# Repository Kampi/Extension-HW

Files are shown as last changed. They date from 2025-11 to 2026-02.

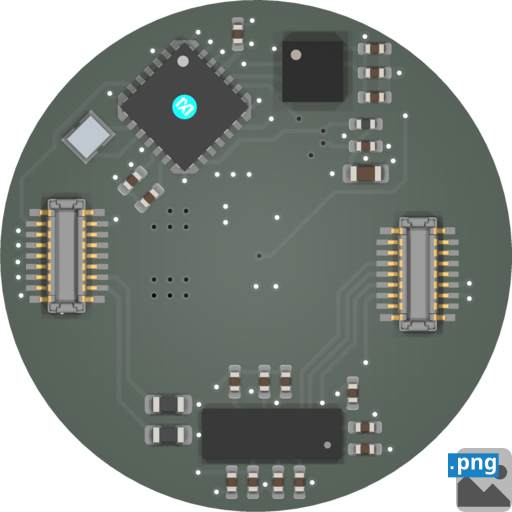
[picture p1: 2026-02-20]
production/extension-RELEASED/HTML/images/cat_png_3d_viewer_top_ZSWatch-Extension-top.png

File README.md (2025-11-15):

# ZSWatch-DevKit



## 📑 Table of Contents

- [ZSWatch-DevKit](#zswatch-devkit)
  - [📑 Table of Contents](#-table-of-contents)
  - [📖 About](#-about)
  - [📂 Directory Breakdown](#-directory-breakdown)
  - [Purchasing](#purchasing)
  - [👨‍💻 Maintainer](#-maintainer)

## 📖 About

The **ZSWatch-DevKit** project provides the hardware design and production files for a heartrate board tailored to the ZSWatch ecosystem.
It is built with **KiCad** and integrates a full **CI/CD pipeline** using **KiBot**, ensuring reproducible outputs for documentation, manufacturing, and releases.

Key features:

- 🛠️ Open-source hardware design
- 📦 Automated generation of Gerber, BoM, and documentation via KiBot
- 🔄 Workflow stages (DRAFT → PRELIMINARY → CHECKED → RELEASED) for structured releases
- 📝 Clear documentation and changelog to track progress
- 🌍 Designed with collaboration and transparency in mind

Please check the [wiki](https://github.com/ZSWatch/ZSWatch/wiki) for more information about the project.

## 📂 Directory Breakdown

- **`.github`**: GitHub related files
- **`.gitignore`**: Ignored files list
- **`devkit`**: KiCad project for the devkit
- **`production`**: Manufacturing outputs (Gerbers, documentation, etc.)
- **`CHANGELOG.md`**: Version history
- **`LICENSE`**: Project license (GPL-3.0)
- **`README.md`**: Project overview

## Purchasing

TBD

## 👨‍💻 Maintainer

- [Daniel Kampert](mailto:danielkameprt@kampis-elektroecke.de)

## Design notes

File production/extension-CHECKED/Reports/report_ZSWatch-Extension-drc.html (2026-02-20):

Logo

| DRC report for ZSWatch-Extension
| PCB: ZSWatch-Extension Revision: + (Unreleased) Date: 2026-02-20T15:14:23+0000 KiCad Version: 9.0.7 | Errors: 3 Warnings: 37 Total: 40

Violations

Type | Description | Details
clearance | Clearance violation (netclass 'Default' clearance 0.1000 mm; actual 0.0497 mm) | @(201.606169 mm, 143.268723 mm): Via [Net-(IC501-CS_{ACC})] on F.Cu - B.Cu @(200.402944 mm, 145.224264 mm): PCB text '+ (Unreleased)' on B.Cu
shorting_items | Items shorting two nets (nets and Net-(IC501-CS_{ACC})) | @(200.402944 mm, 145.224264 mm): PCB text '+ (Unreleased)' on B.Cu @(199.412994 mm, 147.487006 mm): Polygon [Net-(IC501-CS_{ACC})] on B.Cu
clearance | Clearance violation (netclass 'Default' clearance 0.1000 mm; actual 0.0000 mm) | @(200.402944 mm, 145.224264 mm): PCB text '+ (Unreleased)' on B.Cu @(182.7 mm, 132.5 mm): Zone [GND] on B.Cu, priority 8
lib_footprint_issues | The current configuration does not include the footprint library 'Amphenol'. | @(210.3 mm, 150.6 mm): Footprint X702
lib_footprint_mismatch | Footprint 'C_0201_0603Metric' does not match copy in library 'Capacitor_SMD'. | @(205.725 mm, 157.425 mm): Footprint C603
lib_footprint_mismatch | Footprint 'C_0201_0603Metric' does not match copy in library 'Capacitor_SMD'. | @(208.8925 mm, 143.2 mm): Footprint C505
lib_footprint_mismatch | Footprint 'C_0201_0603Metric' does not match copy in library 'Capacitor_SMD'. | @(208.175 mm, 154.505 mm): Footprint C608
lib_footprint_mismatch | Footprint 'L_0201_0603Metric' does not match copy in library 'Inductor_SMD'. | @(208.6 mm, 145.675 mm): Footprint R502
lib_footprint_mismatch | Footprint 'C_0201_0603Metric' does not match copy in library 'Capacitor_SMD'. | @(201.5 mm, 148.1 mm): Footprint C504
lib_footprint_mismatch | Footprint 'C_0201_0603Metric' does not match copy in library 'Capacitor_SMD'. | @(208.8925 mm, 143.993 mm): Footprint C506
lib_footprint_mismatch | Footprint 'C_0201_0603Metric' does not match copy in library 'Capacitor_SMD'. | @(200.941835 mm, 147.529739 mm): Footprint C502
lib_footprint_mismatch | Footprint 'C_0201_0603Metric' does not match copy in library 'Capacitor_SMD'. | @(204.4 mm, 142.72 mm): Footprint C503
lib_footprint_mismatch | Footprint 'C_0201_0603Metric' does not match copy in library 'Capacitor_SMD'. | @(205.975 mm, 154.125 mm): Footprint C602
lib_footprint_mismatch | Footprint 'L_0402_1005Metric' does not match copy in library 'Inductor_SMD'. | @(202.125001 mm, 154.875 mm): Footprint FB601
lib_footprint_issues | The current configuration does not include the footprint library 'Crystal_Kampi'. | @(199.5 mm, 146.1 mm): Footprint Y501
lib_footprint_mismatch | Footprint 'C_0402_1005Metric' does not match copy in library 'Capacitor_SMD'. | @(208.6 mm, 147.3 mm): Footprint C511
lib_footprint_issues | The current configuration does not include the footprint library 'Analog Devices'. | @(202.653033 mm, 145.111434 mm): Footprint IC501
lib_footprint_issues | The current configuration does not include the footprint library 'Package_BGA_Kampi'. | @(205.525 mm, 155.835 mm): Footprint IC601
lib_footprint_mismatch | Footprint 'C_0201_0603Metric' does not match copy in library 'Capacitor_SMD'. | @(206.425 mm, 157.425 mm): Footprint C604
lib_footprint_mismatch | Footprint 'L_0402_1005Metric' does not match copy in library 'Inductor_SMD'. | @(202.125001 mm, 155.875 mm): Footprint FB602
lib_footprint_mismatch | Footprint 'C_0201_0603Metric' does not match copy in library 'Capacitor_SMD'. | @(208.574999 mm, 156.345 mm): Footprint C610
lib_footprint_mismatch | Footprint 'LGA-12_2x2mm_P0.5mm' does not match copy in library 'Package_LGA'. | @(206.8625 mm, 143.95 mm): Footprint IC502
lib_footprint_mismatch | Footprint 'C_0201_0603Metric' does not match copy in library 'Capacitor_SMD'. | @(208.8925 mm, 144.793 mm): Footprint C507
lib_footprint_mismatch | Footprint 'C_0201_0603Metric' does not match copy in library 'Capacitor_SMD'. | @(204.2 mm, 157.425 mm): Footprint C606
lib_footprint_mismatch | Footprint 'C_0201_0603Metric' does not match copy in library 'Capacitor_SMD'. | @(204.3 mm, 154.125 mm): Footprint C601
lib_footprint_mismatch | Footprint 'C_0201_0603Metric' does not match copy in library 'Capacitor_SMD'. | @(205.275 mm, 154.125 mm): Footprint C605
lib_footprint_issues | The current configuration does not include the footprint library 'Amphenol'. | @(198.8 mm, 150.0 mm): Footprint X701
lib_footprint_mismatch | Footprint 'C_0201_0603Metric' does not match copy in library 'Capacitor_SMD'. | @(208.6 mm, 146.4 mm): Footprint C510
lib_footprint_mismatch | Footprint 'C_0201_0603Metric' does not match copy in library 'Capacitor_SMD'. | @(208.575 mm, 155.625 mm): Footprint C609
lib_footprint_mismatch | Footprint 'C_0201_0603Metric' does not match copy in library 'Capacitor_SMD'. | @(204.9 mm, 157.425 mm): Footprint C607
lib_footprint_mismatch | Footprint 'C_0201_0603Metric' does not match copy in library 'Capacitor_SMD'. | @(208.7 mm, 145.8 mm): Footprint C508
lib_footprint_mismatch | Footprint 'C_0201_0603Metric' does not match copy in library 'Capacitor_SMD'. | @(209.98 mm, 154.7 mm): Footprint C611
lib_footprint_issues | The current configuration does not include the footprint library 'Vishay'. | @(202.2 mm, 150.0 mm): Footprint D501
lib_footprint_mismatch | Footprint 'R_0201_0603Metric' does not match copy in library 'Resistor_SMD'. | @(209.98 mm, 155.5 mm): Footprint R601
lib_footprint_mismatch | Footprint 'R_0201_0603Metric' does not match copy in library 'Resistor_SMD'. | @(203.1 mm, 146.4 mm): Footprint R501
lib_footprint_mismatch | Footprint 'C_0201_0603Metric' does not match copy in library 'Capacitor_SMD'. | @(202.15 mm, 146.4 mm): Footprint C501
lib_footprint_mismatch | Footprint 'C_0201_0603Metric' does not match copy in library 'Capacitor_SMD'. | @(204.755 mm, 146.0 mm): Footprint C509
lib_footprint_issues | The current configuration does not include the footprint library 'Osram'. | @(205.0 mm, 150.0 mm): Footprint LED501
lib_footprint_issues | The current configuration does not include the footprint library 'Package_BGA_Kampi'. | @(206.8 mm, 146.1 mm): Footprint IC503
lib_footprint_issues | The current configuration does not include the footprint library 'Vishay'. | @(207.8 mm, 150.0 mm): Footprint D502

Generated by KiBot (https://github.com/INTI-CMNB/KiBot/) v1.8.5

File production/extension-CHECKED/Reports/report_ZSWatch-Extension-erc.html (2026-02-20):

Logo

| ERC report for ZSWatch-Extension
| Schematic: ZSWatch-Extension Revision: + (Unreleased) Date: 2026-02-20T15:14:21+0000 KiCad Version: 9.0.7 | Errors: 0 Warnings: 22 Total: 22

Sheet / (ZSWatch-Extension.kicad_sch)

Type | Description | Details
unresolved_variable | Unresolved text variable | @(0.2032 mm, 0.3175 mm): Text Box
unresolved_variable | Unresolved text variable | @(0.2286 mm, 0.3556 mm): Text Box
unresolved_variable | Unresolved text variable | @(0.8636 mm, 0.3175 mm): Text Box
unresolved_variable | Unresolved text variable | @(0.889 mm, 0.3556 mm): Text Box
unresolved_variable | Unresolved text variable | @(1.524 mm, 0.3175 mm): Text Box
unresolved_variable | Unresolved text variable | @(1.5494 mm, 0.3556 mm): Text Box
unresolved_variable | Unresolved text variable | @(2.1844 mm, 0.3175 mm): Text Box
unresolved_variable | Unresolved text variable | @(2.2098 mm, 0.3556 mm): Text Box
footprint_link_issues | The current configuration does not include the footprint library 'Crystal_Kampi'. | @(0.5715 mm, 0.8001 mm): Symbol Y501 [Crystal]
footprint_link_issues | The current configuration does not include the footprint library 'Analog Devices'. | @(0.8001 mm, 0.7112 mm): Symbol IC501 [MAX32664-SPI-TQFN]
lib_symbol_issues | The current configuration does not include the symbol library 'Analog Devices' | @(0.8001 mm, 0.7112 mm): Symbol IC501 [MAX32664-SPI-TQFN]
lib_symbol_issues | The current configuration does not include the symbol library 'ST' | @(1.4097 mm, 1.27 mm): Symbol IC502 [LIS2DS12]
footprint_link_issues | The current configuration does not include the footprint library 'Package_BGA_Kampi'. | @(2.0066 mm, 0.6604 mm): Symbol IC503 [MAX86141]
lib_symbol_issues | The current configuration does not include the symbol library 'Analog Devices' | @(2.0066 mm, 0.6604 mm): Symbol IC503 [MAX86141]
footprint_link_issues | The current configuration does not include the footprint library 'Vishay'. | @(2.2733 mm, 0.7239 mm): Symbol D501 [D_Photo]
footprint_link_issues | The current configuration does not include the footprint library 'Vishay'. | @(2.2733 mm, 0.762 mm): Symbol D502 [D_Photo]
footprint_link_issues | The current configuration does not include the footprint library 'Osram'. | @(2.5527 mm, 0.6731 mm): Symbol LED501 [SFH7016]
lib_symbol_issues | The current configuration does not include the symbol library 'Osram' | @(2.5527 mm, 0.6731 mm): Symbol LED501 [SFH7016]
footprint_link_issues | The current configuration does not include the footprint library 'Amphenol'. | @(1.0033 mm, 0.9525 mm): Symbol X702 [Conn_02x07_Top_Bottom]
footprint_link_issues | The current configuration does not include the footprint library 'Amphenol'. | @(1.8415 mm, 0.9525 mm): Symbol X701 [Conn_02x07_Top_Bottom]
footprint_link_issues | The current configuration does not include the footprint library 'Package_BGA_Kampi'. | @(1.4859 mm, 0.9017 mm): Symbol IC601 [DA7212-01UM2]
lib_symbol_issues | The current configuration does not include the symbol library 'Renesas' | @(1.4859 mm, 0.9017 mm): Symbol IC601 [DA7212-01UM2]

Generated by KiBot (https://github.com/INTI-CMNB/KiBot/) v1.8.5

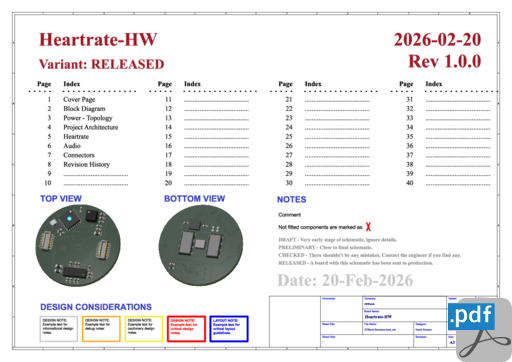
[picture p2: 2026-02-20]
production/extension-RELEASED/HTML/images/cat_pdf_schematic_ZSWatch-Extension-schematic.png

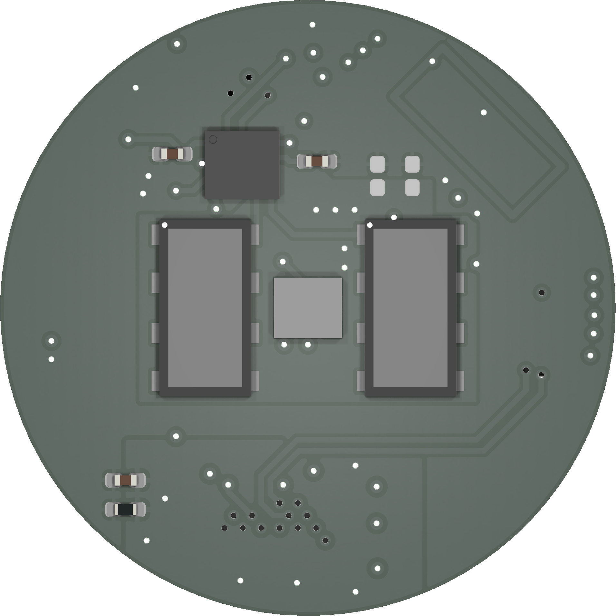
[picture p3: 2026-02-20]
production/extension-RELEASED/Images/ZSWatch-Extension-bottom.png

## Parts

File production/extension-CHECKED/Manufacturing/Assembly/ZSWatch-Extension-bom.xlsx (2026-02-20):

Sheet: BoM
Bill of Materials
Schematic: | ZSWatch-Extension | Component Groups: | 17
Variant: | CHECKED | Component Count: | 35 (35 SMD/ 0 THT)
Revision: |  | Fitted Components: | 35 (35 SMD/ 0 THT)
Date: | 2025-07-13 | Number of PCBs: | 1
KiCad Version: | 9.0.7+1 | Total Components: | 35
Row | Quantity Per PCB | References | Value | Datasheet | Footprint | Description | manf | manf#
1 | 4 | C506 C507 C510 C611 | 100n | https://datasheets.kyocera-avx.com/cx5r-KGM.pdf | C_0201_0603Metric | Unpolarized capacitor, small symbol | KYOCERA AVX | 0201ZD104KAT2A
2 | 11 | C502 C503 C504 C509 C601 C602 C603 C604 C608 C609 C610 | 1u | https://datasheets.kyocera-avx.com/x6s-dielectric.pdf | C_0201_0603Metric | Unpolarized capacitor, small symbol | KYOCERA AVX | 02016W105MAT2A
3 | 1 | C605 | 2u2 | https://datasheets.kyocera-avx.com/cx5r-KGM.pdf | C_0201_0603Metric | Unpolarized capacitor, small symbol | KYOCERA AVX | 0201ZD225MAT2A
4 | 2 | C606 C607 | 4u7 | https://www.mouser.de/datasheet/3/76/2/GRM035R60J475ME15_01A.pdf | C_0201_0603Metric | Unpolarized capacitor, small symbol | Murata | GRM035R60J475ME15D
5 | 2 | C505 C508 | 10u | https://datasheets.kyocera-avx.com/cx5r-KGM.pdf | C_0201_0603Metric | Unpolarized capacitor, small symbol | KYOCERA AVX | KGM03DR50G106MH
6 | 1 | C511 | 22u | https://datasheets.kyocera-avx.com/cx5r-KGM.pdf | C_0402_1005Metric | Unpolarized capacitor, small symbol | KYOCERA AVX | 04026D226MAT2A
7 | 2 | D501 D502 | VEMD8082 | https://www.vishay.com/docs/80381/vemd8082.pdf | VEMD808x | Photodiode | Vishay Semiconductors | VEMD8082
8 | 2 | FB601 FB602 | FerriteBead | https://www.mouser.de/datasheet/3/76/1/ENFA0018.pdf | L_0402_1005Metric | Ferrite bead | Murata | BLM15PD121SN1D
9 | 1 | IC601 | DA7212-01UM2 | https://www.renesas.com/en/document/dst/da7212-datasheet?r=1563326 | WLCSP-34 |  | Renesas / Dialog | DA7212-01UM2
10 | 1 | IC502 | LIS2DS12 | https://www.st.com/resource/en/datasheet/lis2ds12.pdf | LGA-12_2x2mm_P0.5mm |  | STMicroelectronics | LIS2DS12
11 | 1 | IC501 | MAX32664 | https://www.analog.com/media/en/technical-documentation/data-sheets/MAX32664.pdf | MAX32664GTG |  | Analog Devices / Maxim Integrated | MAX32664GTGC+
12 | 1 | IC503 | MAX86141 | https://www.analog.com/media/en/technical-documentation/data-sheets/max86140-max86141.pdf | THIN-WLP-20_2.228x1.967mm_P0.4mm |  | Analog Devices / Maxim Integrated | MAX86141ENP+T
13 | 1 | LED501 | SFH7016 | https://look.ams-osram.com/m/1a73f8d425cfcc40/original/SFH-7016.pdf | SFH7016 |  | ams OSRAM | SFH 7016
14 | 1 | R601 | 0R | https://www.mouser.de/datasheet/3/508/1/PYu-RC_Group_51_RoHS_L_12.pdf | R_0201_0603Metric | Resistor, small symbol | YAGEO | 603-RC0201FR-SNE96L
15 | 1 | R502 | 4k7 | https://www.vishay.com/doc?20052 | L_0201_0603Metric | Resistor, small symbol | Vishay | CRCW020147K5FNED
16 | 2 | X701 X702 | MB2 | https://cdn.amphenol-cs.com/media/wysiwyg/files/drawing/101p014fb110.pdf | 101P014FB110 | Generic connector, double row, 02x07, top/bottom pin numbering scheme (row 1: 1...pins_per_row, row2: pins_per_row+1 ... num_pins), script generated (kicad-library-utils/schlib/autogen/connector/) | Amphenol Aorora | 101P014FB110
17 | 1 | Y501 | 32kHz | https://www.mouser.de/datasheet/3/294/1/ECX-1210.pdf | ECS_ECX-1210 | Two pin crystal | ECS | ECS-.327-6-1210-TR

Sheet: Costs
Bill of Materials
Schematic: | ZSWatch-Extension |  |  |  |  | Board Qty: | 1
Variant: | CHECKED |  |  |  |  | Unit Cost: | $0.00
Revision: |  |  |  |  |  | Total Cost: | $0.00 |  |  |  |  | $0.00 | 0 of 17 parts found
Date: | 2025-07-13
KiCad Version: | 9.0.7+1
Global Part Info |  |  |  |  |  |  |  | Mouser
References | Value | Footprint | Manf | Manf# | Build Quantity | Unit$ | Ext$ | Avail | Purch | Unit$ | MOQ | Ext$ | Cat#
C506 C507 C510 C611 | 100n | C_0201_0603Metric | KYOCERA AVX | 0201ZD104KAT2A (https://datasheets.kyocera-avx.com/cx5r-KGM.pdf) | 4
C502 C503 C504 C509 C601 C602 C603 C604 C608 C609 C610 | 1u | C_0201_0603Metric | KYOCERA AVX | 02016W105MAT2A (https://datasheets.kyocera-avx.com/x6s-dielectric.pdf) | 11
C605 | 2u2 | C_0201_0603Metric | KYOCERA AVX | 0201ZD225MAT2A (https://datasheets.kyocera-avx.com/cx5r-KGM.pdf) | 1
C606 C607 | 4u7 | C_0201_0603Metric | Murata | GRM035R60J475ME15D (https://www.mouser.de/datasheet/3/76/2/GRM035R60J475ME15_01A.pdf) | 2
C505 C508 | 10u | C_0201_0603Metric | KYOCERA AVX | KGM03DR50G106MH (https://datasheets.kyocera-avx.com/cx5r-KGM.pdf) | 2
C511 | 22u | C_0402_1005Metric | KYOCERA AVX | 04026D226MAT2A (https://datasheets.kyocera-avx.com/cx5r-KGM.pdf) | 1
D501 D502 | VEMD8082 | VEMD808x | Vishay Semiconductors | VEMD8082 (https://www.vishay.com/docs/80381/vemd8082.pdf) | 2
FB601 FB602 | FerriteBead | L_0402_1005Metric | Murata | BLM15PD121SN1D (https://www.mouser.de/datasheet/3/76/1/ENFA0018.pdf) | 2
IC601 | DA7212-01UM2 | WLCSP-34 | Renesas / Dialog | DA7212-01UM2 (https://www.renesas.com/en/document/dst/da7212-datasheet?r=1563326) | 1
IC502 | LIS2DS12 | LGA-12_2x2mm_P0.5mm | STMicroelectronics | LIS2DS12 (https://www.st.com/resource/en/datasheet/lis2ds12.pdf) | 1
IC501 | MAX32664 | MAX32664GTG | Analog Devices / Maxim Integrated | MAX32664GTGC+ (https://www.analog.com/media/en/technical-documentation/data-sheets/MAX32664.pdf) | 1
IC503 | MAX86141 | THIN-WLP-20_2.228x1.967mm_P0.4mm | Analog Devices / Maxim Integrated | MAX86141ENP+T (https://www.analog.com/media/en/technical-documentation/data-sheets/max86140-max86141.pdf) | 1
LED501 | SFH7016 | SFH7016 | ams OSRAM | SFH 7016 (https://look.ams-osram.com/m/1a73f8d425cfcc40/original/SFH-7016.pdf) | 1
R601 | 0R | R_0201_0603Metric | YAGEO | 603-RC0201FR-SNE96L (https://www.mouser.de/datasheet/3/508/1/PYu-RC_Group_51_RoHS_L_12.pdf) | 1
R502 | 4k7 | L_0201_0603Metric | Vishay | CRCW020147K5FNED (https://www.vishay.com/doc?20052) | 1
X701 X702 | MB2 | 101P014FB110 | Amphenol Aorora | 101P014FB110 (https://cdn.amphenol-cs.com/media/wysiwyg/files/drawing/101p014fb110.pdf) | 2
Y501 | 32kHz | ECS_ECX-1210 | ECS | ECS-.327-6-1210-TR (https://www.mouser.de/datasheet/3/294/1/ECX-1210.pdf) | 1
 |  |  |  |  |  | Total Purchase: | $0.00 | Buy here (https://mouser.com/bom/) |  |  |  | $0.00
Created: | 2026-02-20 15:18:24 |  |  |  |  | Purchase description:
KiCost® v1.1.20 + KiBot v1.8.5

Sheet: Colors
Columns colors
KiCad Fields (default)
Generated Fields
User Fields
Empty Fields
Costs sheet colors
Best price
No manufacturer or distributor code
Not available
Purchase quantity is more than what is available
Minimum order quantity not respected
Total available part quantity is less than needed
Total purchased part quantity is less than needed
This part is obsolete
This part is listed but is not normally stocked

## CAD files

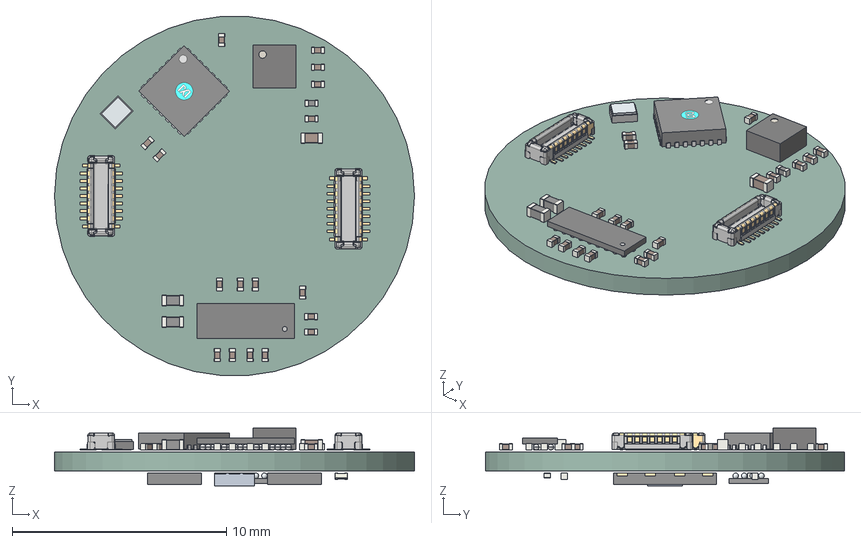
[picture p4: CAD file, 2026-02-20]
production/extension-CHECKED/3D/ZSWatch-Extension.step
16.8 x 16.8 x 2.69 mm
BW93_SERIES x 2
C_0201_0603Metric x 20
L_0201_0603Metric
L_0402_1005Metric x 2
solidBody
solidTop1
solidLead
C_0402_1005Metric
MAXIM_90-100089
DA7212-01UM2
LGA-12_2x2mm_P0.5mm
VEMD8080 x 2
R_0201_0603Metric
SFH7016
kibot_uxdiau0i_PCB

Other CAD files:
production/extension-PRELIMINARY/3D/ZSWatch-Extension.step
production/extension-RELEASED/3D/ZSWatch-Extension.step

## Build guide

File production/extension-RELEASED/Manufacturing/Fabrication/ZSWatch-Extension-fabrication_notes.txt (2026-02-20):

FABRICATION NOTES (UNLESS OTHERWISE SPECIFIED)

1)	FABRICATE PER IPC-6012A CLASS 2.

2)	OUTLINE DEFINED IN SEPARATE GERBER FILE WITH
	"Edge_Cuts.GBR" SUFFIX.

	DIMENSIONS OF CIRCUMSIZED RECTANGLE SHOWN ON THIS
	DRAWING FOR REFERENCE ONLY.

3)	SEE SEPARATE DRILL FILES WITH ".DRL" SUFFIX 
	FOR HOLE LOCATIONS.

	SELECTED HOLE LOCATIONS SHOWN ON THIS DRAWING 
	FOR REFERENCE ONLY.

4)	SURFACE FINISH: HAL SNPB

5)	SOLDERMASK ON BOTH SIDES OF THE BOARD SHALL 
	BE LPI, COLOR GREEN.

6)	SILK SCREEN LEGEND TO BE APPLIED PER LAYER 
	STACKUP USING BLACK NON-CONDUCTIVE EPOXY INK.

7)	ALL VIAS ARE TENTED ON BOTH SIDES UNLESS 
	SOLDERMASK OPENED IN GERBER.

8)	VENDOR SHOULD FOLLOW ROHS COMPLIANT PROCESS 
	AND Pb FREE FOR MANUFACTURING

9)	PCB MATERIAL REQUIREMENTS:

	A.	FLAMMABILITY RATING MUST MEET OR EXCEED 
		UL94V-0 REQUIREMENTS.
	B.	Tg 150 C OR EQUIVALENT.
	C.	EQUIVALENT MATERIAL SHALL BE RoHS COMPLIANT, 
		HALOGEN FREE AND APPROVED BY ZSWATCH.

10)	DESIGN GEOMETRY MINIMUM FEATURE SIZES:

	BOARD SIZE				16.800 × 16.800 mm
	BOARD THICKNESS		0.982 mm
	TRACE WIDTH			0.150 mm
	TRACE TO TRACE		0.100 mm
	MIN. HOLE (PTH)			0.150 mm
	MIN. HOLE (NPTH)		N/A mm
	ANNULAR RING			0.076 mm
	COPPER TO HOLE		0.100 mm
	COPPER TO EDGE		0.100 mm
	HOLE TO HOLE			0.100 mm

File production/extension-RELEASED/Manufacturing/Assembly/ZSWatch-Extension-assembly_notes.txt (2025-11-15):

ASSEMBLY NOTES (UNLESS OTHERWISE SPECIFIED)

1)	DO NOT POPULATE PARTS ARE MARKED WITH A RED CROSS.

2)	DO NOT POPULATE PARTS ARE NOT PRESENT IN THE BOM.

3)	IF CONFLICTING INFORMATION IS FOUND BETWEEN THE ASSEMBLY
	FILE AND BOM, BOM SHOULD BE USED AS THE MAIN SOURCE.

4)	CONFORMAL COATING IS NOT REQUIRED.

5)	DOT IDENTIFIES PIN #1 LOCATION AND DEVICE ORIENTATION
	WHEN VIEWED FROM THE TOP.

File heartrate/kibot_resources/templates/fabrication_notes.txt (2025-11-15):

FABRICATION NOTES (UNLESS OTHERWISE SPECIFIED)

1)	FABRICATE PER IPC-6012A CLASS 2.

2)	OUTLINE DEFINED IN SEPARATE GERBER FILE WITH
	"Edge_Cuts.GBR" SUFFIX.

	DIMENSIONS OF CIRCUMSIZED RECTANGLE SHOWN ON THIS
	DRAWING FOR REFERENCE ONLY.

3)	SEE SEPARATE DRILL FILES WITH ".DRL" SUFFIX 
	FOR HOLE LOCATIONS.

	SELECTED HOLE LOCATIONS SHOWN ON THIS DRAWING 
	FOR REFERENCE ONLY.

4)	SURFACE FINISH: ${pcb_finish_cap}

5)	SOLDERMASK ON BOTH SIDES OF THE BOARD SHALL 
	BE LPI, COLOR ${solder_mask_color_text_cap}.

6)	SILK SCREEN LEGEND TO BE APPLIED PER LAYER 
	STACKUP USING ${silk_screen_color_text_cap} NON-CONDUCTIVE EPOXY INK.

7)	ALL VIAS ARE TENTED ON BOTH SIDES UNLESS 
	SOLDERMASK OPENED IN GERBER.

8)	VENDOR SHOULD FOLLOW ROHS COMPLIANT PROCESS 
	AND Pb FREE FOR MANUFACTURING

9)	PCB MATERIAL REQUIREMENTS:

	A.	FLAMMABILITY RATING MUST MEET OR EXCEED 
		UL94V-0 REQUIREMENTS.
	B.	Tg 150 C OR EQUIVALENT.
	C.	EQUIVALENT MATERIAL SHALL BE RoHS COMPLIANT, 
		HALOGEN FREE AND APPROVED BY ${COMPANY_cap}.

10)	DESIGN GEOMETRY MINIMUM FEATURE SIZES:

	BOARD SIZE				${bb_w_mm} × ${bb_h_mm} mm
	BOARD THICKNESS		${thickness_mm} mm
	TRACE WIDTH			${track_mm} mm
	TRACE TO TRACE		${clearance_mm} mm
	MIN. HOLE (PTH)			${drill_pth_real_mm} mm
	MIN. HOLE (NPTH)		${drill_npth_real_mm} mm
	ANNULAR RING			${oar_mm} mm
	COPPER TO HOLE		${c2h_mm} mm
	COPPER TO EDGE		${c2e_mm} mm
	HOLE TO HOLE			${h2h_mm} mm
#?stackup and impedance_controlled

#?stackup and impedance_controlled
11)	REFER TO IMPEDANCE TABLE FOR IMPEDANCE CONTROL REQUIREMENTS.
#?stackup and impedance_controlled

#?stackup and impedance_controlled
12)	CONFIRM SPACE WIDTHS AND SPACINGS.

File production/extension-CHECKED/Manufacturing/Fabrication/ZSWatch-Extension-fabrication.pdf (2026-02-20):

# Top Fabrication (Scale 1:1)

# Heartrate-HW Fabrication Document

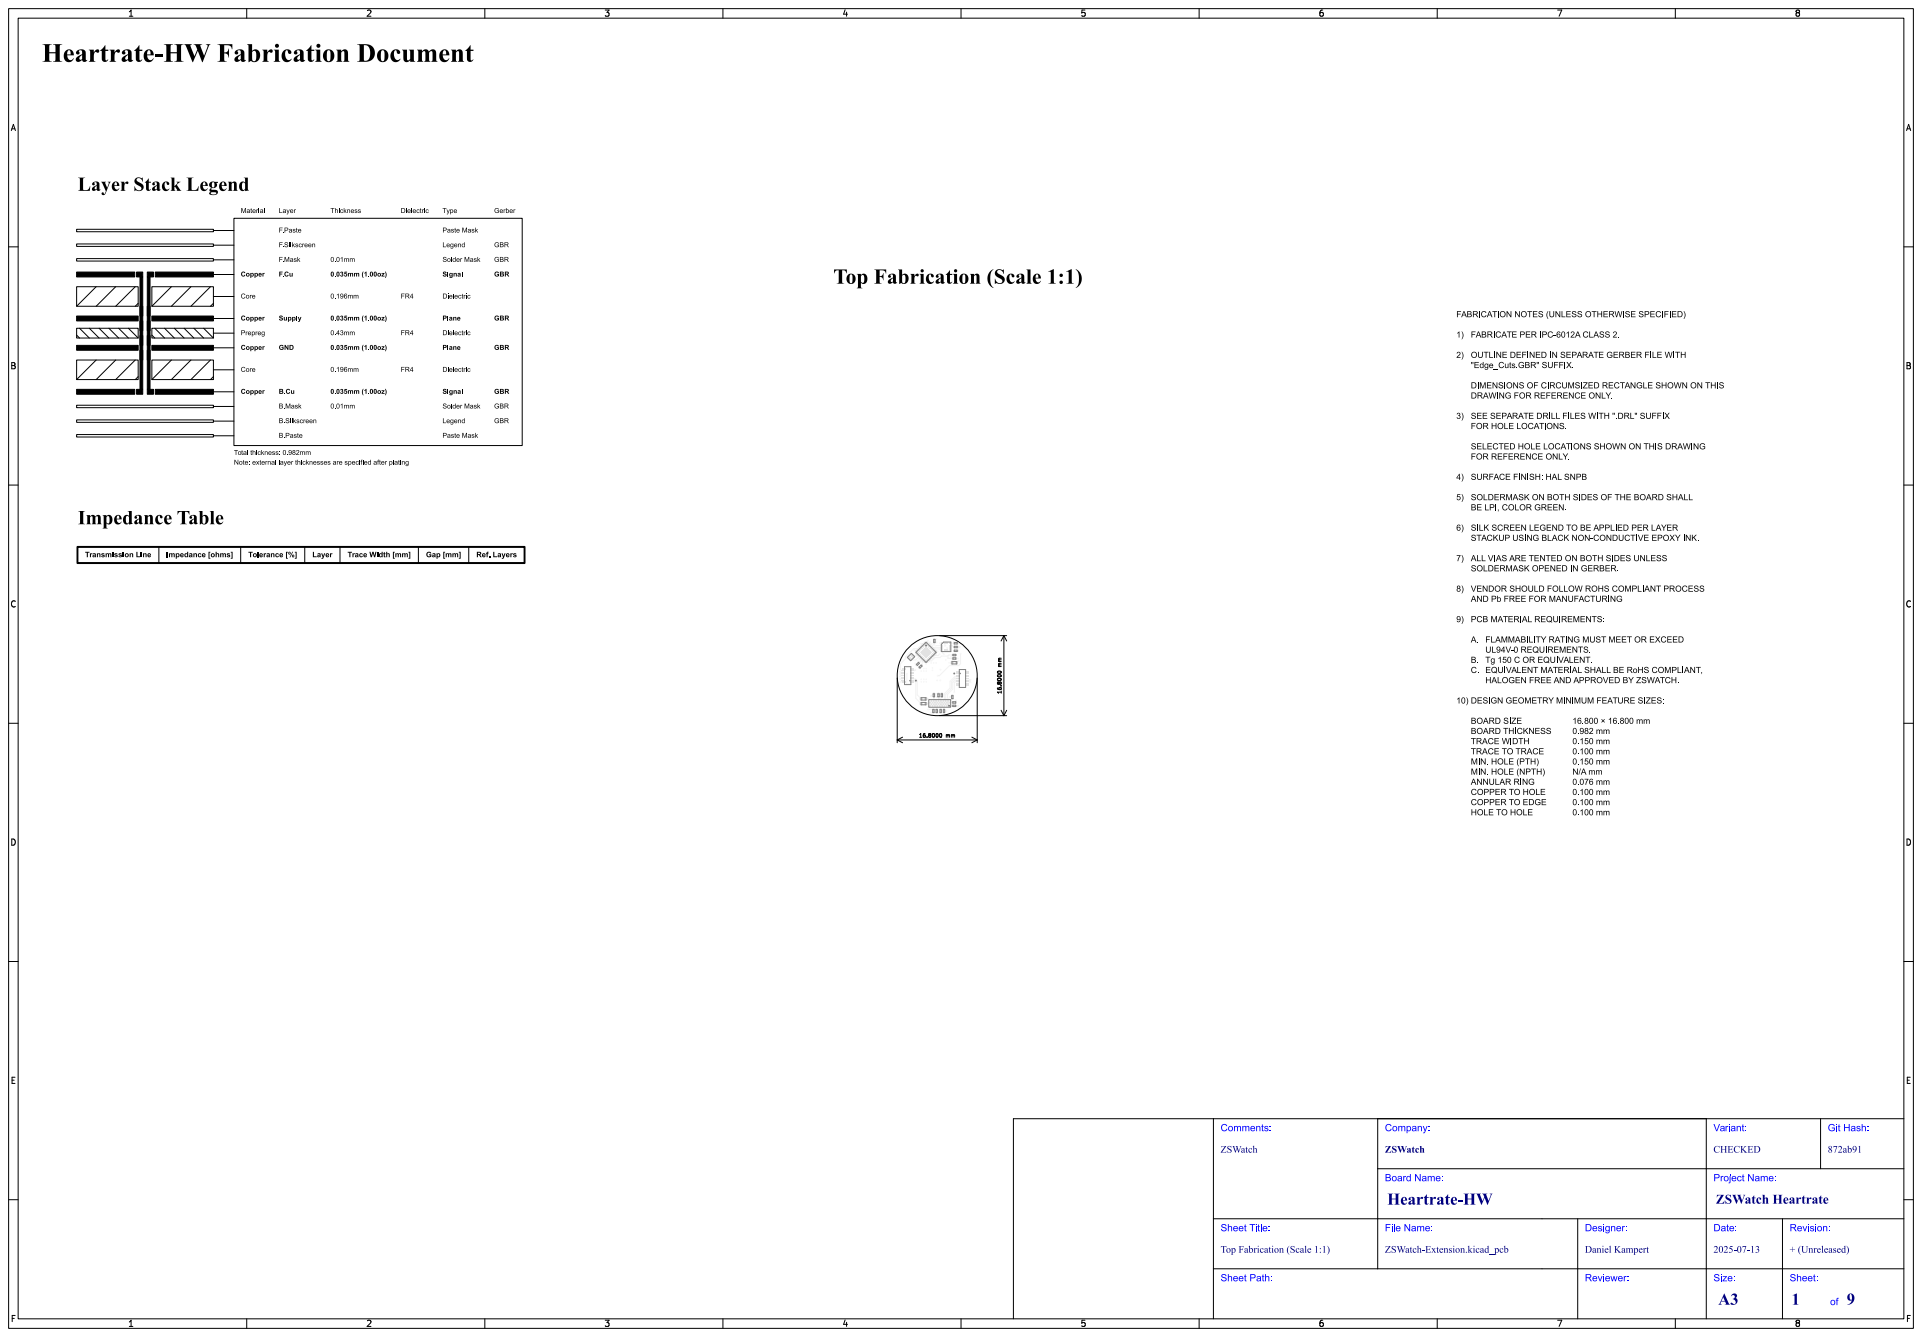
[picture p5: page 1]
Git Hash:; ZSWatch; Comments:; Sheet Path:; Sheet Title:; File Name:; Heartrate-HW; ZSWatch Heartrate; Company:; CHECKED; Variant:; Board Name:; ZSWatch-Extension.kicad_pcb; Daniel Kampert; Designer:; Reviewer:; Project Name:; Date:; + (Unreleased); Revision:; Size:; Sheet:

Top Fabrication (Scale 1:1)

# Bottom Fabrication (Scale 1:1)

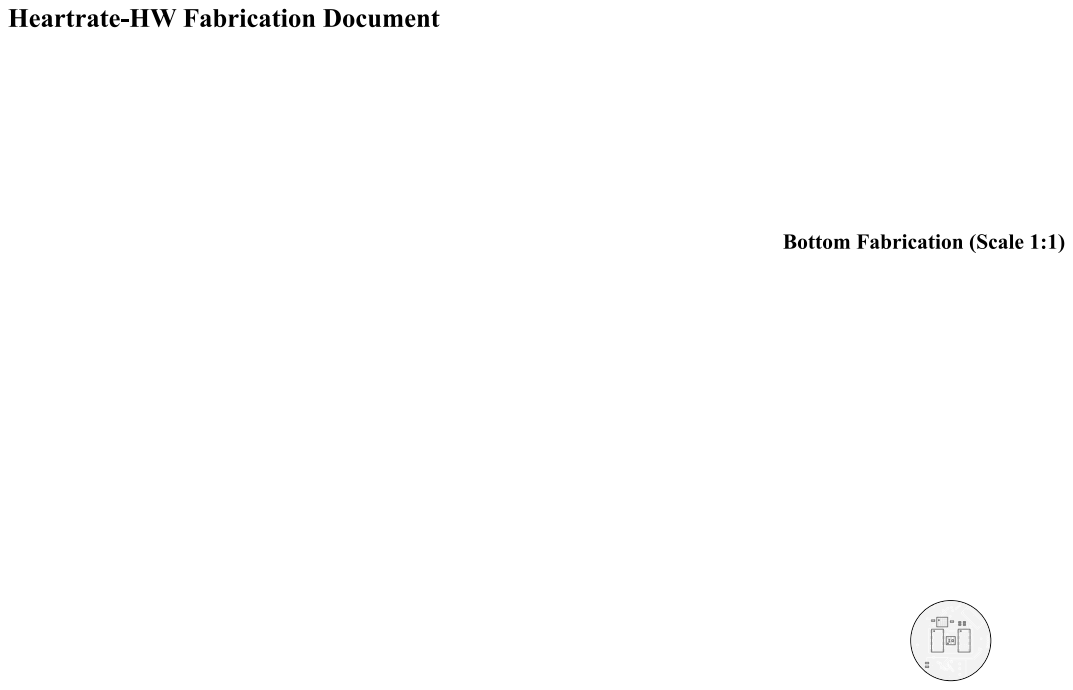
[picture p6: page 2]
Git; Hash:; ZSWatch; Comments:; Sheet Title:; File Name:; Heartrate-HW; ZSWatch Heartrate; Company:; CHECKED; Variant:; Board Name:; ZSWatch-Extension.kicad_pcb; Daniel Kampert; Designer:; Project Name:; Date:; + (Unreleased); Revision:

Bottom Fabrication (Scale 1:1)

# Drill Drawing L1 - L4 (Scale 1:1)

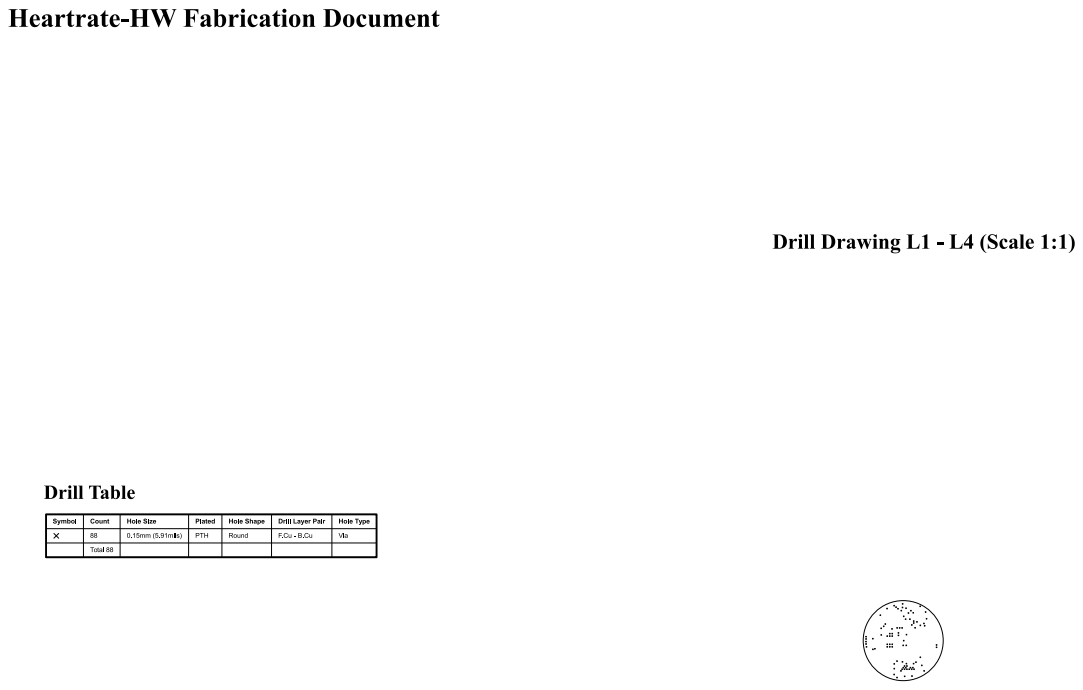
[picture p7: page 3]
Git; Hash:; ZSWatch; Comments:; Drill Drawing (L1 - L4); Sheet Title:; File Name:; Heartrate-HW; ZSWatch Heartrate; Company:; CHECKED; Variant:; Board Name:; ZSWatch-Extension.kicad_pcb; Daniel Kampert; Designer:; Project Name:; Date:; + (Unreleased); Revision:

# Top Test Points (Scale 1:1)

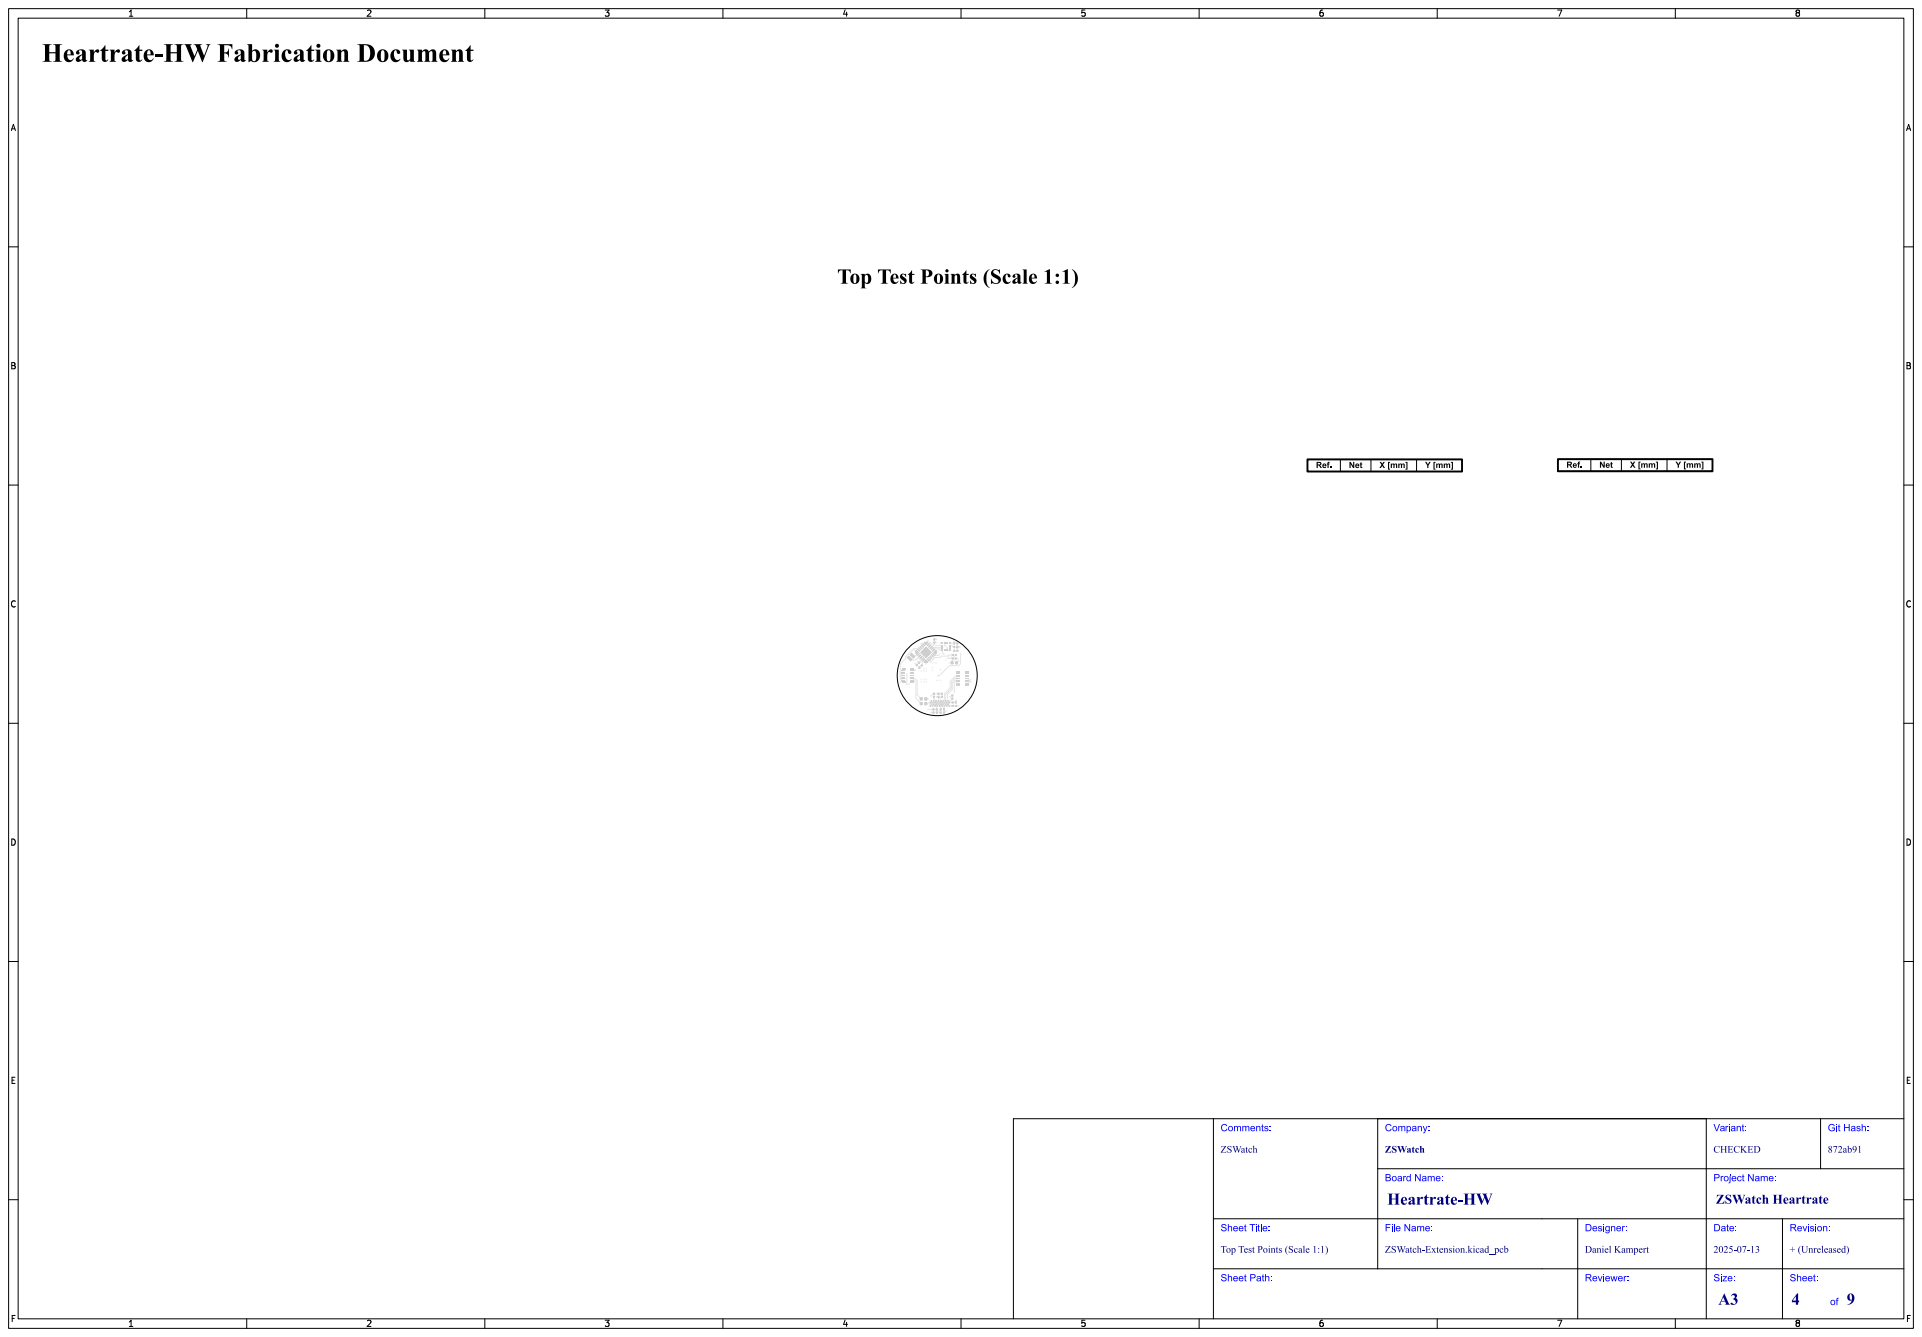
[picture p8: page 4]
Git; Hash:; ZSWatch; Comments:; Sheet Title:; File Name:; Heartrate-HW; ZSWatch Heartrate; Company:; CHECKED; Variant:; Board Name:; ZSWatch-Extension.kicad_pcb; Daniel Kampert; Designer:; Project Name:; Date:; + (Unreleased); Revision:

Top Test Points (Scale 1:1)

# Bottom Test Points (Scale 1:1)

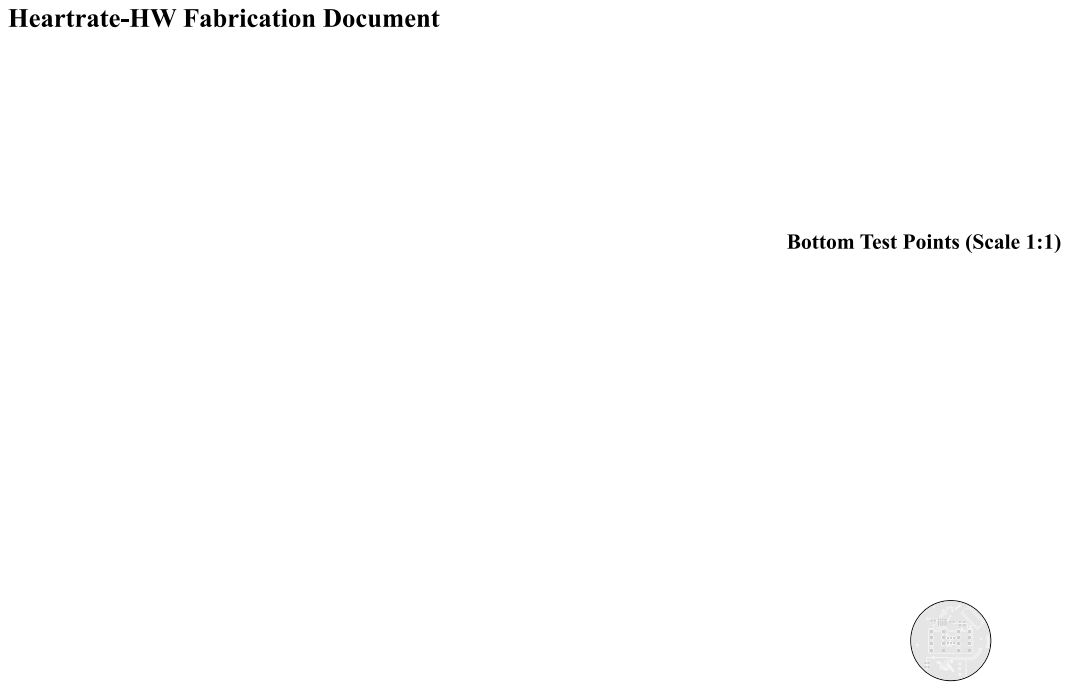
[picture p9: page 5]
Git; Hash:; ZSWatch; Comments:; Sheet Title:; File Name:; Heartrate-HW; ZSWatch Heartrate; Company:; CHECKED; Variant:; Board Name:; ZSWatch-Extension.kicad_pcb; Daniel Kampert; Designer:; Project Name:; Date:; + (Unreleased); Revision:

Bottom Test Points (Scale 1:1)

# F.Cu (Scale 1:1)

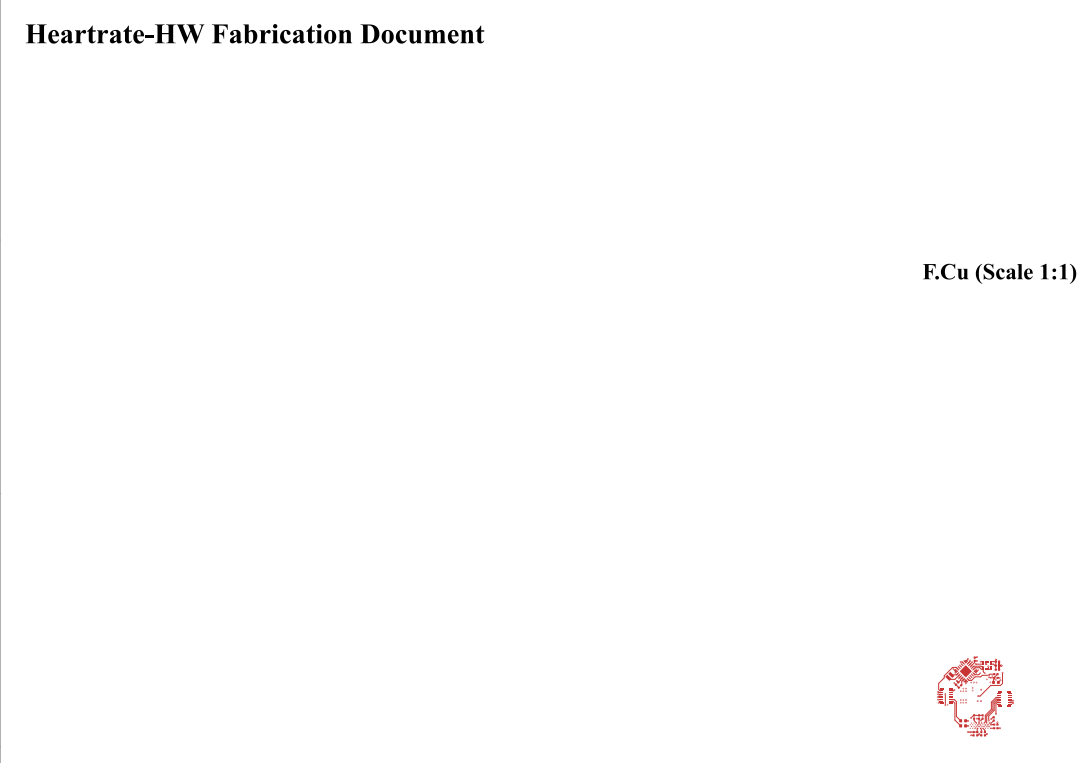
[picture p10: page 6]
Git; Hash:; ZSWatch; Comments:; F.Cu (Scale 1:1); Sheet Title:; File Name:; Heartrate-HW; ZSWatch Heartrate; Company:; CHECKED; Variant:; Board Name:; ZSWatch-Extension.kicad_pcb; Daniel Kampert; Designer:; Project Name:; Date:; + (Unreleased); Revision:

# Supply (Scale 1:1)

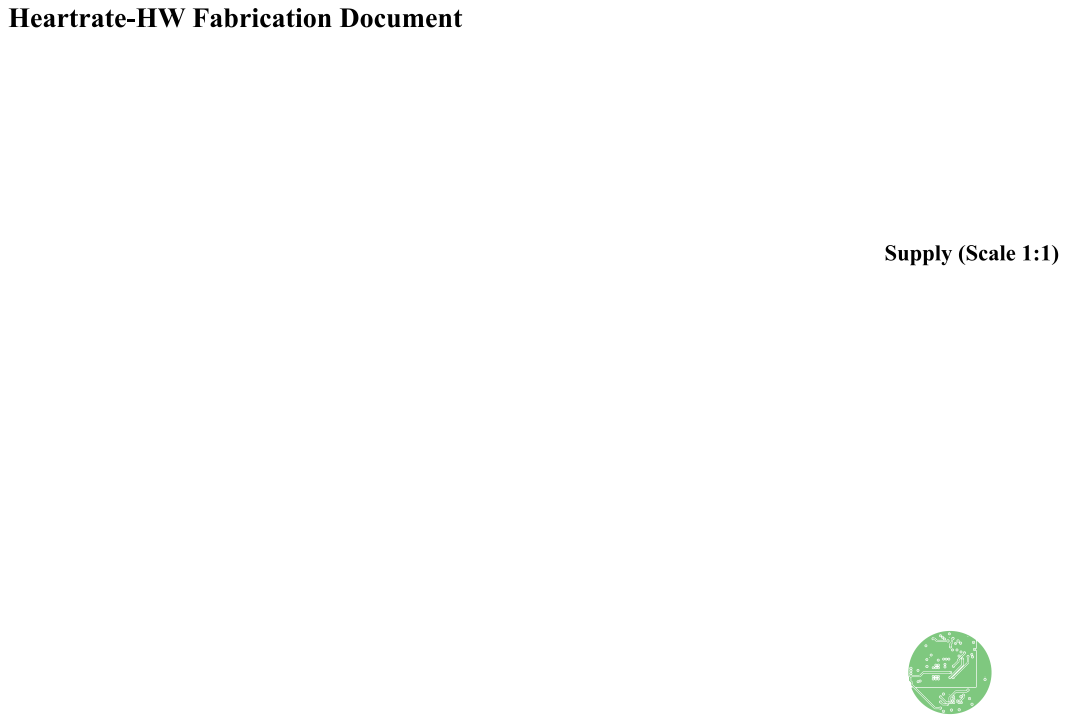
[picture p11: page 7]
Git; Hash:; ZSWatch; Comments:; Supply (Scale 1:1); Sheet Title:; File Name:; Heartrate-HW; ZSWatch Heartrate; Company:; CHECKED; Variant:; Board Name:; ZSWatch-Extension.kicad_pcb; Daniel Kampert; Designer:; Project Name:; Date:; + (Unreleased); Revision:

# GND (Scale 1:1)

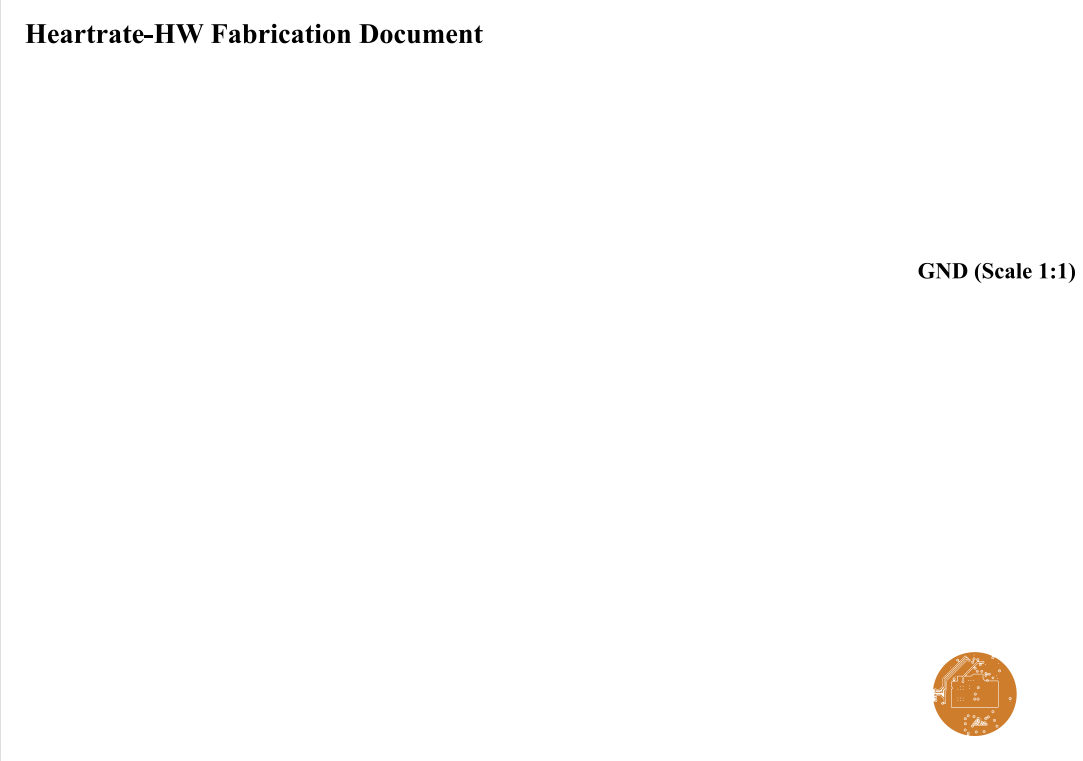
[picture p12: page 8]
Git; Hash:; ZSWatch; Comments:; GND (Scale 1:1); Sheet Title:; File Name:; Heartrate-HW; ZSWatch Heartrate; Company:; CHECKED; Variant:; Board Name:; ZSWatch-Extension.kicad_pcb; Daniel Kampert; Designer:; Project Name:; Date:; + (Unreleased); Revision:

# B.Cu (Scale 1:1)

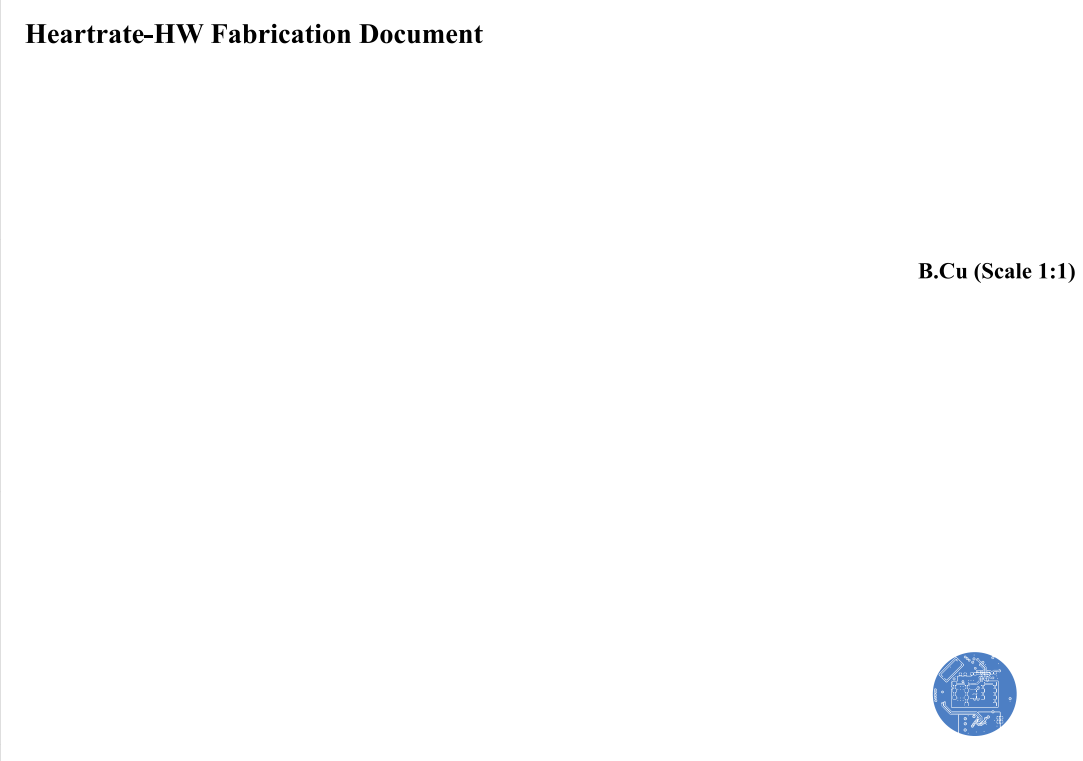
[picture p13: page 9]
Git; Hash:; ZSWatch; Comments:; B.Cu (Scale 1:1); Sheet Title:; File Name:; Heartrate-HW; ZSWatch Heartrate; Company:; CHECKED; Variant:; Board Name:; ZSWatch-Extension.kicad_pcb; Daniel Kampert; Designer:; Project Name:; Date:; + (Unreleased); Revision:

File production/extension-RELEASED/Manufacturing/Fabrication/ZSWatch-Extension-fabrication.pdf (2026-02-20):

# Top Fabrication (Scale 1:1)

# Heartrate-HW Fabrication Document

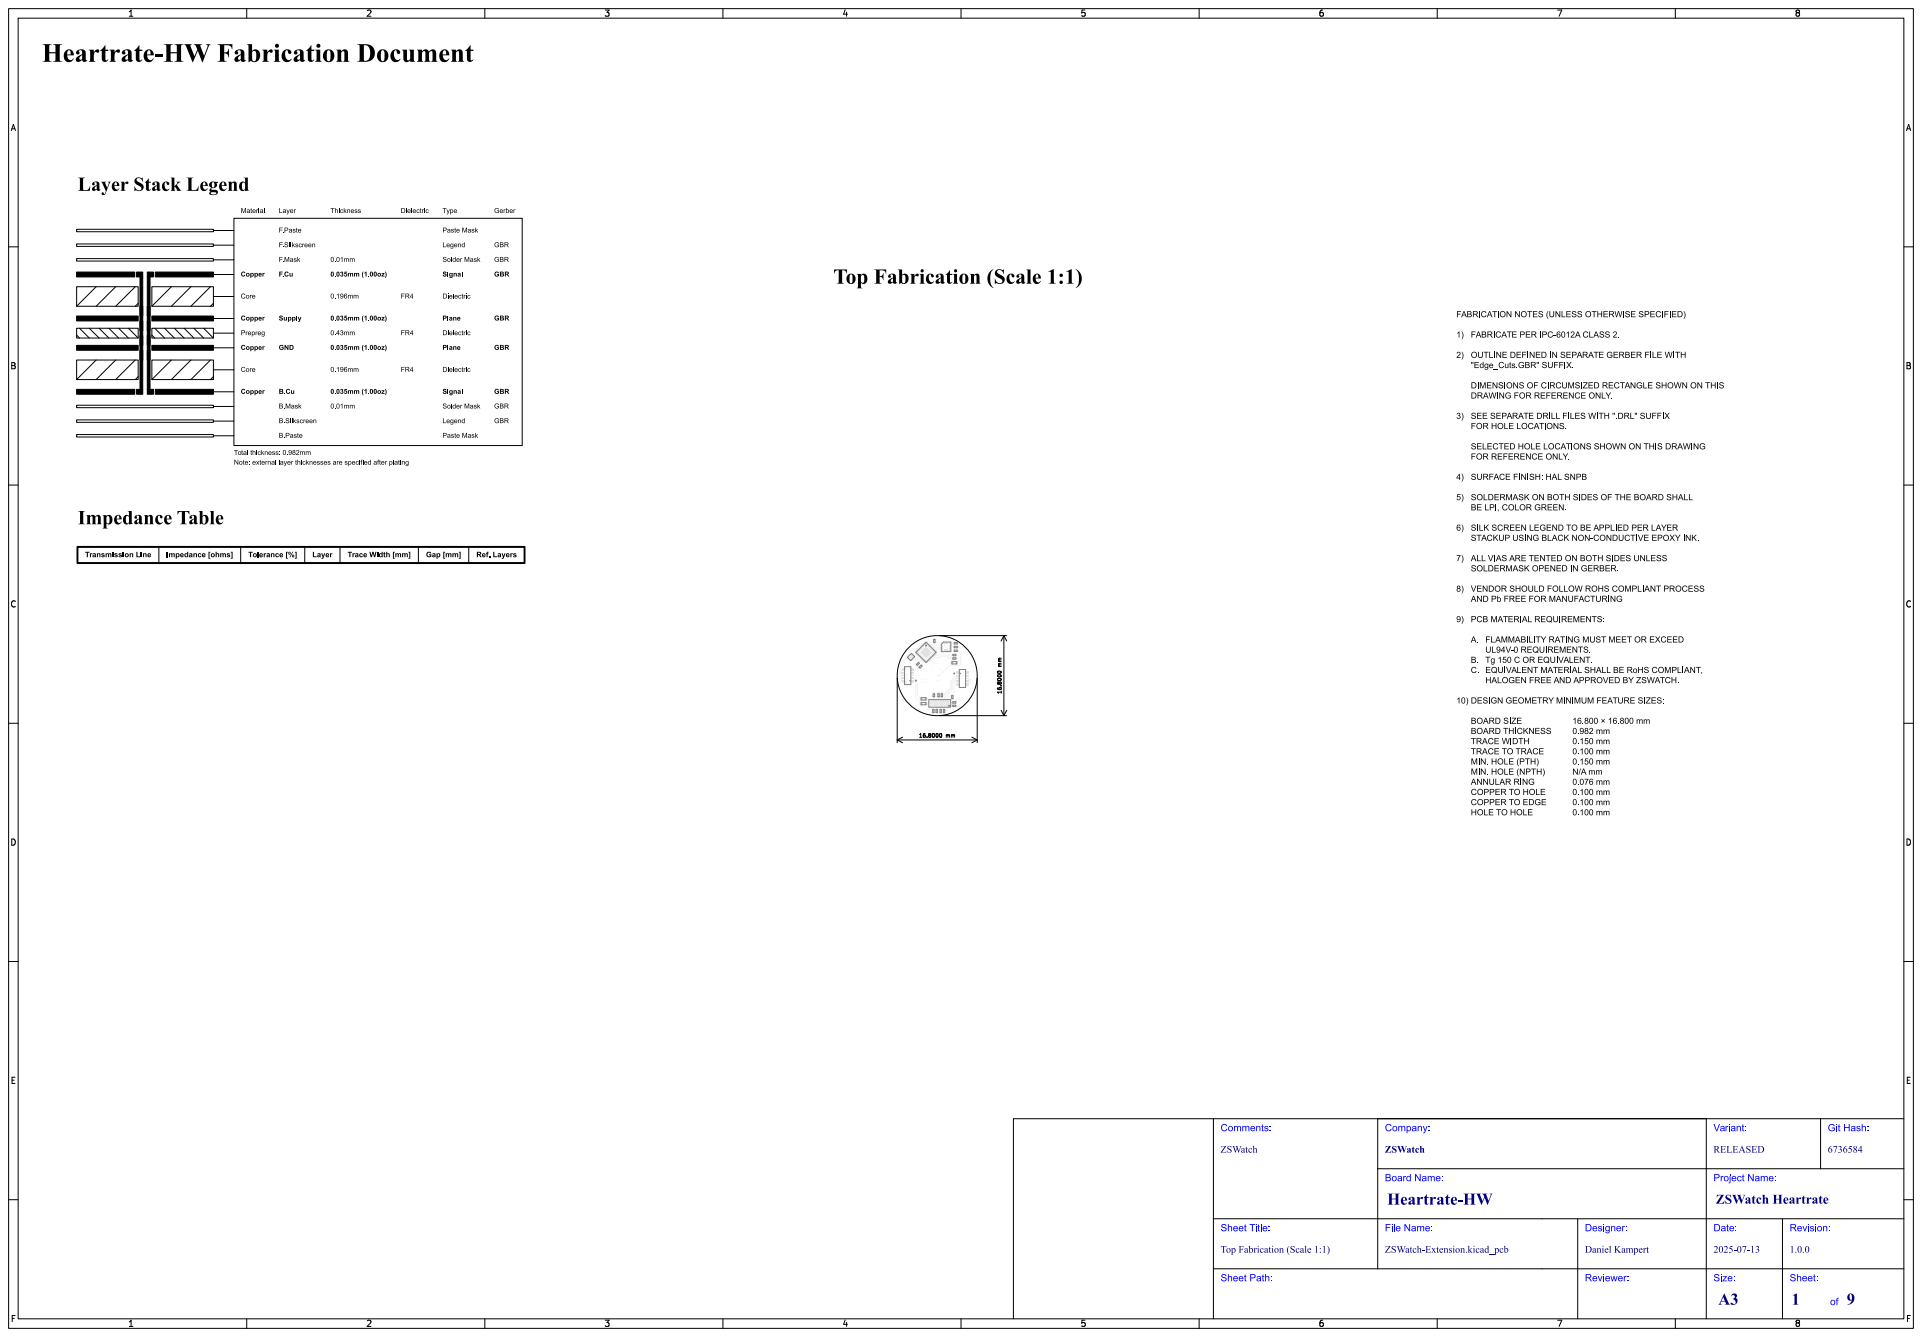
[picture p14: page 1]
Git Hash:; ZSWatch; Comments:; Sheet Path:; Sheet Title:; File Name:; Heartrate-HW; ZSWatch Heartrate; Company:; RELEASED; Variant:; Board Name:; ZSWatch-Extension.kicad_pcb; Daniel Kampert; Designer:; Reviewer:; Project Name:; Date:; Revision:; Size:; Sheet:

Top Fabrication (Scale 1:1)

# Bottom Fabrication (Scale 1:1)

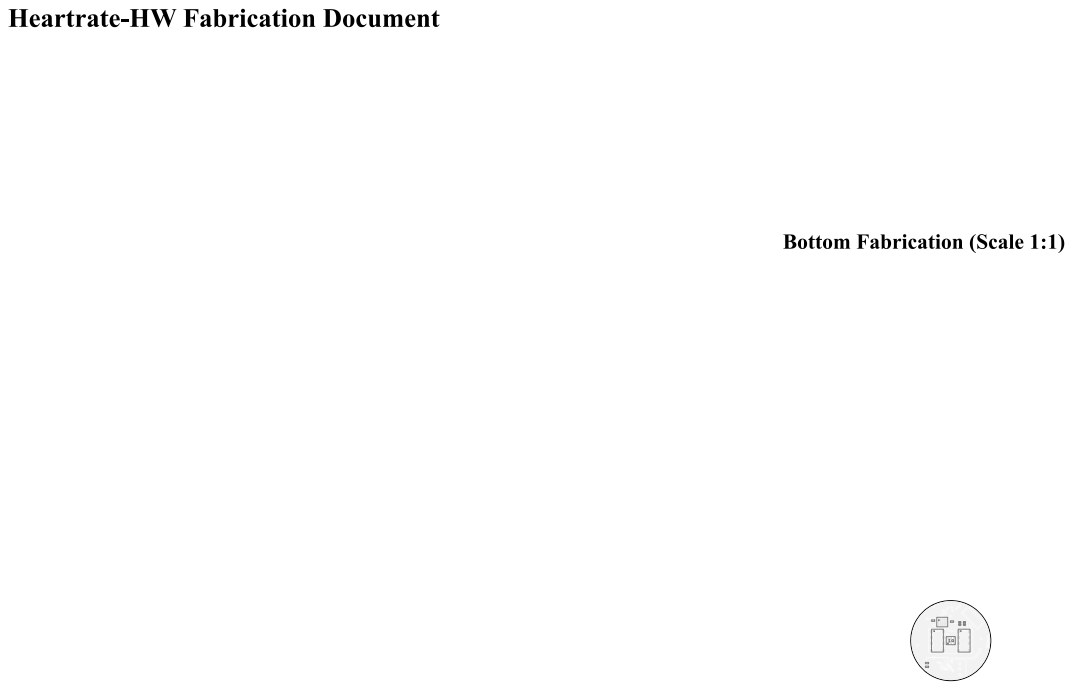
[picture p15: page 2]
Git; Hash:; ZSWatch; Comments:; Sheet Title:; File Name:; Heartrate-HW; ZSWatch Heartrate; Company:; RELEASED; Variant:; Board Name:; ZSWatch-Extension.kicad_pcb; Daniel Kampert; Designer:; Project Name:; Date:; Revision:

Bottom Fabrication (Scale 1:1)

# Drill Drawing L1 - L4 (Scale 1:1)

Git; Hash:; ZSWatch; Comments:; Drill Drawing (L1 - L4); Sheet Title:; File Name:; Heartrate-HW; ZSWatch Heartrate; Company:; RELEASED; Variant:; Board Name:; ZSWatch-Extension.kicad_pcb; Daniel Kampert; Designer:; Project Name:; Date:; Revision:

# Top Test Points (Scale 1:1)

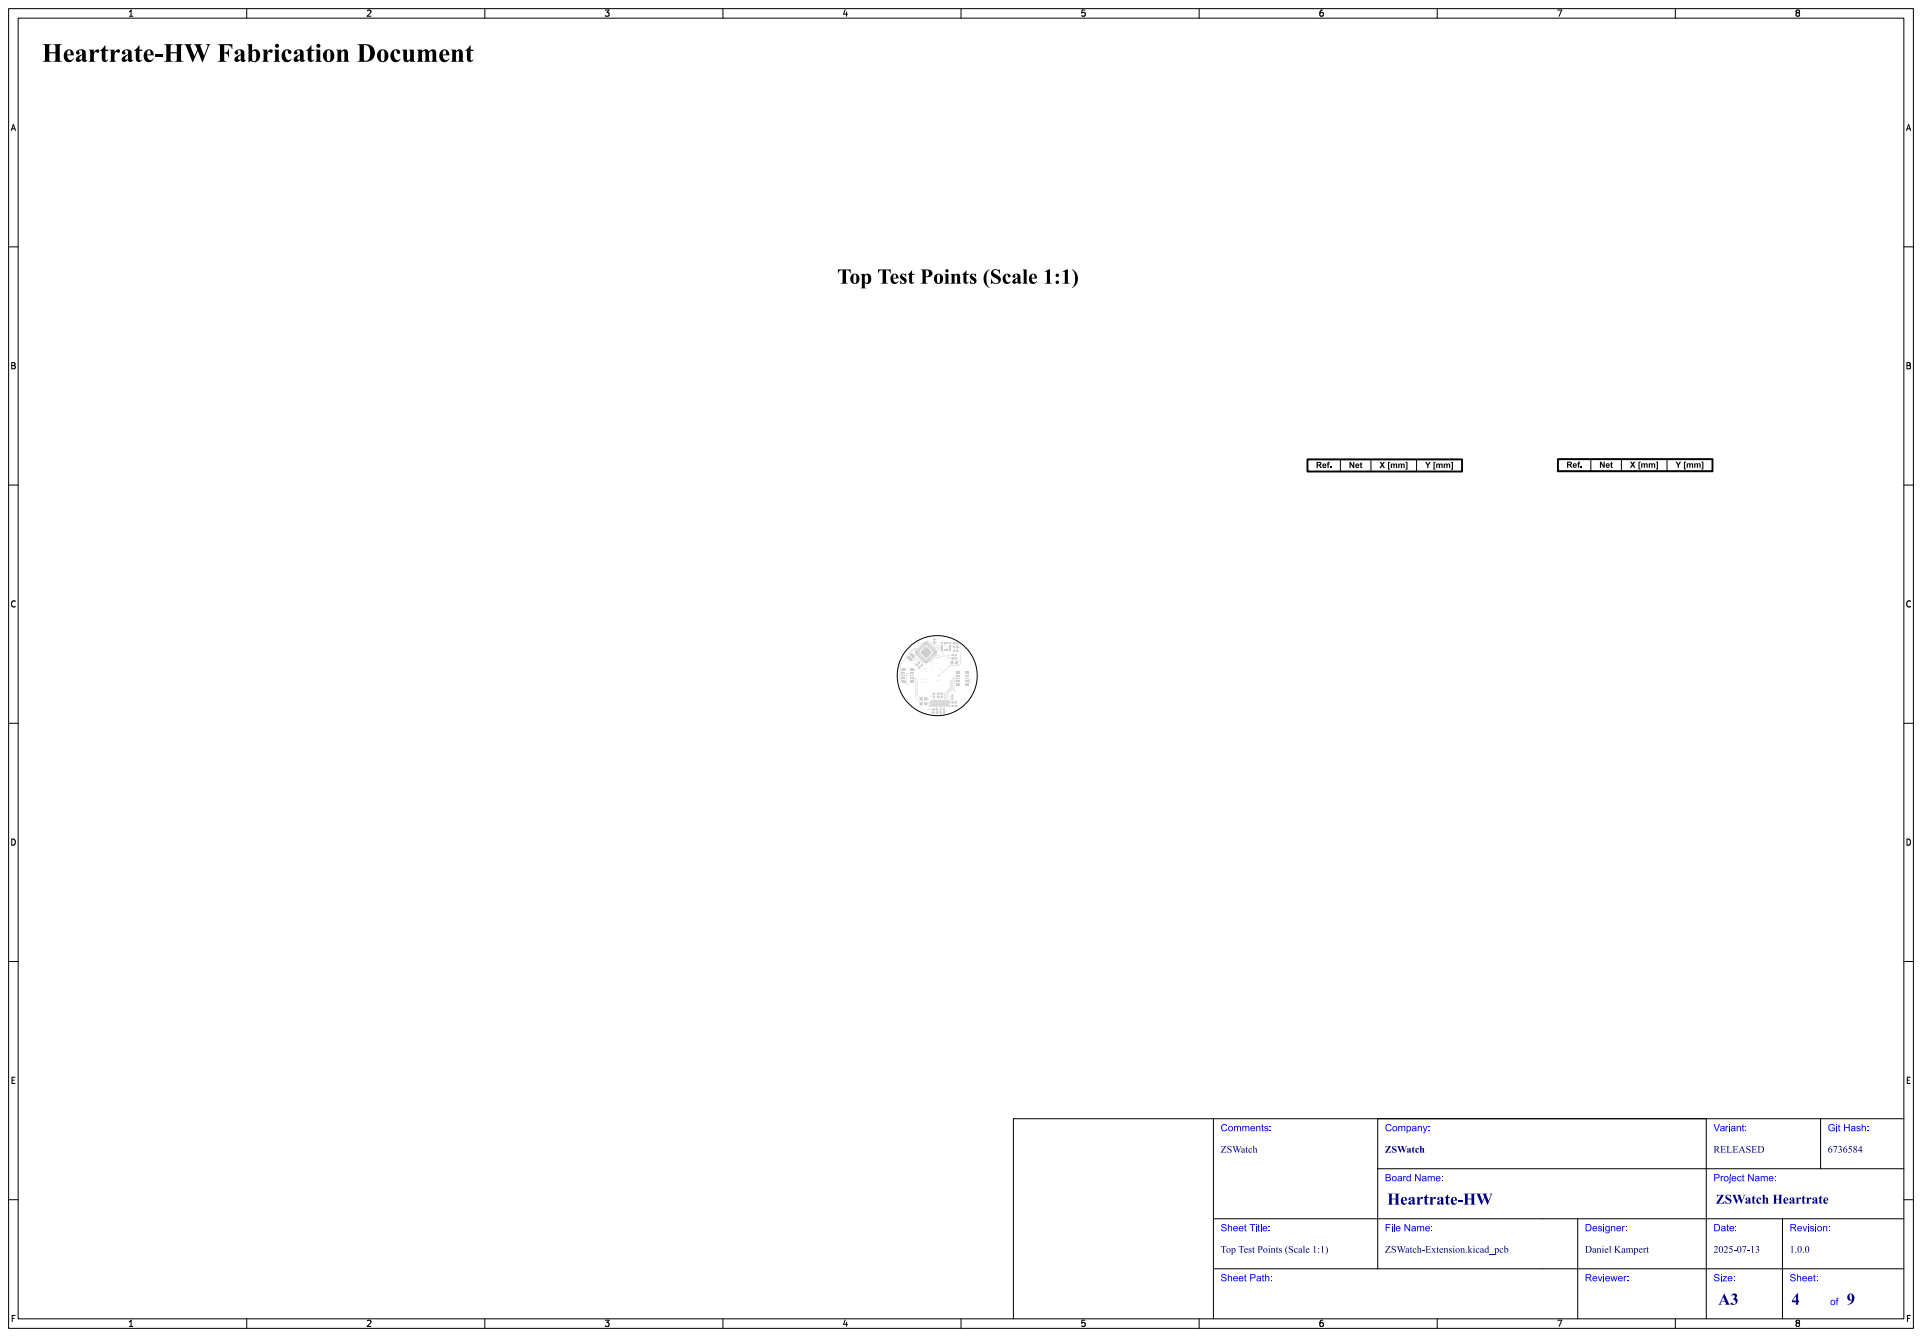
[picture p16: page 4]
Git; Hash:; ZSWatch; Comments:; Sheet Title:; File Name:; Heartrate-HW; ZSWatch Heartrate; Company:; RELEASED; Variant:; Board Name:; ZSWatch-Extension.kicad_pcb; Daniel Kampert; Designer:; Project Name:; Date:; Revision:

Top Test Points (Scale 1:1)

# Bottom Test Points (Scale 1:1)

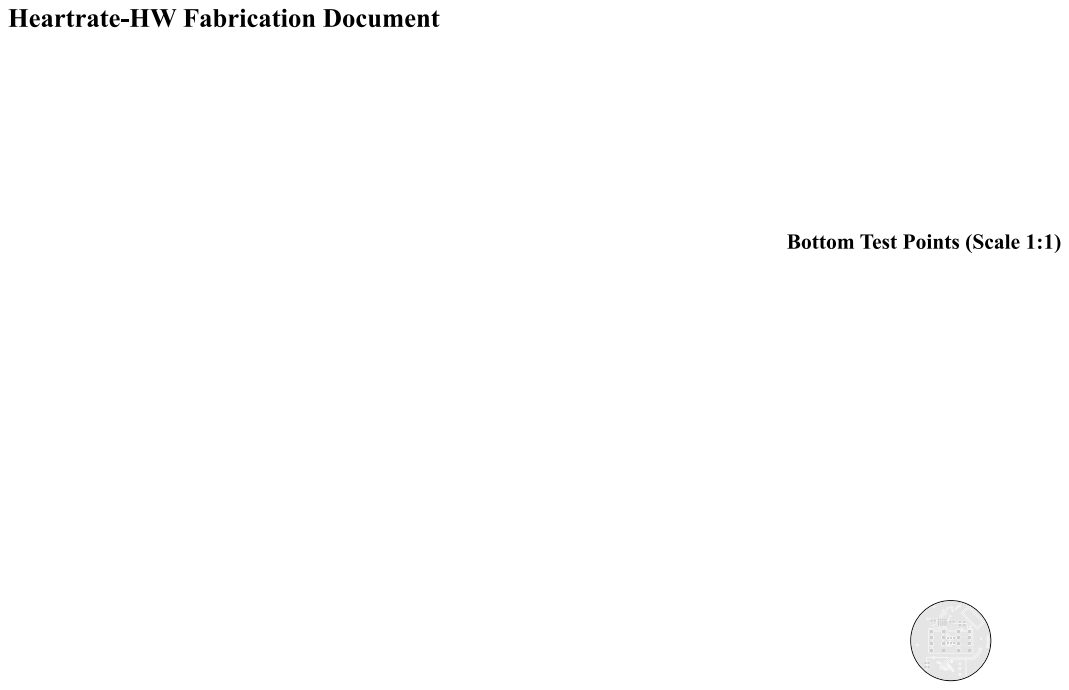
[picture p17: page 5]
Git; Hash:; ZSWatch; Comments:; Sheet Title:; File Name:; Heartrate-HW; ZSWatch Heartrate; Company:; RELEASED; Variant:; Board Name:; ZSWatch-Extension.kicad_pcb; Daniel Kampert; Designer:; Project Name:; Date:; Revision:

Bottom Test Points (Scale 1:1)

# F.Cu (Scale 1:1)

Git; Hash:; ZSWatch; Comments:; F.Cu (Scale 1:1); Sheet Title:; File Name:; Heartrate-HW; ZSWatch Heartrate; Company:; RELEASED; Variant:; Board Name:; ZSWatch-Extension.kicad_pcb; Daniel Kampert; Designer:; Project Name:; Date:; Revision:

# Supply (Scale 1:1)

Git; Hash:; ZSWatch; Comments:; Supply (Scale 1:1); Sheet Title:; File Name:; Heartrate-HW; ZSWatch Heartrate; Company:; RELEASED; Variant:; Board Name:; ZSWatch-Extension.kicad_pcb; Daniel Kampert; Designer:; Project Name:; Date:; Revision:

# GND (Scale 1:1)

Git; Hash:; ZSWatch; Comments:; GND (Scale 1:1); Sheet Title:; File Name:; Heartrate-HW; ZSWatch Heartrate; Company:; RELEASED; Variant:; Board Name:; ZSWatch-Extension.kicad_pcb; Daniel Kampert; Designer:; Project Name:; Date:; Revision:

# B.Cu (Scale 1:1)

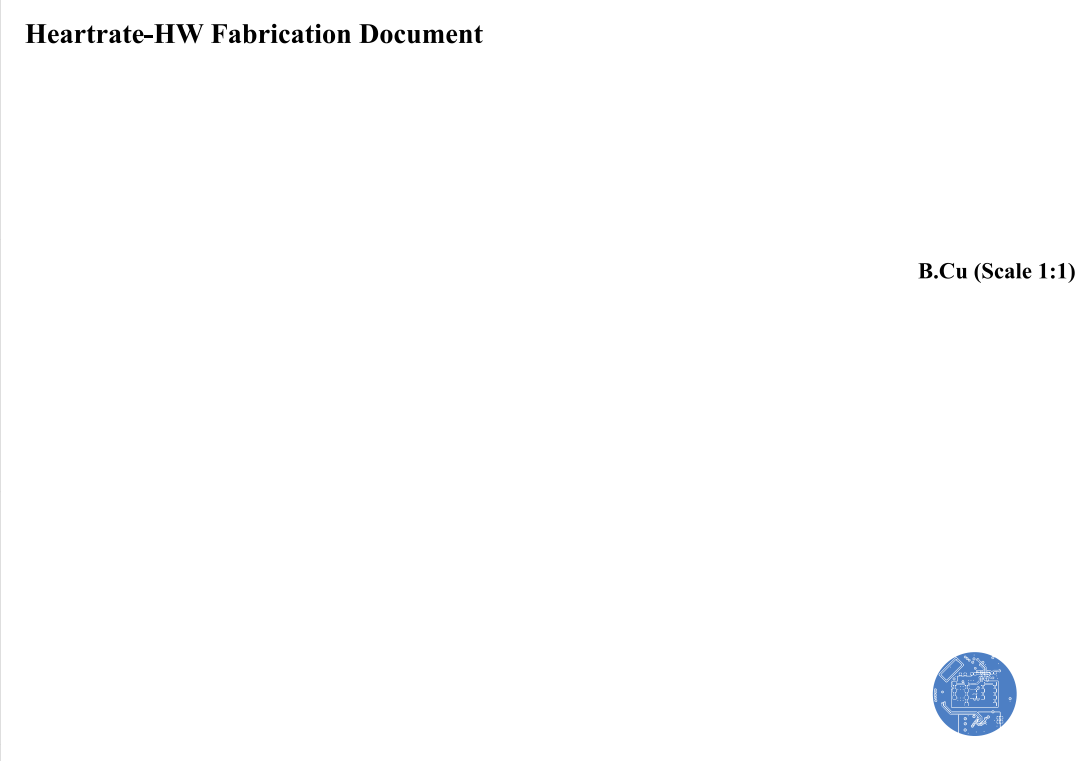
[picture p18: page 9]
Git; Hash:; ZSWatch; Comments:; B.Cu (Scale 1:1); Sheet Title:; File Name:; Heartrate-HW; ZSWatch Heartrate; Company:; RELEASED; Variant:; Board Name:; ZSWatch-Extension.kicad_pcb; Daniel Kampert; Designer:; Project Name:; Date:; Revision:

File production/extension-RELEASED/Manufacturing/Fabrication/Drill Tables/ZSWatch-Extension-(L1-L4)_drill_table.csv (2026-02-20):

Count | Hole Size | Plated | Hole Shape | Drill Layer Pair | Hole Type
88 | 0.15mm (5.91mils) | PTH | Round | F.Cu - B.Cu | Via
Total 88

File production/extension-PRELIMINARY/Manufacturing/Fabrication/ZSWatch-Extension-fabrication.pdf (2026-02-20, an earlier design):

# Top Fabrication (Scale 1:1)

# Heartrate-HW Fabrication Document

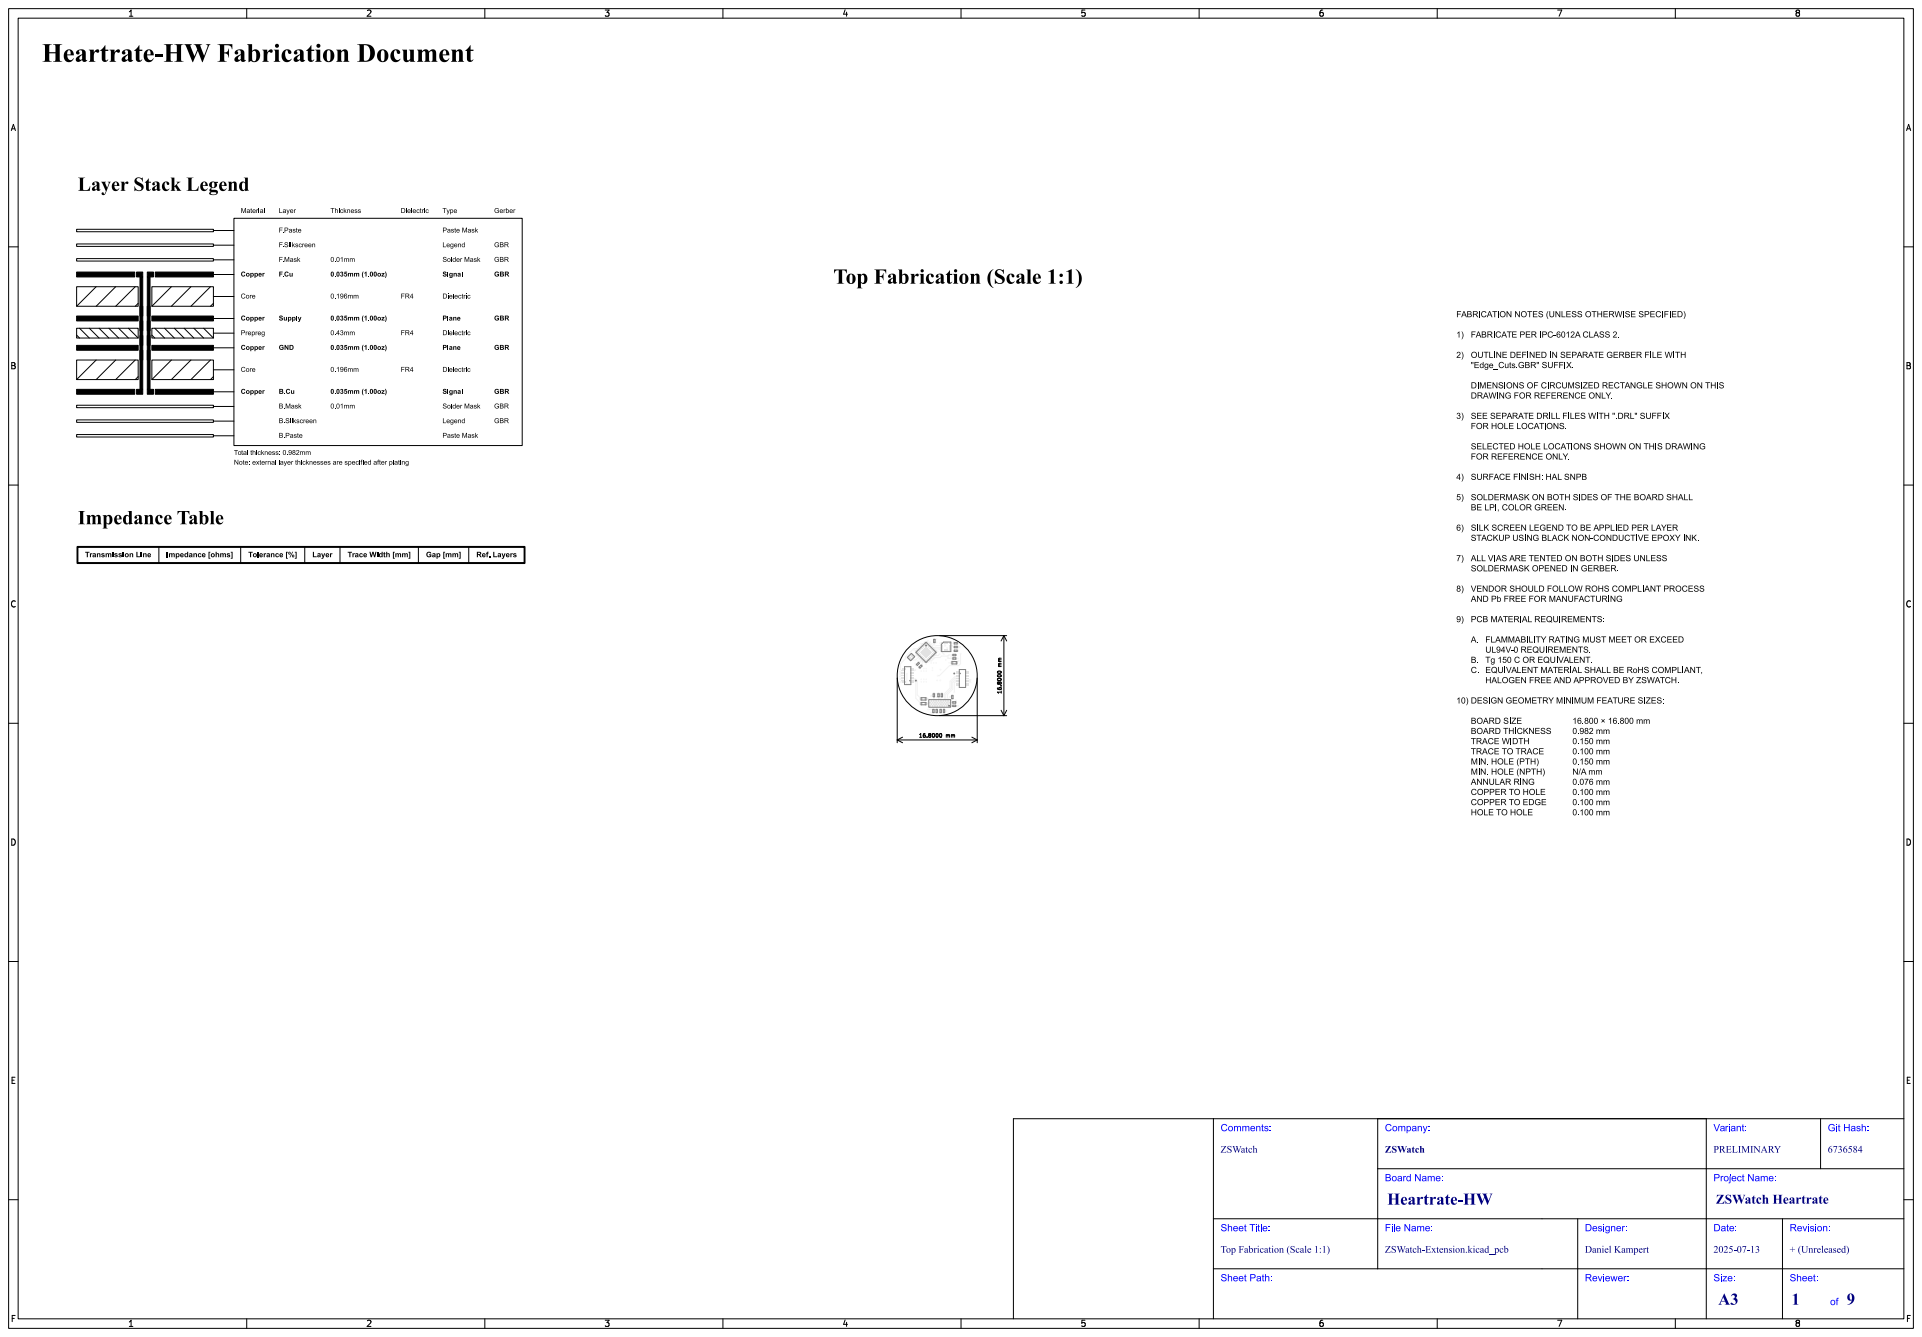
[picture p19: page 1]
Git Hash:; ZSWatch; Comments:; Sheet Path:; Sheet Title:; File Name:; Heartrate-HW; ZSWatch Heartrate; Company:; PRELIMINARY; Variant:; Board Name:; ZSWatch-Extension.kicad_pcb; Daniel Kampert; Designer:; Reviewer:; Project Name:; Date:; + (Unreleased); Revision:; Size:; Sheet:

Top Fabrication (Scale 1:1)

# Bottom Fabrication (Scale 1:1)

Git; Hash:; ZSWatch; Comments:; Sheet Title:; File Name:; Heartrate-HW; ZSWatch Heartrate; Company:; PRELIMINARY; Variant:; Board Name:; ZSWatch-Extension.kicad_pcb; Daniel Kampert; Designer:; Project Name:; Date:; + (Unreleased); Revision:

Bottom Fabrication (Scale 1:1)

# Drill Drawing L1 - L4 (Scale 1:1)

Git; Hash:; ZSWatch; Comments:; Drill Drawing (L1 - L4); Sheet Title:; File Name:; Heartrate-HW; ZSWatch Heartrate; Company:; PRELIMINARY; Variant:; Board Name:; ZSWatch-Extension.kicad_pcb; Daniel Kampert; Designer:; Project Name:; Date:; + (Unreleased); Revision:

# Top Test Points (Scale 1:1)

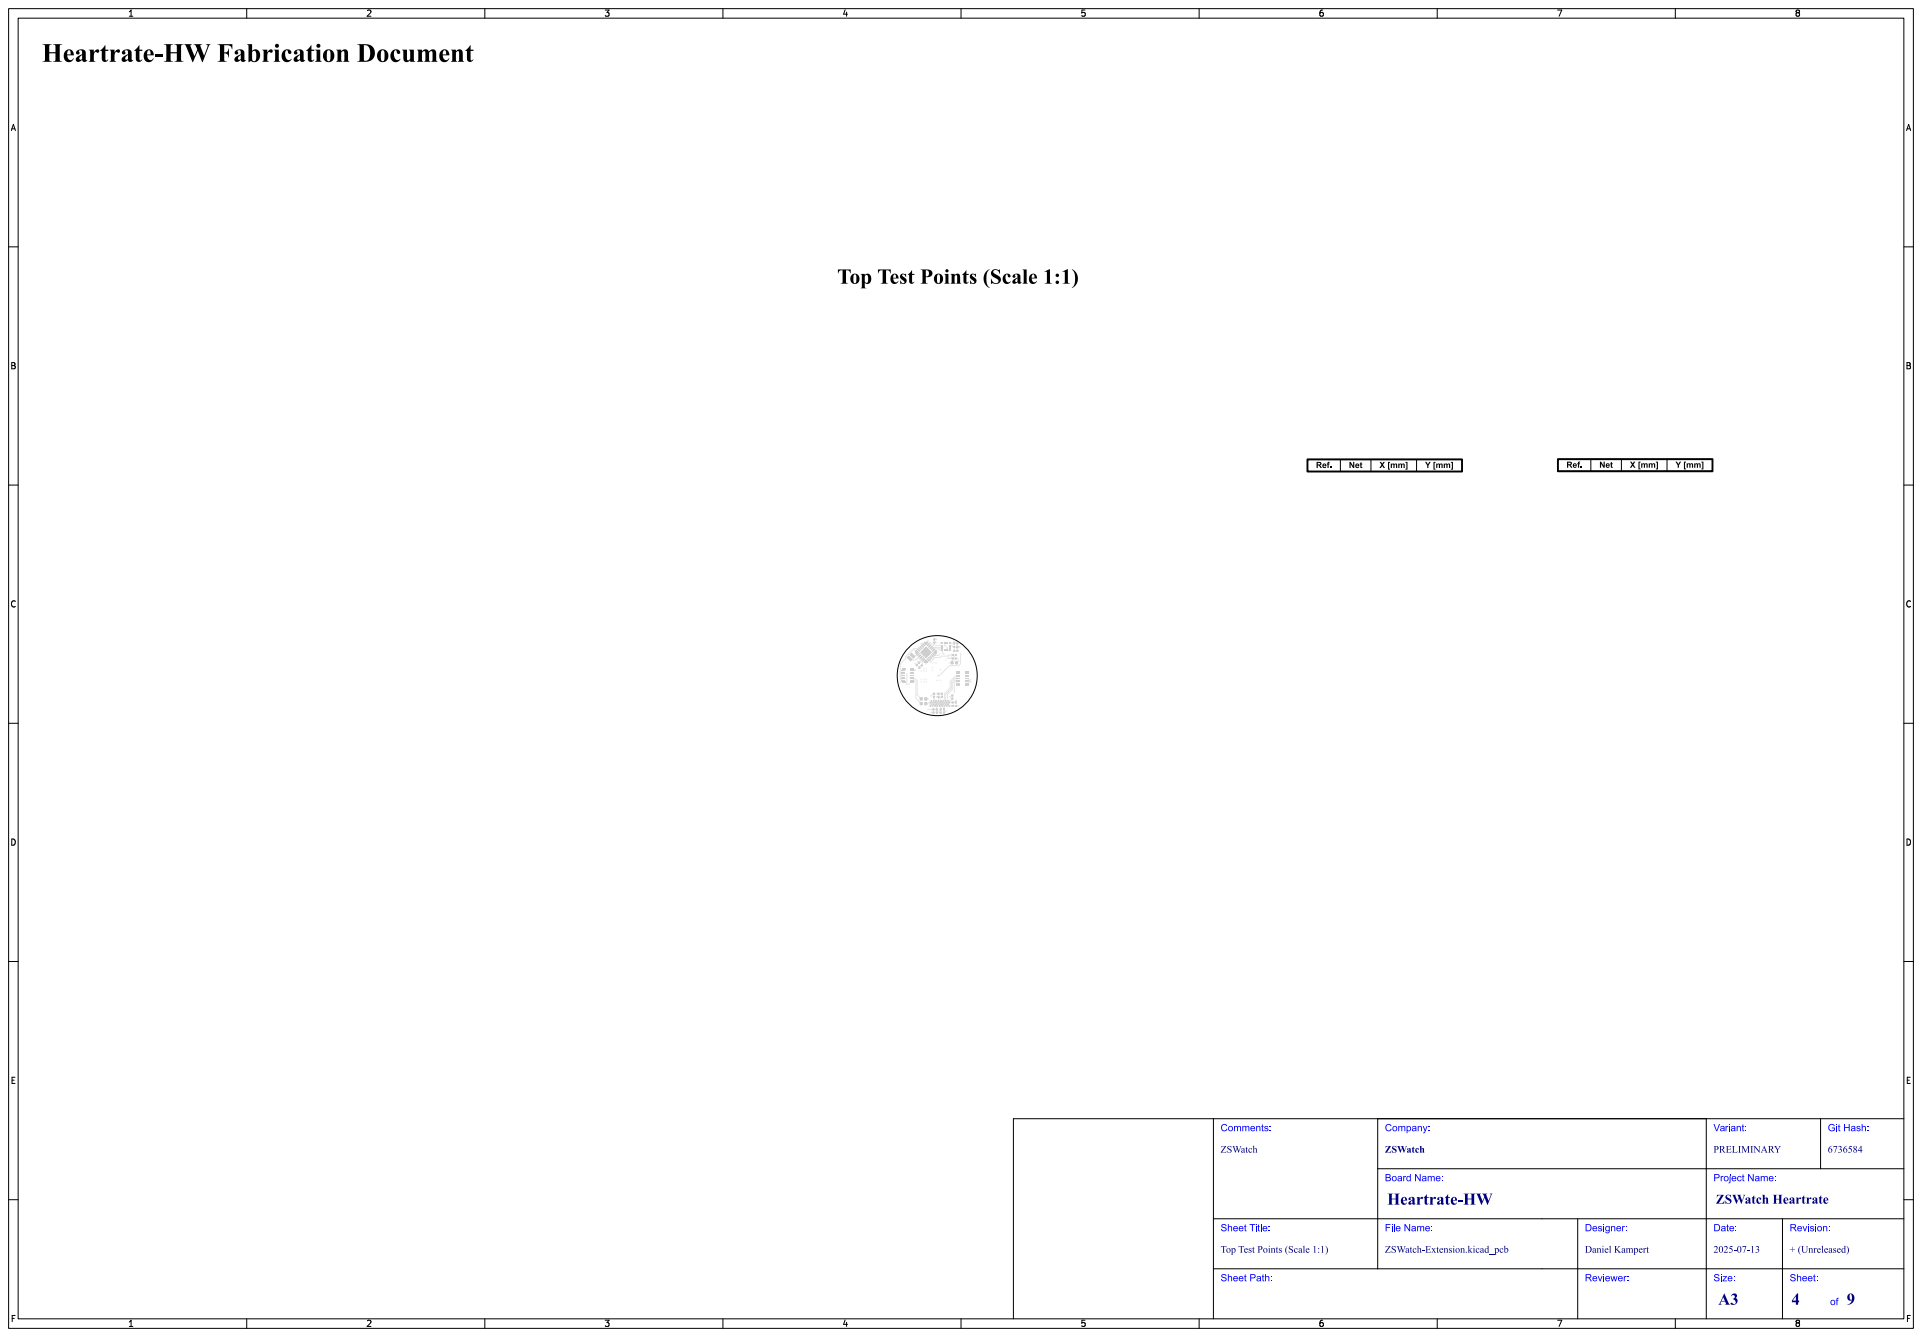
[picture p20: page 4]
Git; Hash:; ZSWatch; Comments:; Sheet Title:; File Name:; Heartrate-HW; ZSWatch Heartrate; Company:; PRELIMINARY; Variant:; Board Name:; ZSWatch-Extension.kicad_pcb; Daniel Kampert; Designer:; Project Name:; Date:; + (Unreleased); Revision:

Top Test Points (Scale 1:1)

# Bottom Test Points (Scale 1:1)

Git; Hash:; ZSWatch; Comments:; Sheet Title:; File Name:; Heartrate-HW; ZSWatch Heartrate; Company:; PRELIMINARY; Variant:; Board Name:; ZSWatch-Extension.kicad_pcb; Daniel Kampert; Designer:; Project Name:; Date:; + (Unreleased); Revision:

Bottom Test Points (Scale 1:1)

# F.Cu (Scale 1:1)

Git; Hash:; ZSWatch; Comments:; F.Cu (Scale 1:1); Sheet Title:; File Name:; Heartrate-HW; ZSWatch Heartrate; Company:; PRELIMINARY; Variant:; Board Name:; ZSWatch-Extension.kicad_pcb; Daniel Kampert; Designer:; Project Name:; Date:; + (Unreleased); Revision:

# Supply (Scale 1:1)

Git; Hash:; ZSWatch; Comments:; Supply (Scale 1:1); Sheet Title:; File Name:; Heartrate-HW; ZSWatch Heartrate; Company:; PRELIMINARY; Variant:; Board Name:; ZSWatch-Extension.kicad_pcb; Daniel Kampert; Designer:; Project Name:; Date:; + (Unreleased); Revision:

# GND (Scale 1:1)

Git; Hash:; ZSWatch; Comments:; GND (Scale 1:1); Sheet Title:; File Name:; Heartrate-HW; ZSWatch Heartrate; Company:; PRELIMINARY; Variant:; Board Name:; ZSWatch-Extension.kicad_pcb; Daniel Kampert; Designer:; Project Name:; Date:; + (Unreleased); Revision:

# B.Cu (Scale 1:1)

Git; Hash:; ZSWatch; Comments:; B.Cu (Scale 1:1); Sheet Title:; File Name:; Heartrate-HW; ZSWatch Heartrate; Company:; PRELIMINARY; Variant:; Board Name:; ZSWatch-Extension.kicad_pcb; Daniel Kampert; Designer:; Project Name:; Date:; + (Unreleased); Revision:

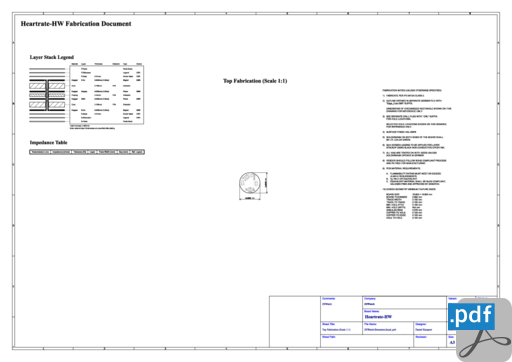
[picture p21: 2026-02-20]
production/extension-RELEASED/HTML/images/cat_pdf_fabrication_ZSWatch-Extension-fabrication.png

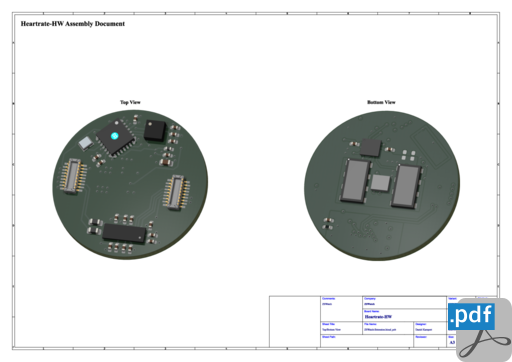
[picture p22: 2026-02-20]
production/extension-CHECKED/HTML/images/cat_pdf_assembly_ZSWatch-Extension-assembly.png

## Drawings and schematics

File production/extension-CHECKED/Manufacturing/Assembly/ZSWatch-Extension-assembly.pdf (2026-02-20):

# Heartrate-HW Assembly Document

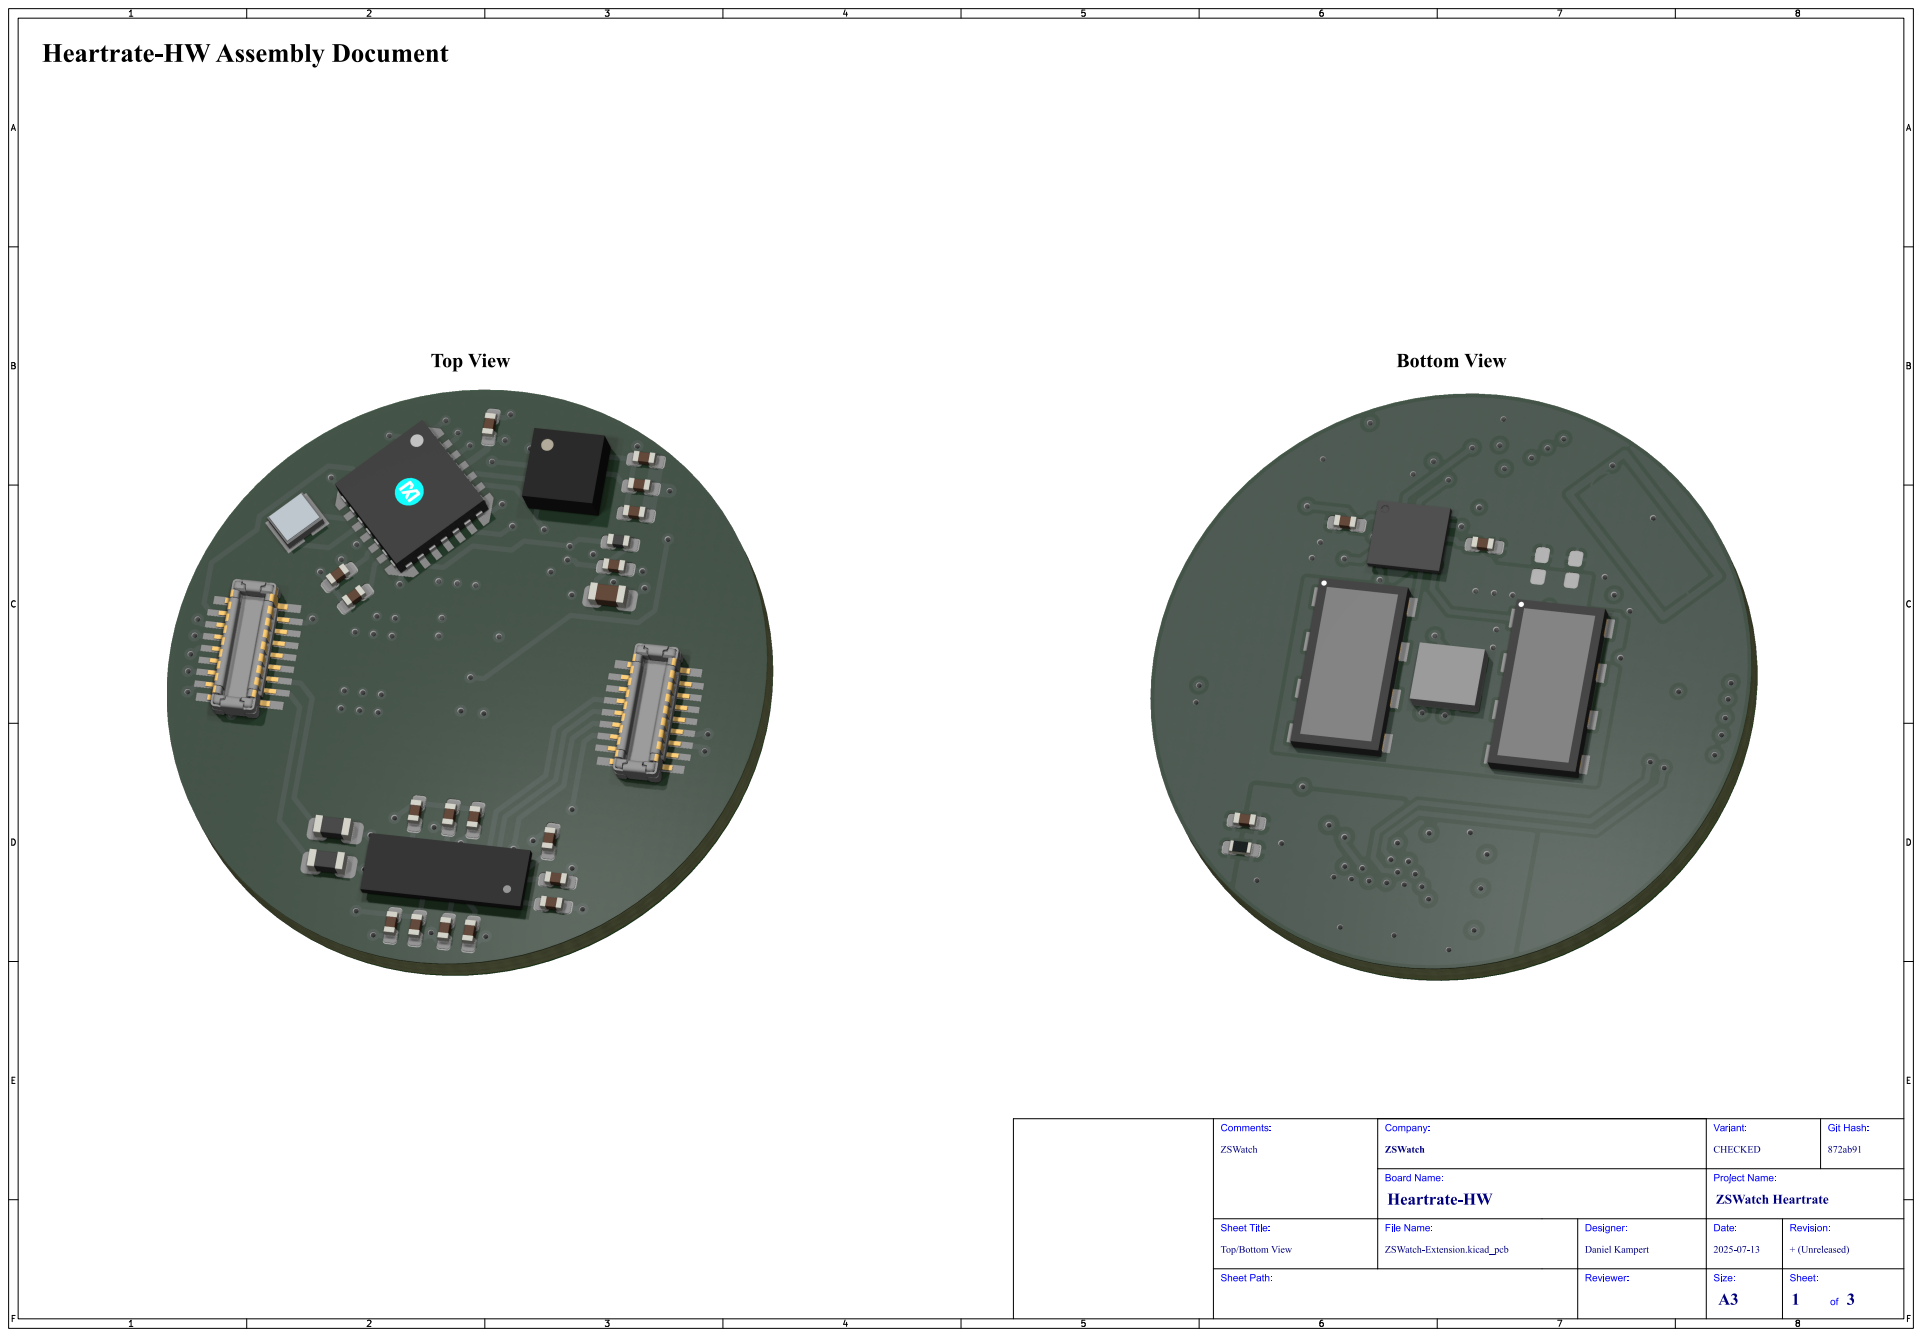
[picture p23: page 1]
Git; Hash:; ZSWatch; Comments:; Sheet Path:; Sheet Title:; File Name:; Heartrate-HW; ZSWatch Heartrate; Company:; CHECKED; Variant:; Board Name:; ZSWatch-Extension.kicad_pcb; Daniel Kampert; Designer:; Reviewer:; Project Name:; Date:; + (Unreleased); Revision:; Size:; Sheet:

Top/Bottom View

# Top Assembly (Scale 1:1)

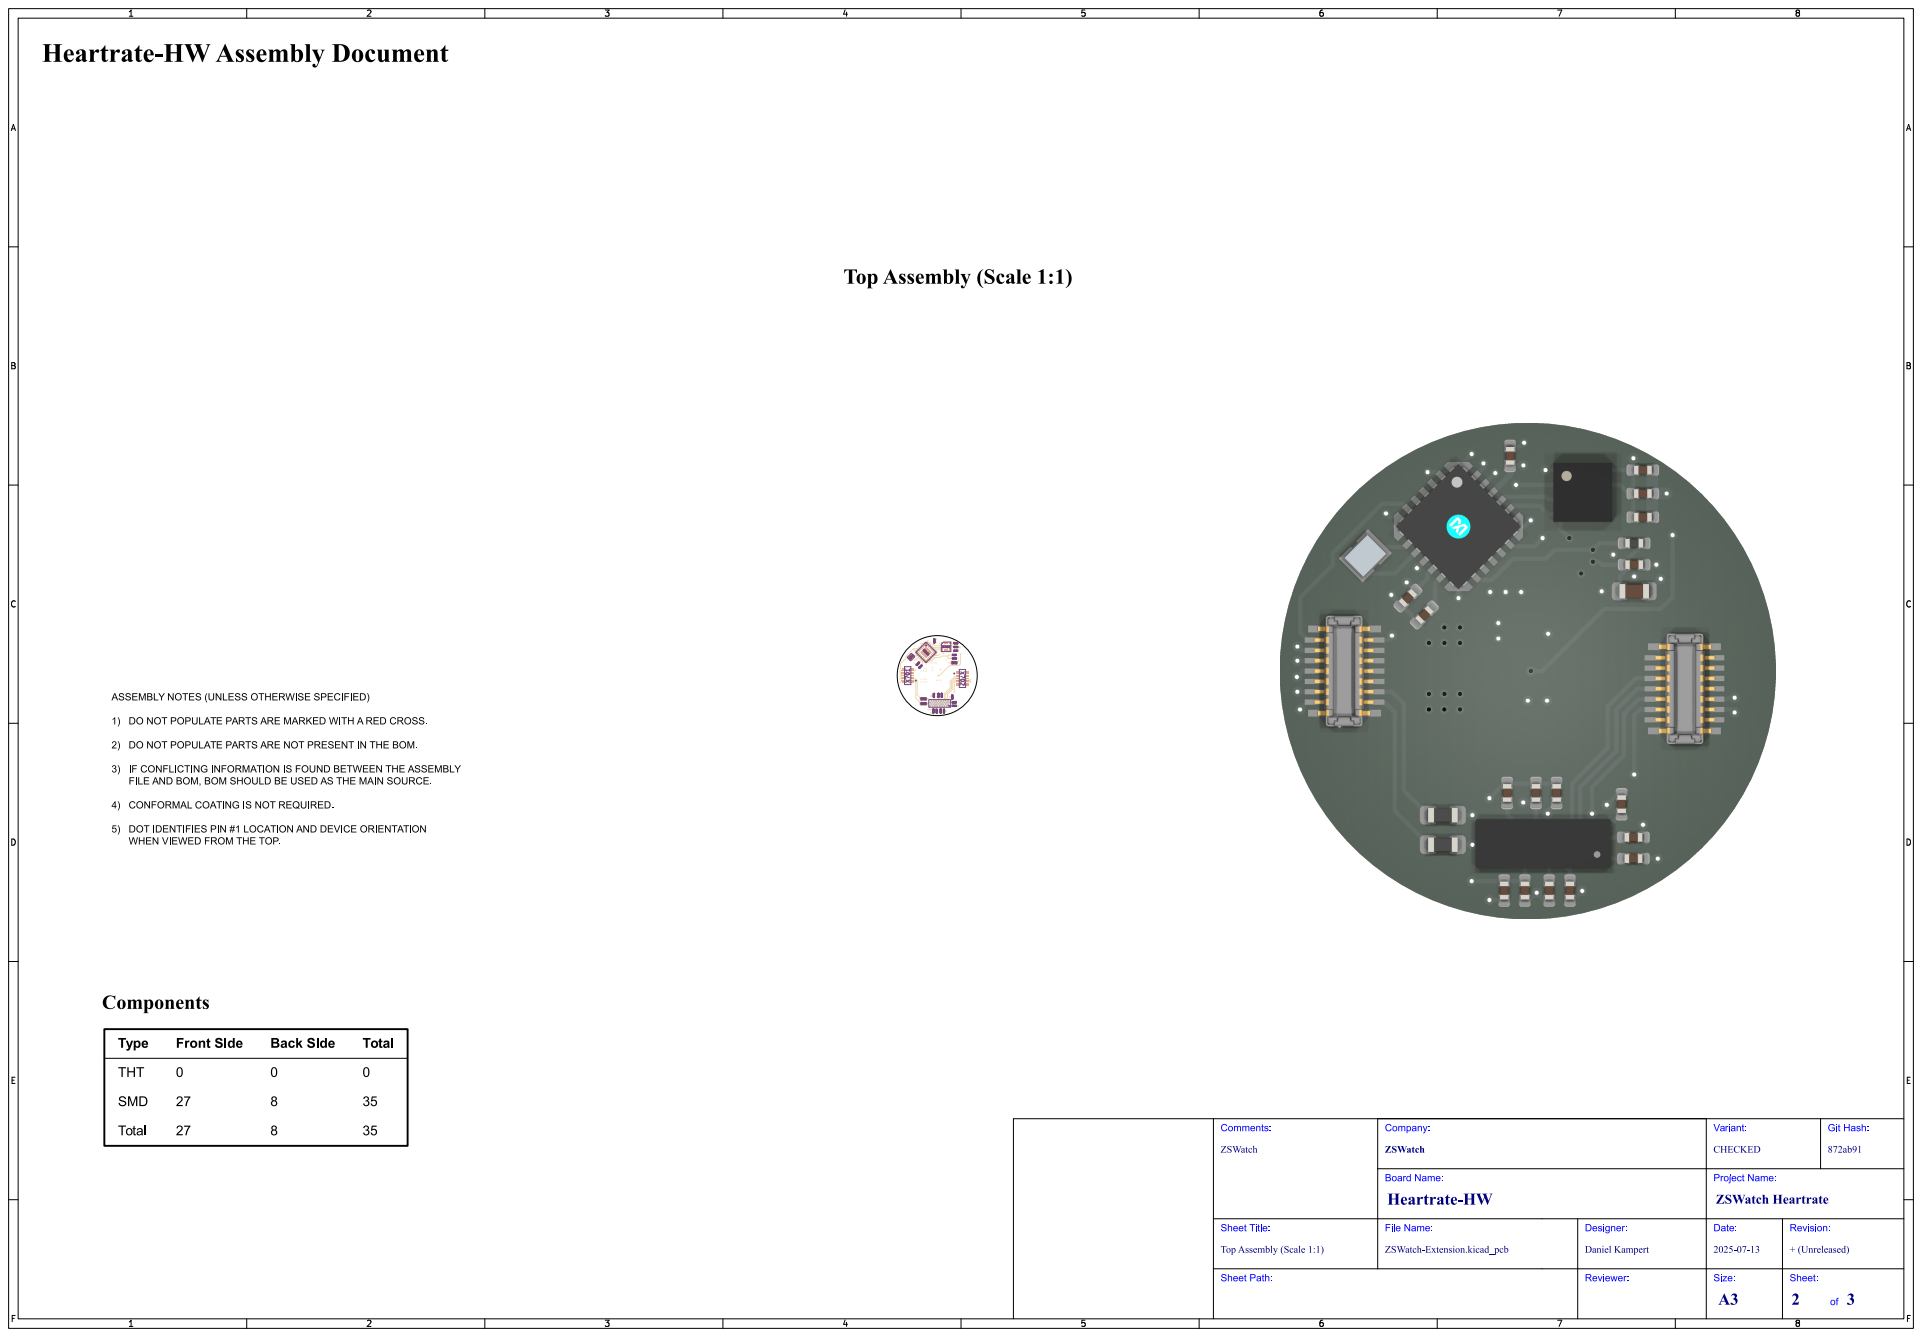
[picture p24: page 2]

# Bottom Assembly (Scale 1:1)

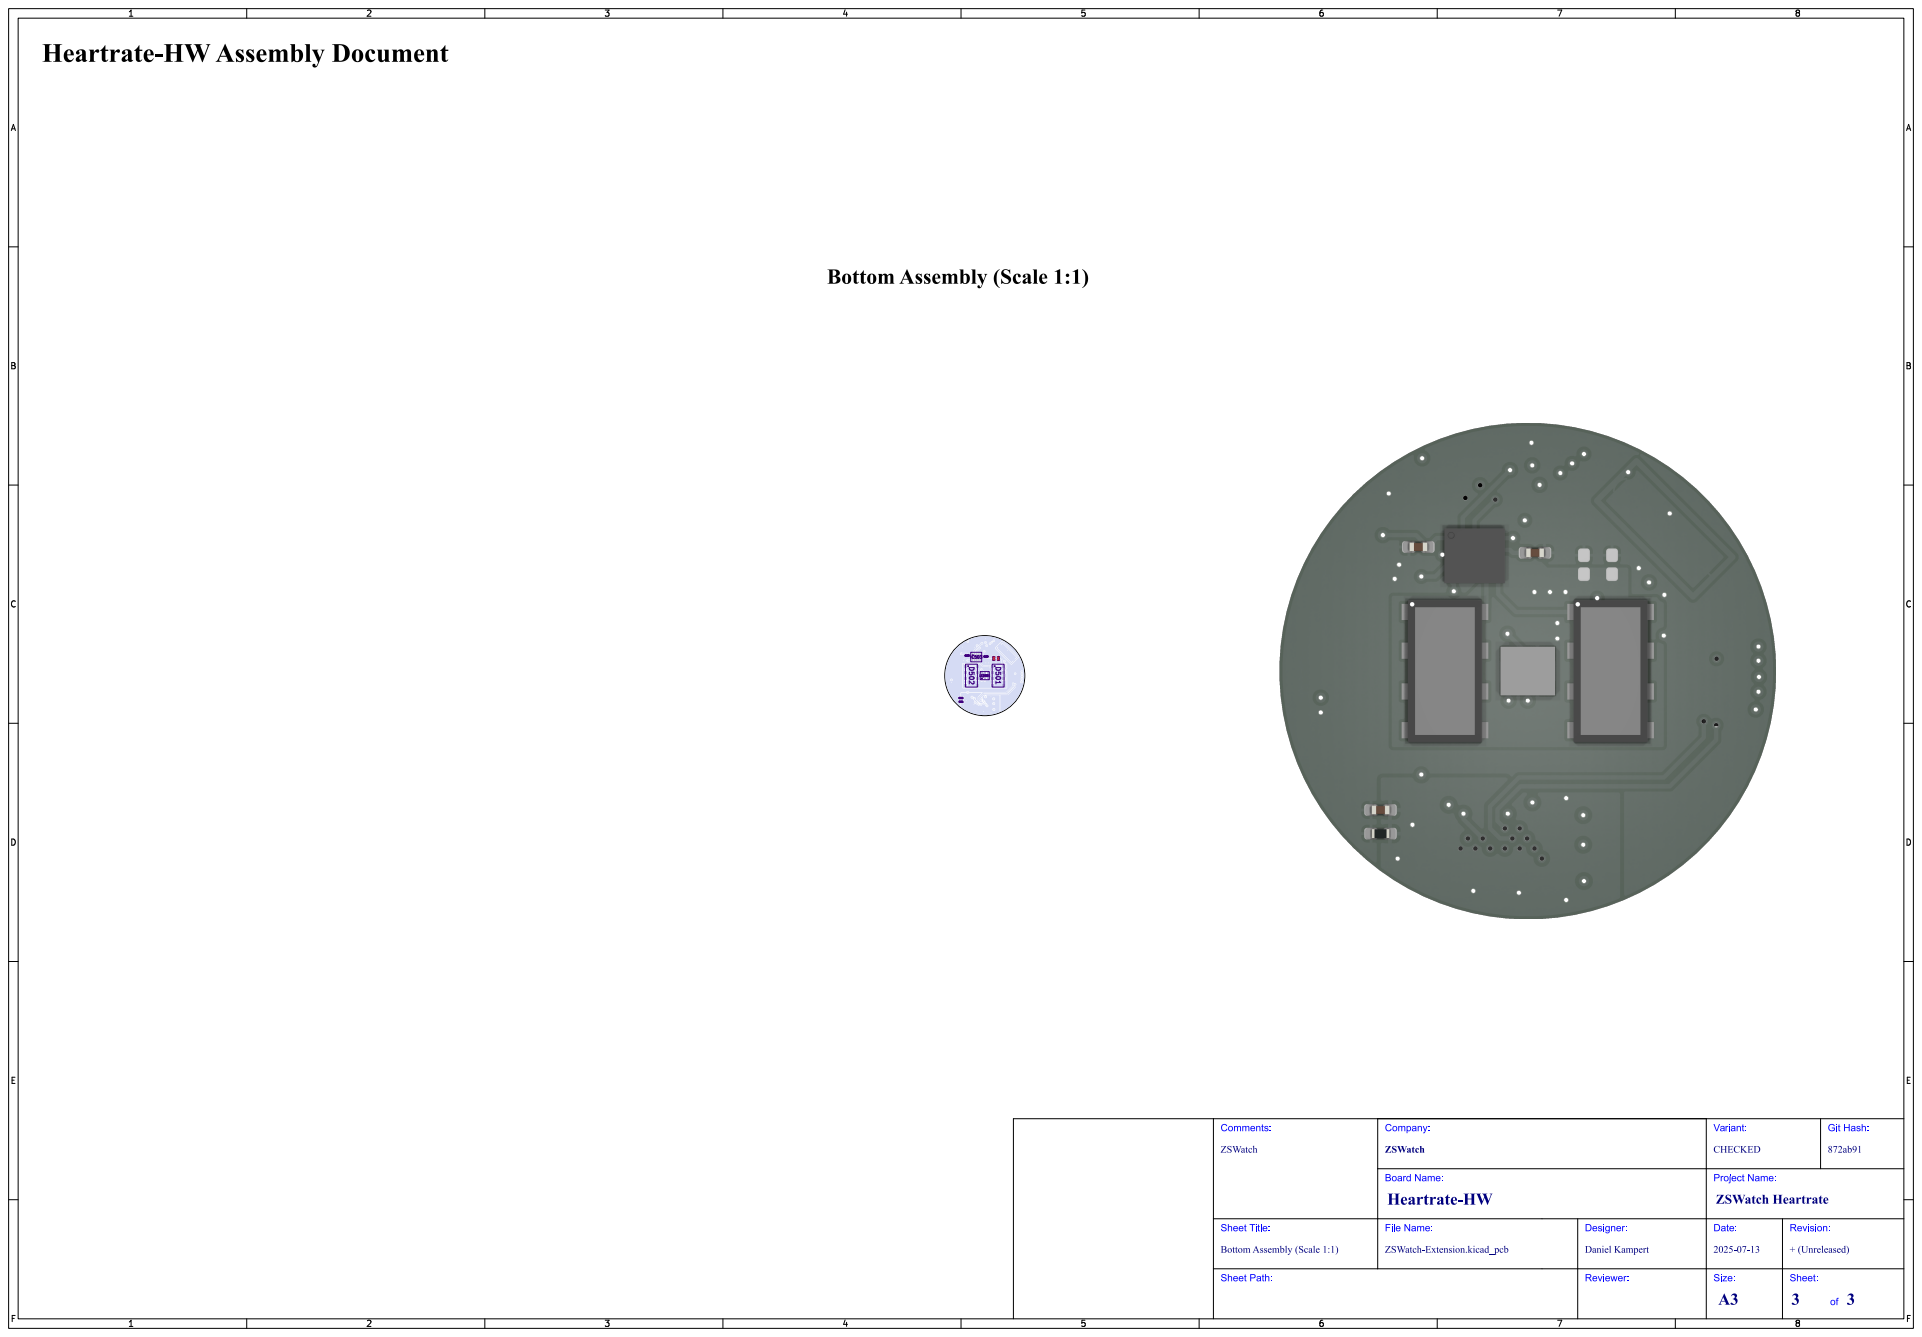
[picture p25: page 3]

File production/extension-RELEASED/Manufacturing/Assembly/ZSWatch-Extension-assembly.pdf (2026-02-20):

# Heartrate-HW Assembly Document

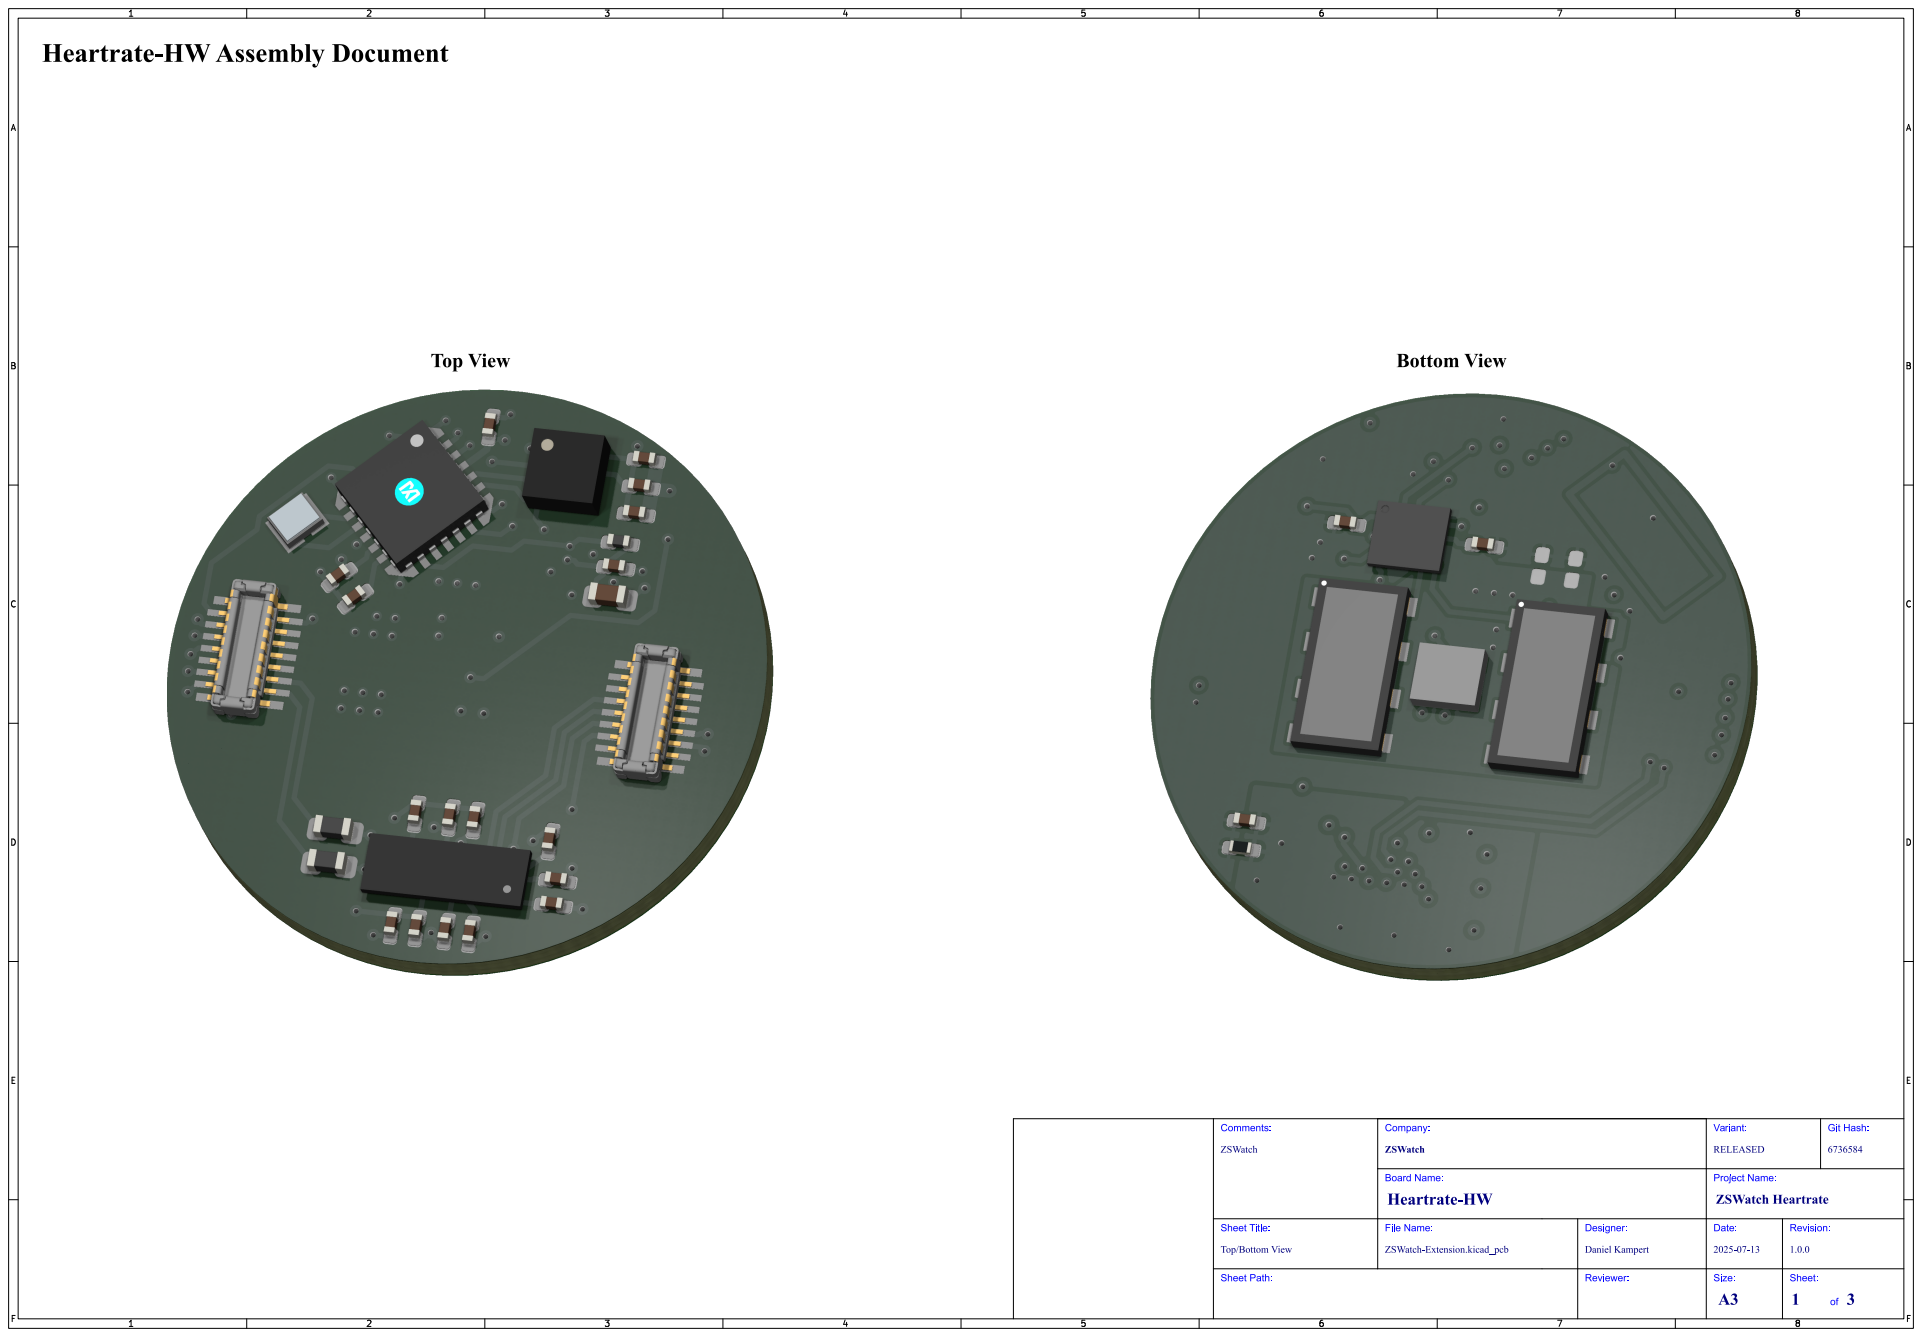
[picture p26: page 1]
Git; Hash:; ZSWatch; Comments:; Sheet Path:; Sheet Title:; File Name:; Heartrate-HW; ZSWatch Heartrate; Company:; RELEASED; Variant:; Board Name:; ZSWatch-Extension.kicad_pcb; Daniel Kampert; Designer:; Reviewer:; Project Name:; Date:; Revision:; Size:; Sheet:

Top/Bottom View

# Top Assembly (Scale 1:1)

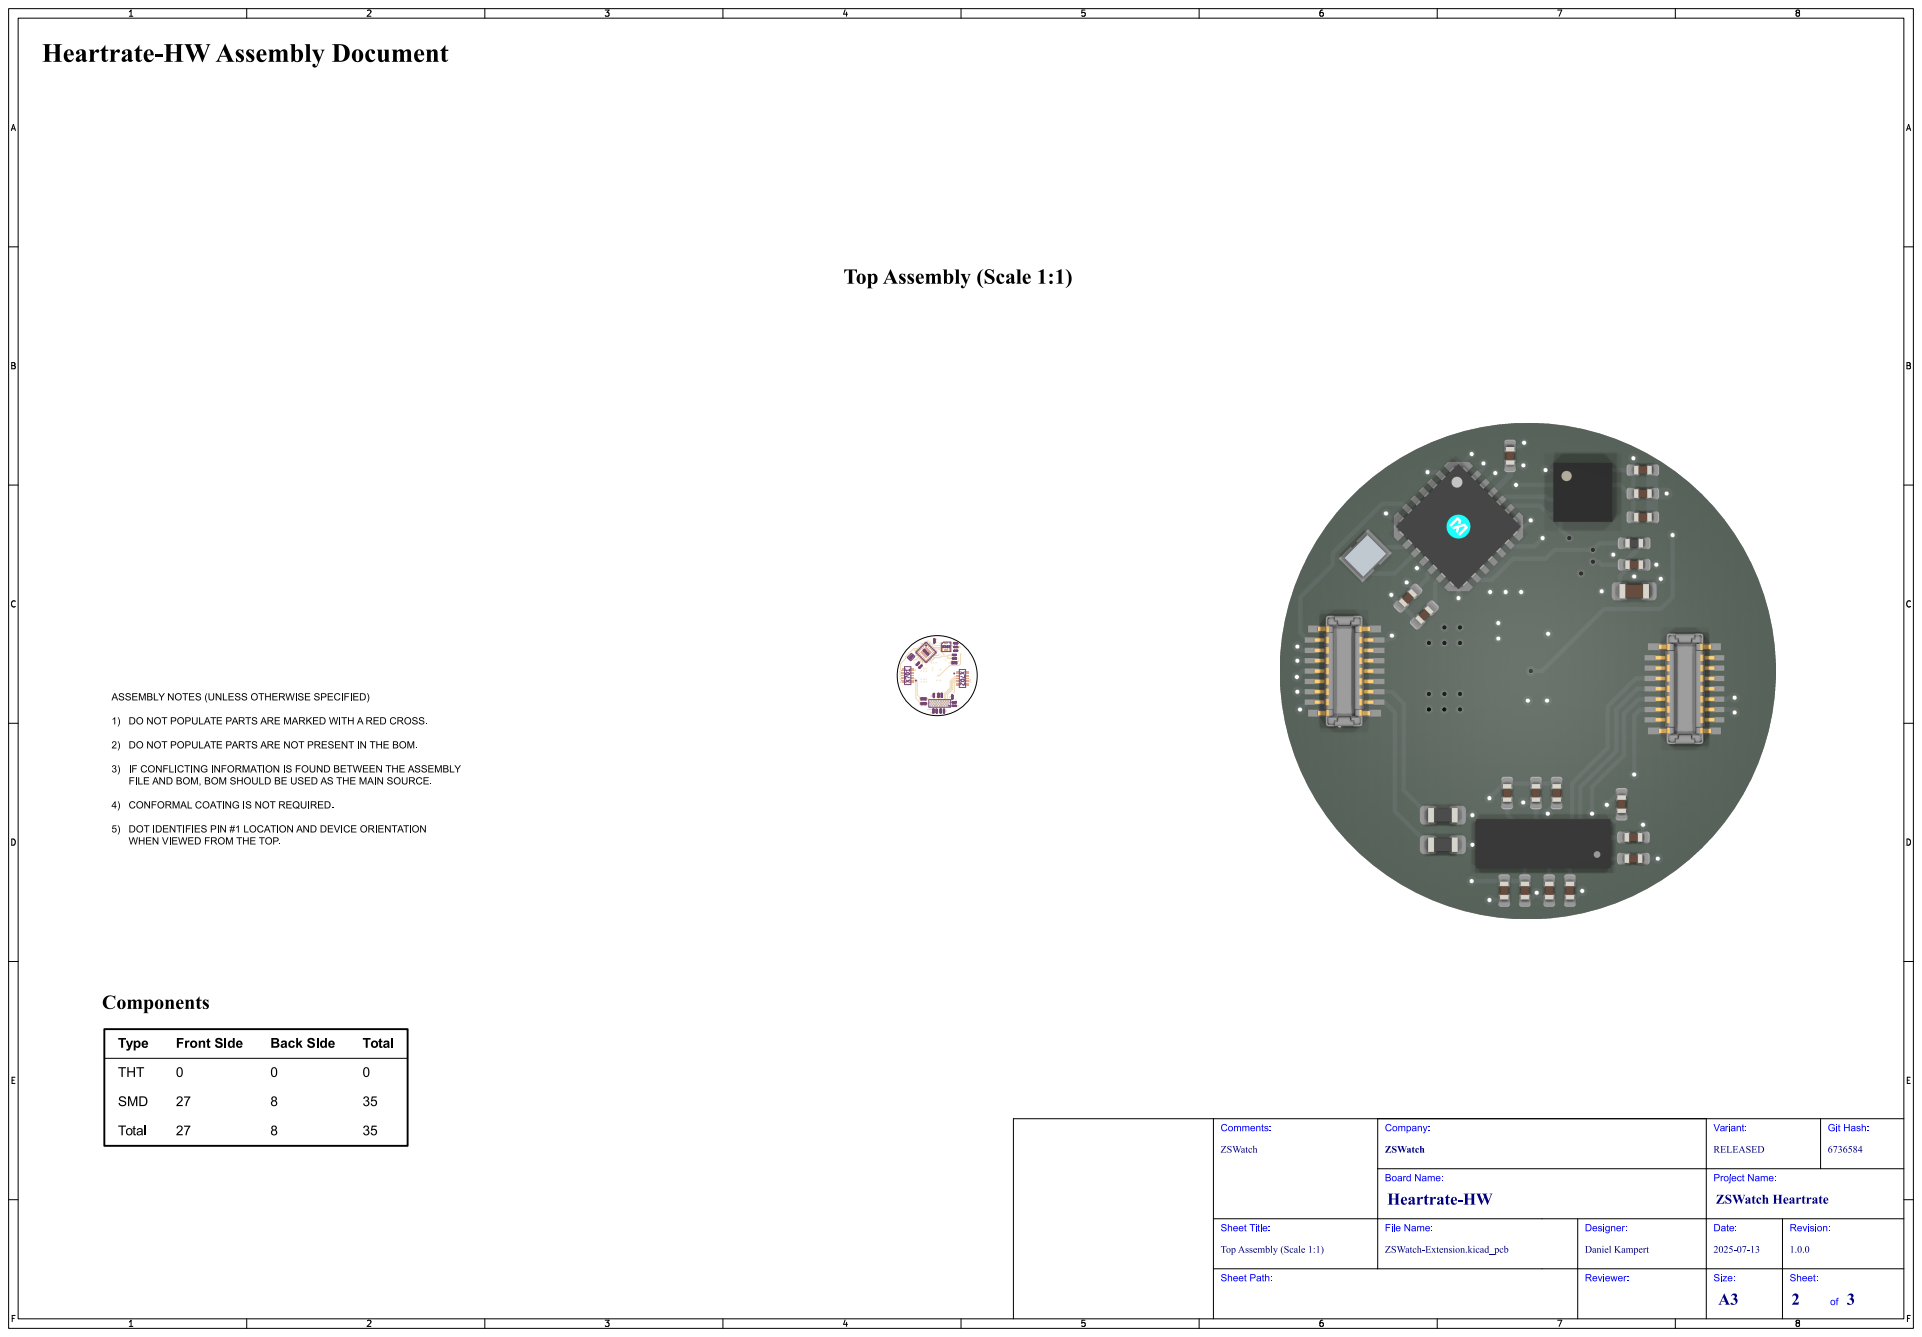
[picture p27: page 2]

# Bottom Assembly (Scale 1:1)

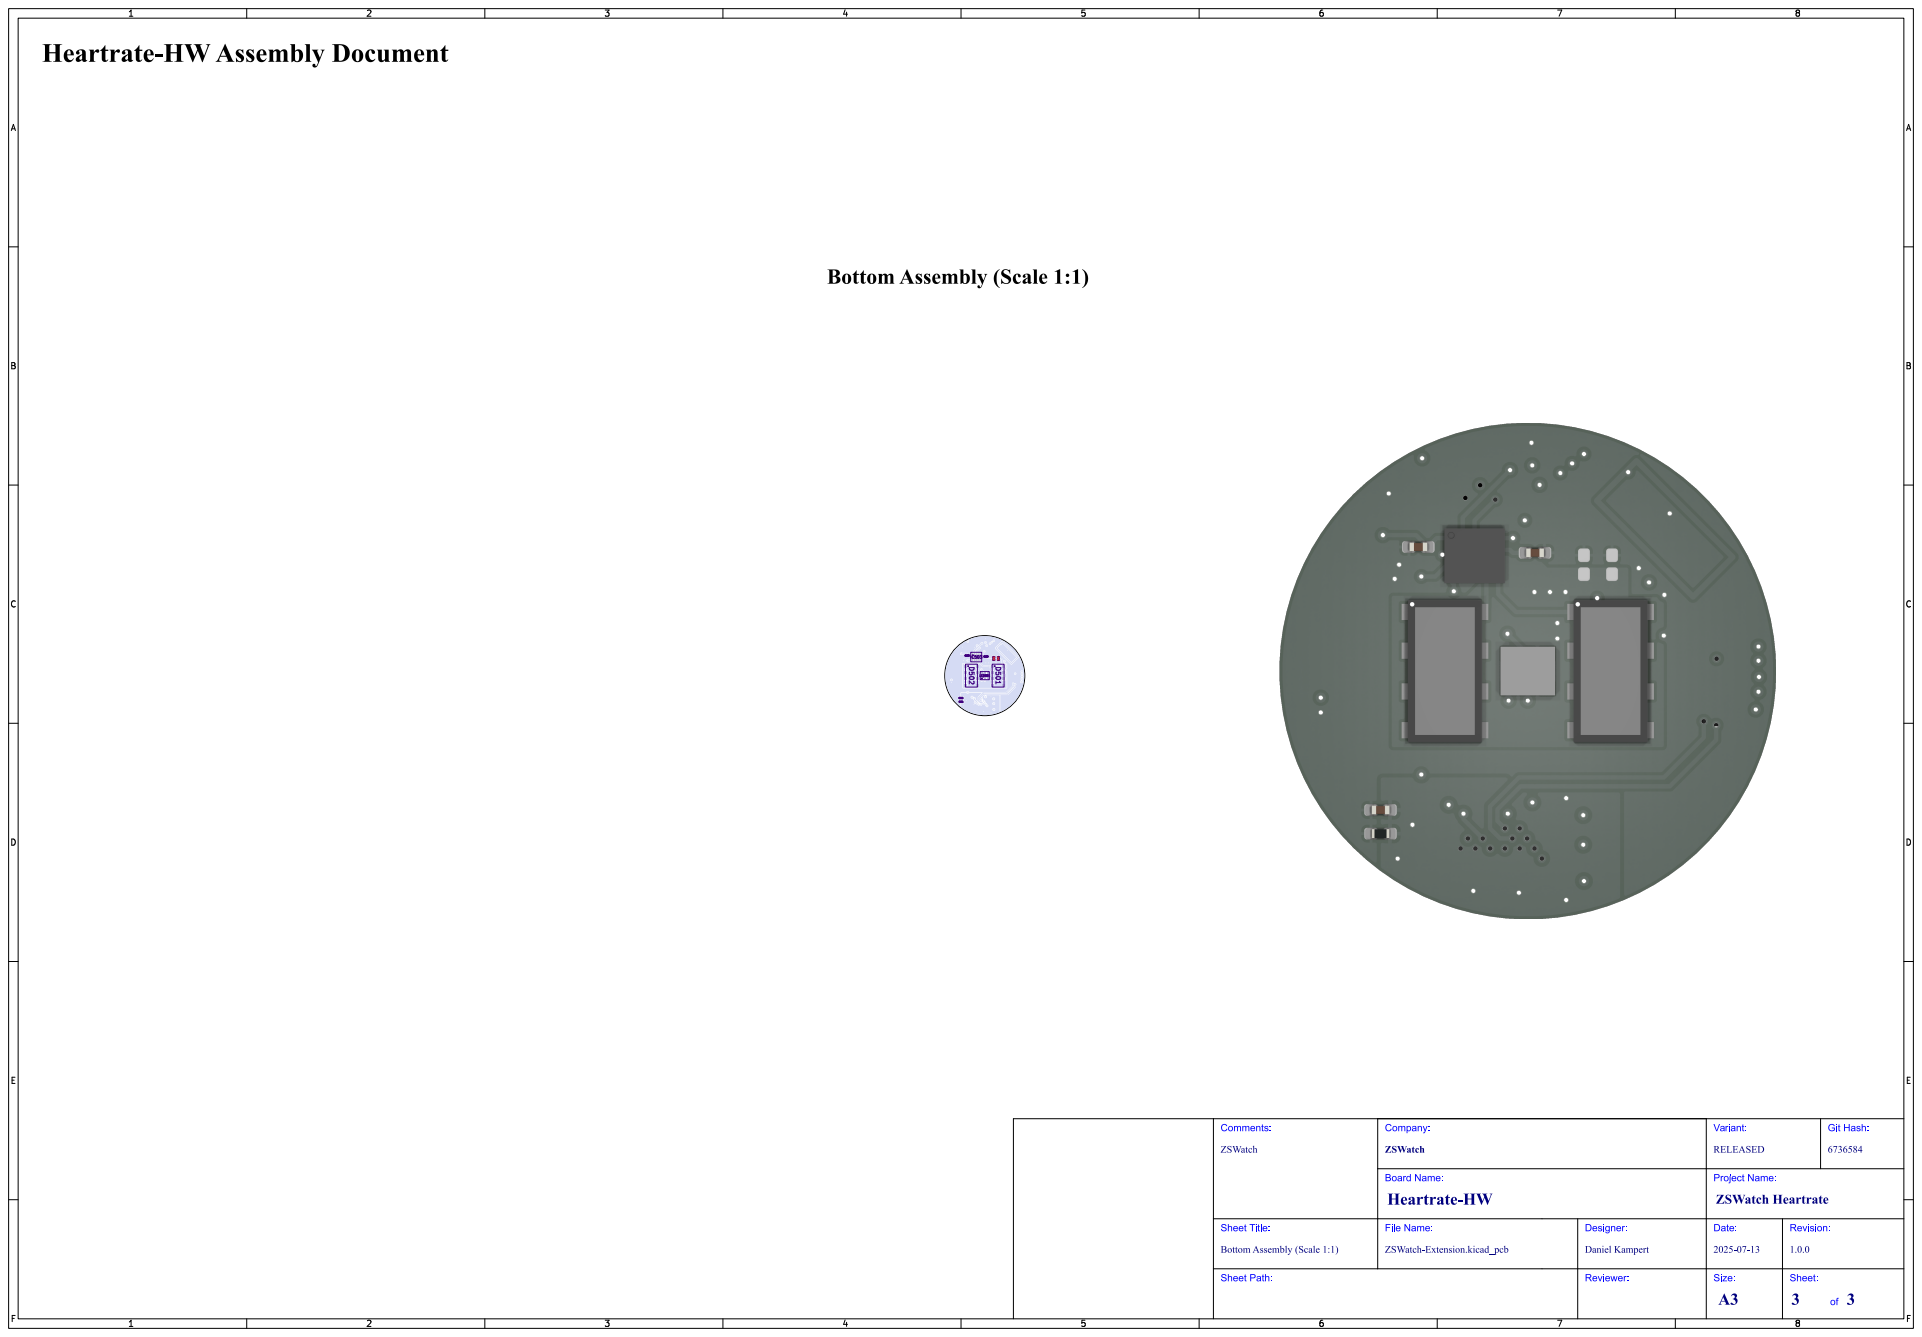
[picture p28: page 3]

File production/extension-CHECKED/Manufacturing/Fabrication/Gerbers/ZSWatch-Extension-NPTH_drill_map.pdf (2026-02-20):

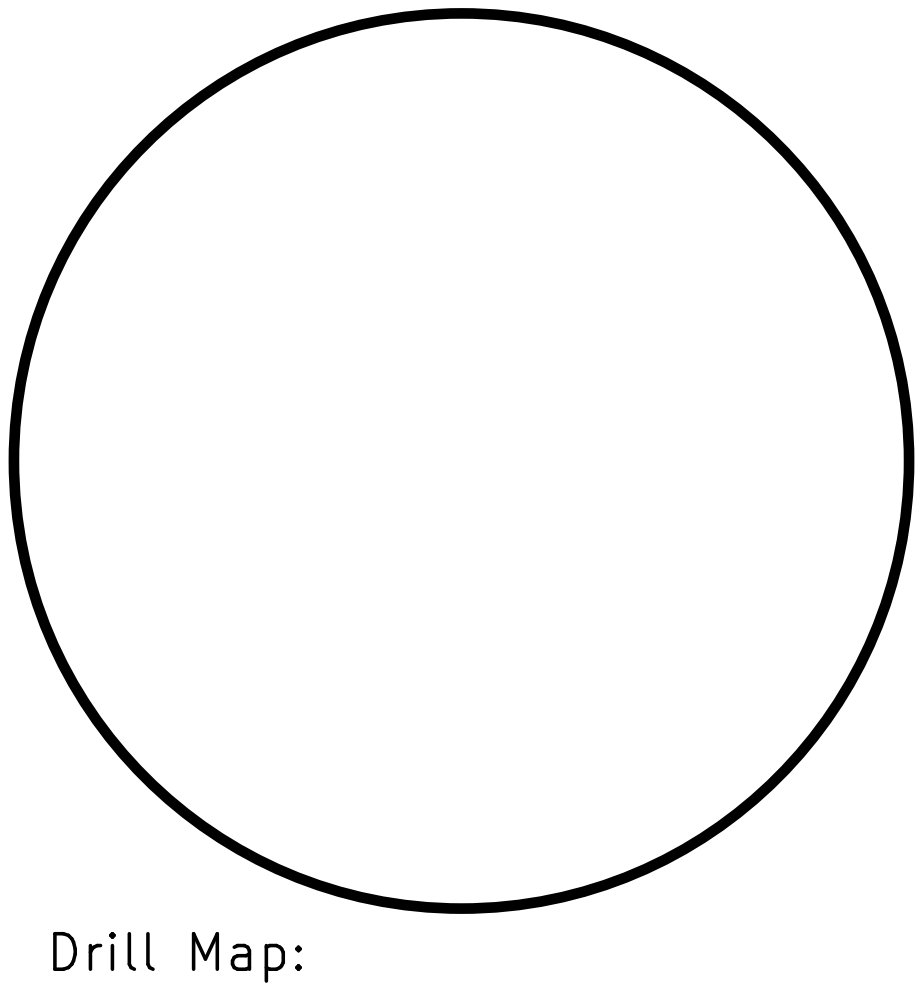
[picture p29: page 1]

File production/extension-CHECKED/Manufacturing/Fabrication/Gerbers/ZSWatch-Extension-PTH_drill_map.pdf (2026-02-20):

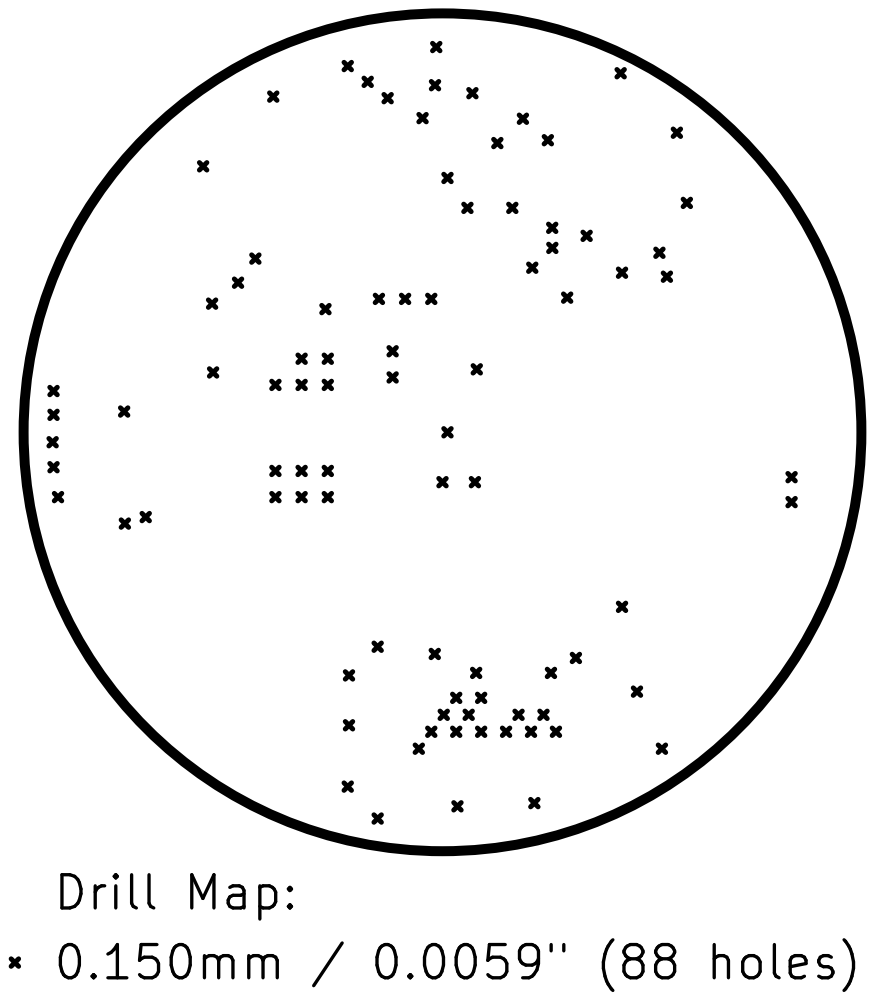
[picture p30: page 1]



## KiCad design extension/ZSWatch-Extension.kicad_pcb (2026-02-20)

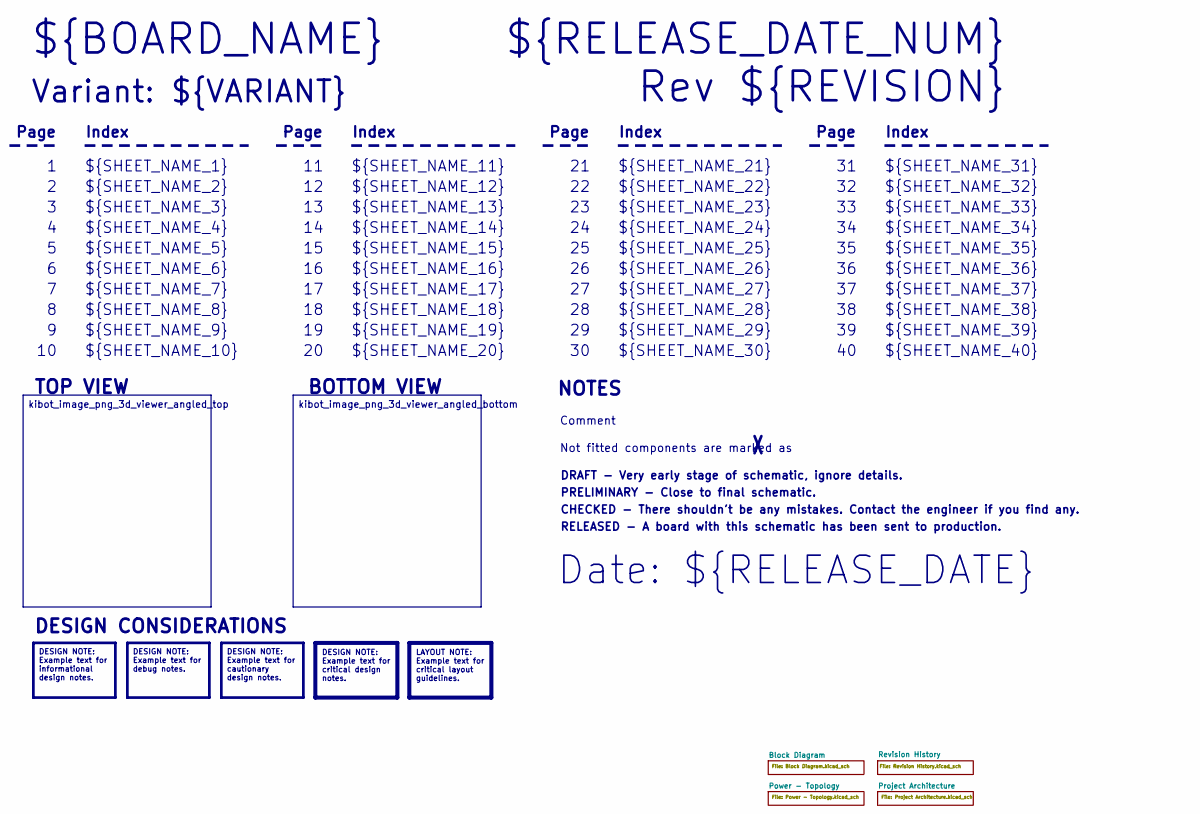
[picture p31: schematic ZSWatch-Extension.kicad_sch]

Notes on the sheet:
Variant: ${VARIANT}
RELEASED - A board with this schematic has been sent to production.
${SHEET_NAME_24}
Index
Page
PRELIMINARY - Close to final schematic.
${SHEET_NAME_22}
DRAFT - Very early stage of schematic, ignore details.
${SHEET_NAME_12}
${SHEET_NAME_8}
${SHEET_NAME_2}
${SHEET_NAME_5}
${SHEET_NAME_20}
${SHEET_NAME_23}
${RELEASE_DATE_NUM}
${SHEET_NAME_35}
Not fitted components are marked as
${SHEET_NAME_11}
${SHEET_NAME_6}
${SHEET_NAME_37}
${SHEET_NAME_26}
${SHEET_NAME_36}
Rev ${REVISION}
${SHEET_NAME_15}
CHECKED - There shouldn't be any mistakes. Contact the engineer if you find any.
BOTTOM VIEW
${SHEET_NAME_14}
${SHEET_NAME_21}
${SHEET_NAME_17}
${SHEET_NAME_18}
Date: ${RELEASE_DATE}
${SHEET_NAME_7}
${SHEET_NAME_31}
${BOARD_NAME}
NOTES
${SHEET_NAME_40}
${SHEET_NAME_39}
${SHEET_NAME_32}
${SHEET_NAME_1}
${SHEET_NAME_9}

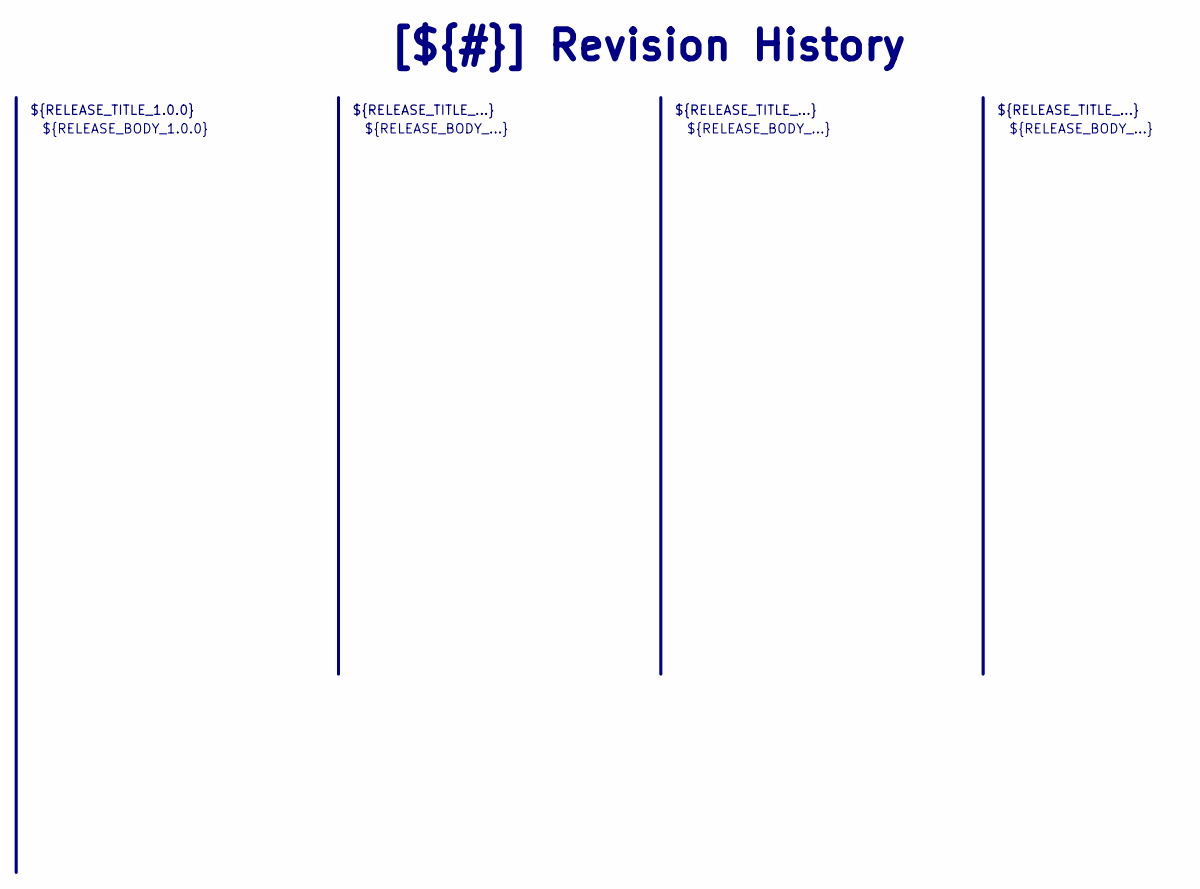
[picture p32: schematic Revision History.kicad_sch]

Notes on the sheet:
${RELEASE_BODY_...}
${RELEASE_BODY_1.0.0}
${RELEASE_TITLE_...}
[${#}] ${TITLE}
${RELEASE_TITLE_1.0.0}

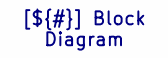
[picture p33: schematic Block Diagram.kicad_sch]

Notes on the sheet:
[${#}] ${TITLE}

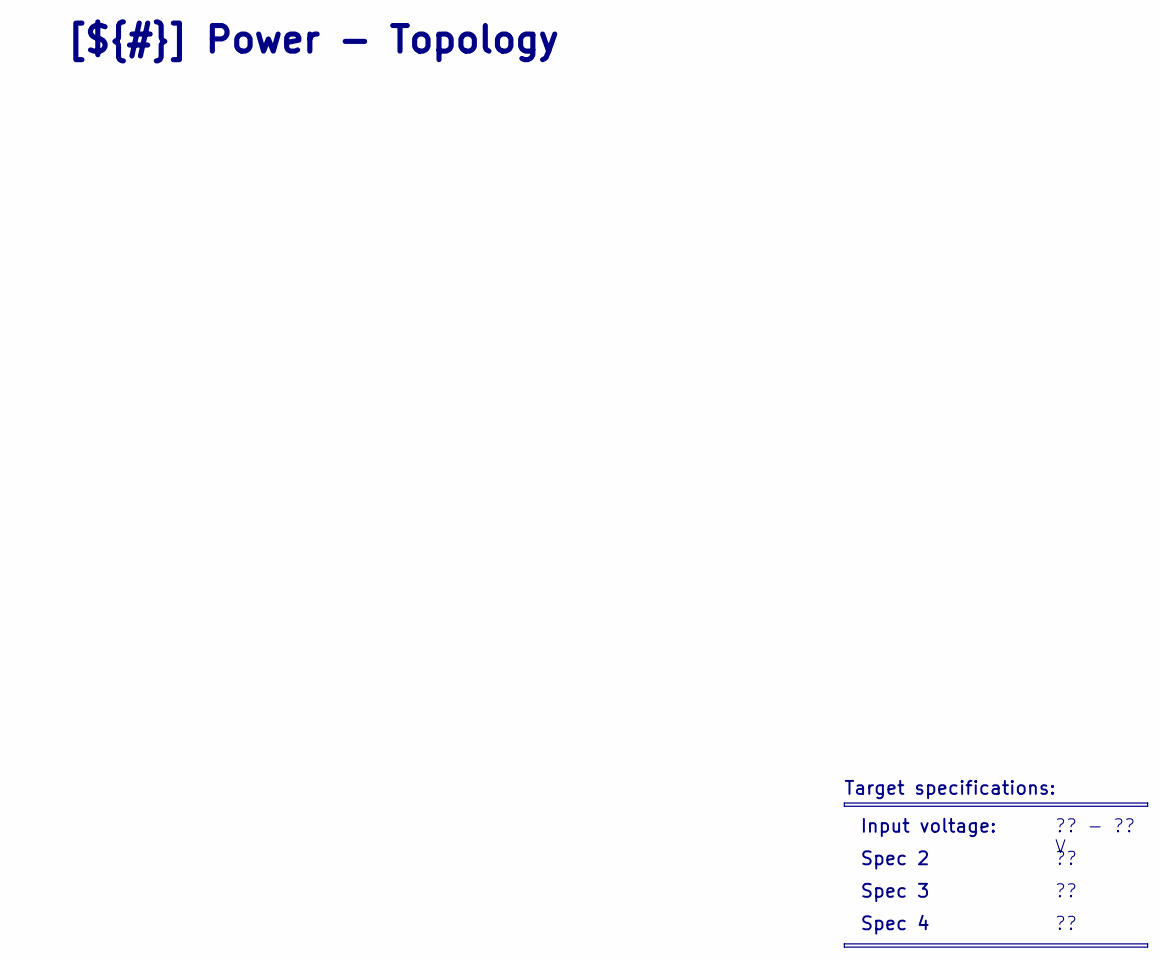
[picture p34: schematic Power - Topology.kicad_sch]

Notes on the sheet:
[${#}] ${TITLE}
Spec 2
Input voltage:
Spec 4
?? - ?? V
Target specifications:
Spec 3

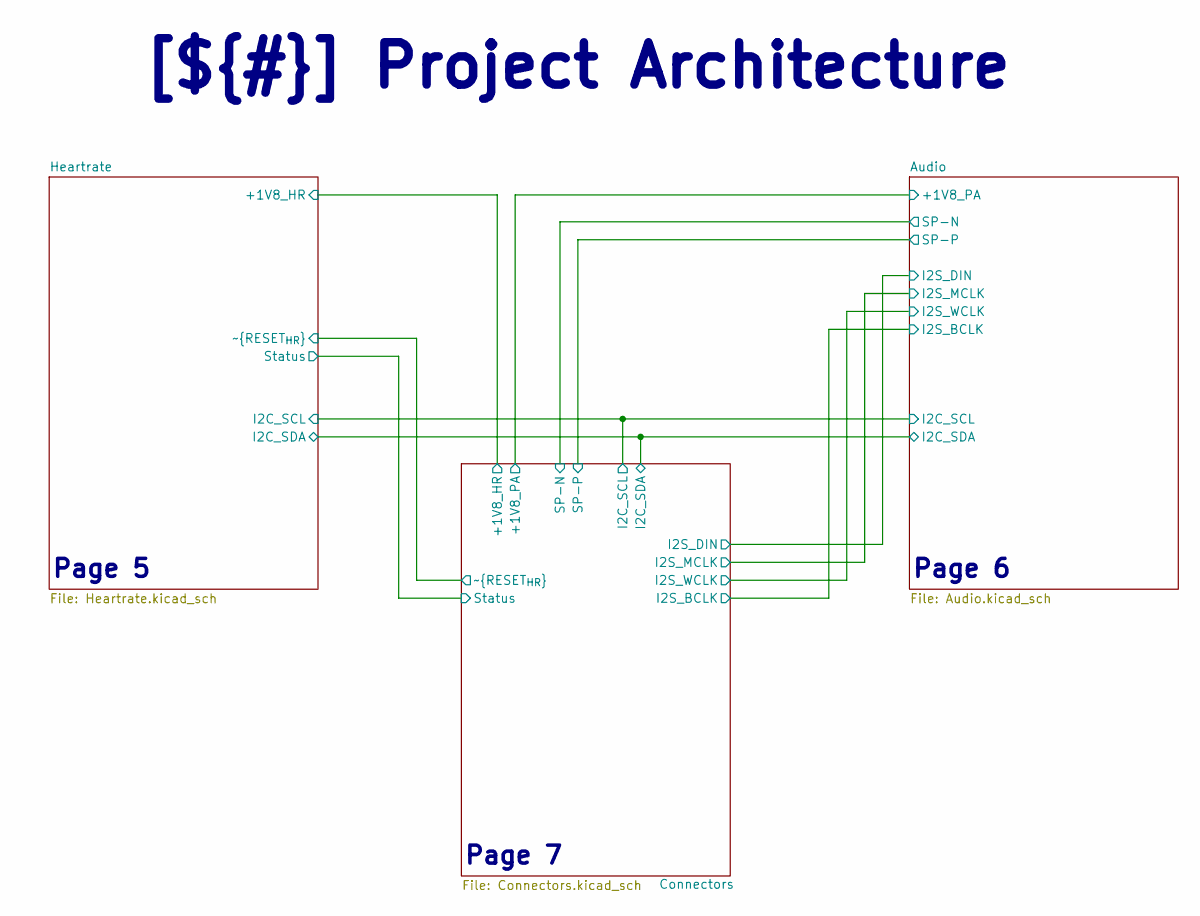
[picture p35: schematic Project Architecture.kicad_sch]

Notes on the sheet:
Page 6
Page 7
Page 5
[${#}] ${TITLE}

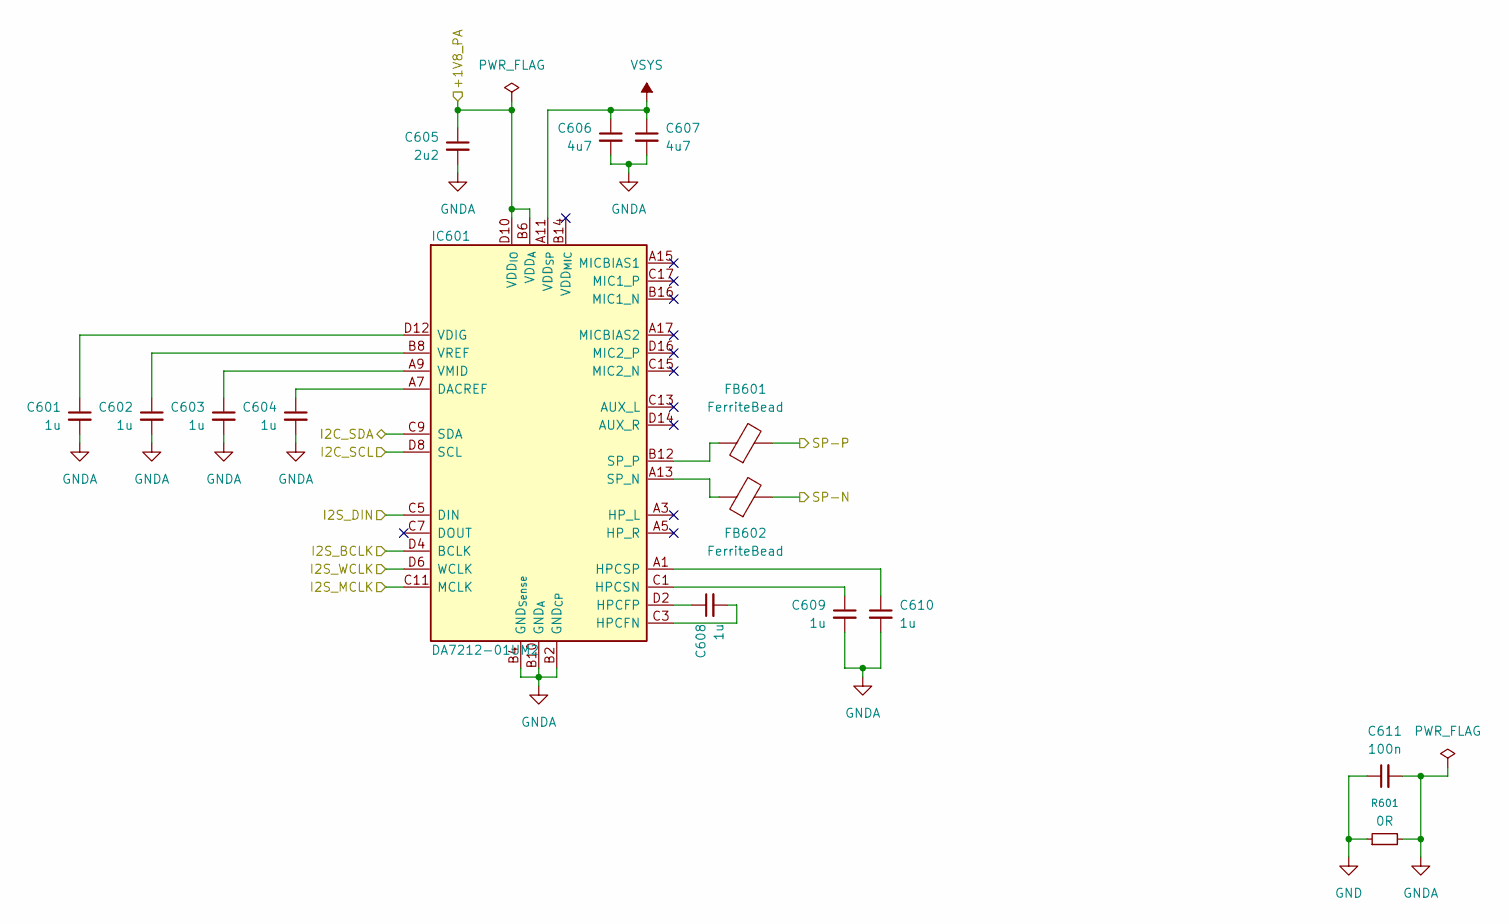
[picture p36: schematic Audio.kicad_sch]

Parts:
C601, C602, C603, C604, C608, C609, C610: 1u; C_0201_0603Metric; mouser# 581-02016W105MAT2A
C605: 2u2; C_0201_0603Metric; mouser# 581-0201ZD225MAT2A
C606, C607: 4u7; C_0201_0603Metric; mouser# 81-GRM035R60J475ME5D
C611: 100n; C_0201_0603Metric; mouser# 581-0201ZD104KAT2A
FB601, FB602: FerriteBead; L_0402_1005Metric; mouser# 81-BLM15PD121SN1D
IC601: DA7212-01UM2; WLCSP-34; mouser# 724-DA7212-01UM2
R601: 0R; R_0201_0603Metric; mouser# RC0201FR-SNE96L

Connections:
/Project Architecture/Audio/+1V8_PA: C605.1, IC601.B6 (VDD_{A}), IC601.D10 (VDD_{IO}); also elsewhere on the board
/Project Architecture/Audio/I2C_SCL: IC601.D8 (SCL); also elsewhere on the board
/Project Architecture/Audio/I2C_SDA: IC601.C9 (SDA); also elsewhere on the board
/Project Architecture/Audio/I2S_BCLK: IC601.D4 (BCLK); also elsewhere on the board
/Project Architecture/Audio/I2S_DIN: IC601.C5 (DIN); also elsewhere on the board
/Project Architecture/Audio/I2S_MCLK: IC601.C11 (MCLK); also elsewhere on the board
/Project Architecture/Audio/I2S_WCLK: IC601.D6 (WCLK); also elsewhere on the board
/Project Architecture/Audio/SP-N: FB602.2; also elsewhere on the board
/Project Architecture/Audio/SP-P: FB601.2; also elsewhere on the board
GND: C611.1, R601.1; also elsewhere on the board
GNDA: C601.2, C602.2, C603.2, C604.2, C605.2, C606.2, C607.2, C609.2, C610.2, C611.2, IC601.B2 (GND_{CP}), IC601.B4 (GND_{Sense}), IC601.B10 (GND_{A}), R601.2
unnamed: C604.1, IC601.A7 (DACREF)
unnamed: C608.2, IC601.C3 (HPCFN)
unnamed: C608.1, IC601.D2 (HPCFP)
unnamed: C609.1, IC601.C1 (HPCSN)
unnamed: C610.1, IC601.A1 (HPCSP)
unnamed: FB602.1, IC601.A13 (SP_N)
unnamed: FB601.1, IC601.B12 (SP_P)
unnamed: C601.1, IC601.D12 (VDIG)
unnamed: C603.1, IC601.A9 (VMID)
unnamed: C602.1, IC601.B8 (VREF)
VSYS: C606.1, C607.1, IC601.A11 (VDD_{SP}); also elsewhere on the board

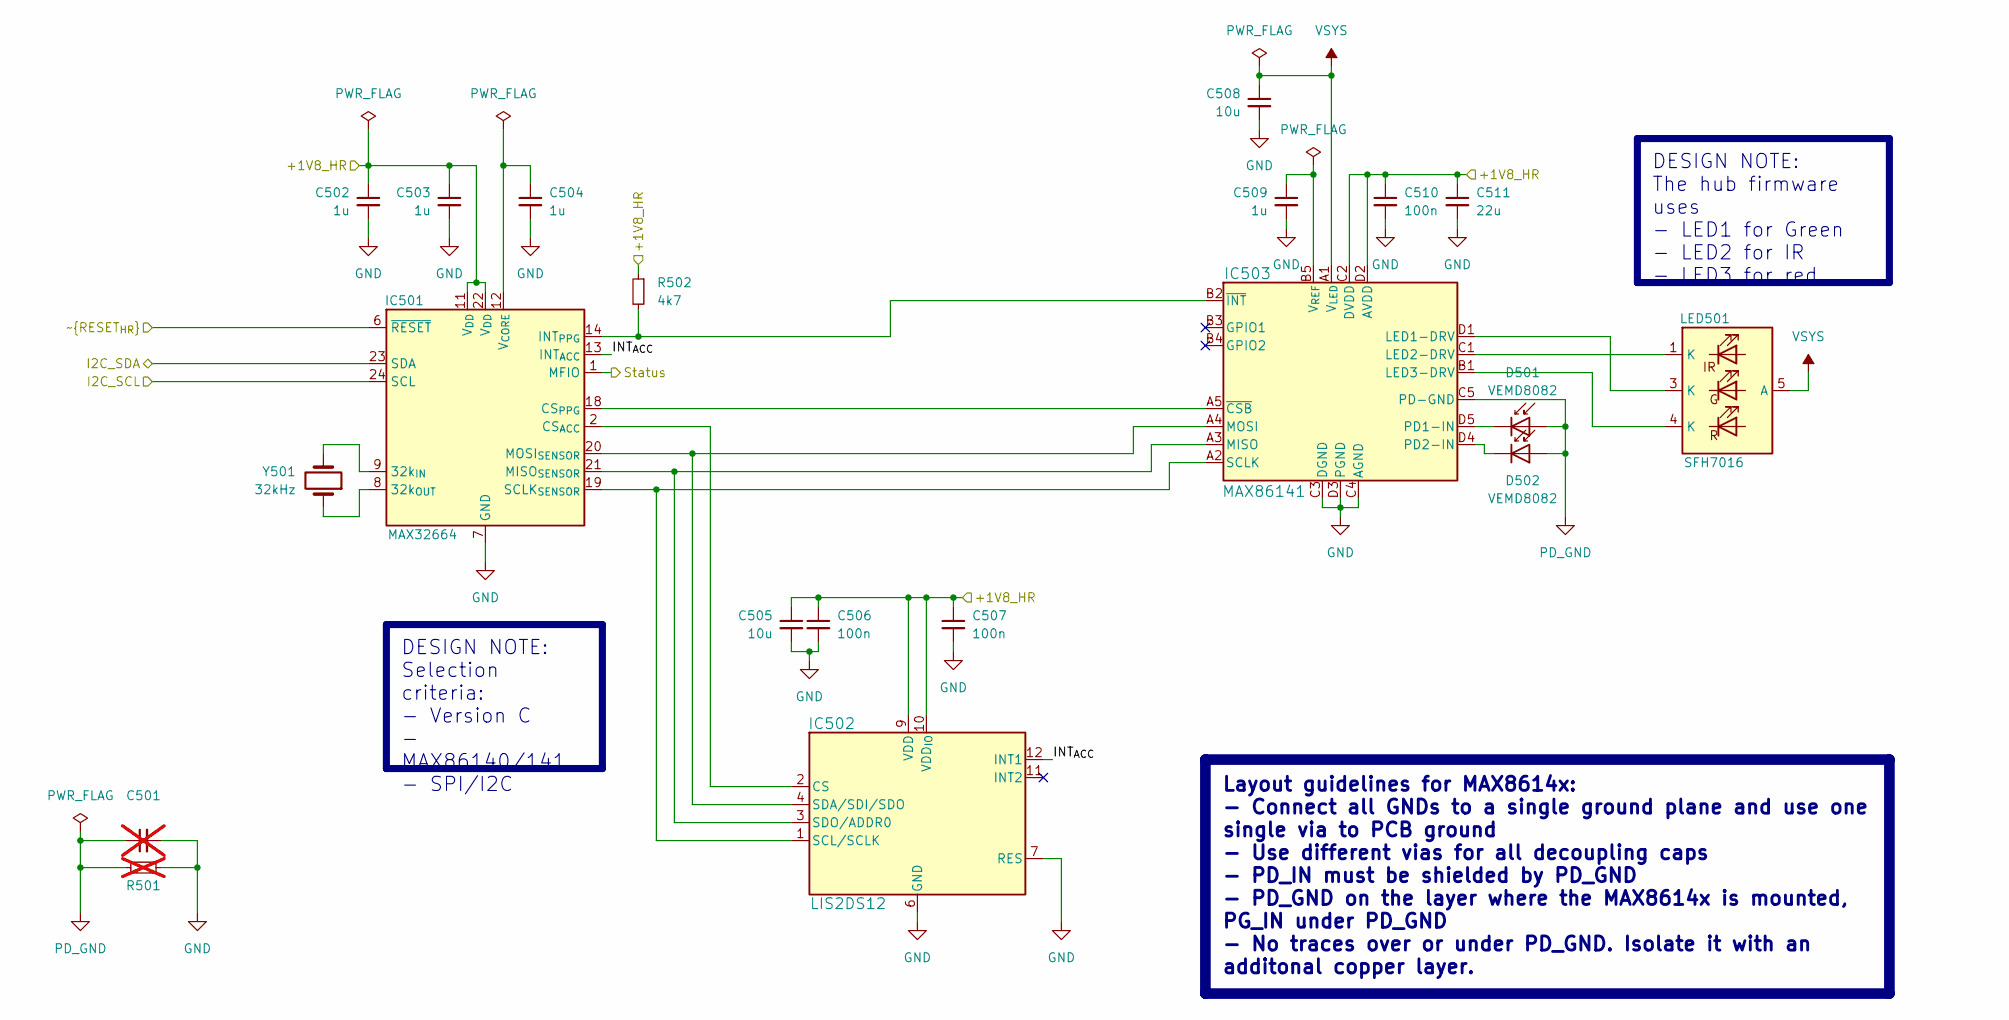
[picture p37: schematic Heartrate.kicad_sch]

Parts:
C501: C_0201_0603Metric; not fitted
C502, C503, C504, C509: 1u; C_0201_0603Metric; mouser# 581-02016W105MAT2A
C505, C508: 10u; C_0201_0603Metric; mouser# 581-KGM03DR50G106MH
C506, C507, C510: 100n; C_0201_0603Metric; mouser# 581-0201ZD104KAT2A
C511: 22u; C_0402_1005Metric; mouser# 581-04026D226MAT2A
D501, D502: VEMD8082; VEMD808x; mouser# 78-VEMD8082
IC501: MAX32664; MAX32664GTG; mouser# 700-MAX32664GTGC+
IC502: LIS2DS12; LGA-12_2x2mm_P0.5mm; mouser# 511-LIS2DS12
IC503: MAX86141; THIN-WLP-20_2.228x1.967mm_P0.4mm; mouser# 700-MAX86141ENP+T
LED501: SFH7016; mouser# 720-SFH7016
R501: R_0201_0603Metric; not fitted
R502: 4k7; L_0201_0603Metric; mouser# 71-CRCW020147K5FNED
Y501: 32kHz; ECS_ECX-1210; mouser# 520-.327-6-1210-TR

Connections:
/Project Architecture/Audio/I2C_SCL: IC501.24 (SCL); also elsewhere on the board
/Project Architecture/Audio/I2C_SDA: IC501.23 (SDA); also elsewhere on the board
/Project Architecture/Connectors/+1V8_HR: C502.1, C503.1, C505.1, C506.1, C507.1, C510.1, C511.1, IC501.11 (V_{DD}), IC501.22 (V_{DD}), IC502.9 (VDD), IC502.10 (VDD_{IO}), IC503.C2 (DVDD), IC503.D2 (AVDD), R502.1; also elsewhere on the board
/Project Architecture/Connectors/Status: IC501.1 (MFIO); also elsewhere on the board
/Project Architecture/Connectors/~RESET_{HR}: IC501.6 (~RESET); also elsewhere on the board
/Project Architecture/Heartrate/INT_{ACC}: IC501.13 (INT_{ACC}), IC502.12 (INT1)
GND: C501.2, C502.2, C503.2, C504.2, C505.2, C506.2, C507.2, C508.2, C509.2, C510.2, C511.2, IC501.7 (GND), IC501.10 (GND), IC502.6 (GND), IC502.7 (RES), IC502.8 (GND), IC503.C3 (DGND), IC503.C4 (AGND), IC503.D3 (PGND), R501.2; also elsewhere on the board
unnamed: D501.1 (K), IC503.D5 (PD1-IN)
unnamed: D502.1 (K), IC503.D4 (PD2-IN)
unnamed: IC501.9 (32k_{IN}), Y501.2
unnamed: IC501.8 (32k_{OUT}), Y501.1
unnamed: IC501.2 (CS_{ACC}), IC502.2 (CS)
unnamed: IC501.18 (CS_{PPG}), IC503.A5 (~CSB)
unnamed: IC501.14 (INT_{PPG}), IC503.B2 (~INT), R502.2
unnamed: IC501.21 (MISO_{SENSOR}), IC502.3 (SDO/ADDR0), IC503.A3 (MISO)
unnamed: IC501.20 (MOSI_{SENSOR}), IC502.4 (SDA/SDI/SDO), IC503.A4 (MOSI)
unnamed: IC501.19 (SCLK_{SENSOR}), IC502.1 (SCL/SCLK), IC503.A2 (SCLK)
unnamed: C504.1, IC501.12 (V_{CORE})
unnamed: IC503.D1 (LED1-DRV), LED501.3 (K)
unnamed: IC503.C1 (LED2-DRV), LED501.1 (K)
unnamed: IC503.B1 (LED3-DRV), LED501.4 (K)
unnamed: C509.1, IC503.B5 (V_{REF})
PD_GND: C501.1, D501.2 (A), D502.2 (A), IC503.C5 (PD-GND), R501.1
VSYS: C508.1, IC503.A1 (V_{LED}), LED501.2 (A), LED501.5 (A); also elsewhere on the board

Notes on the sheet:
DESIGN NOTE: Selection criteria: - Version C - MAX86140/141 - SPI/I2C
DESIGN NOTE: The hub firmware uses - LED1 for Green - LED2 for IR - LED3 for red
Layout guidelines for MAX8614x: - Connect all GNDs to a single ground plane and use one single via to PCB ground - Use different vias for all decoupling caps - PD_IN must be shielded by PD_GND - PD_GND on the layer where the MAX8614x is mounted, PG_IN under PD_GND - No traces over or under PD_GND. 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

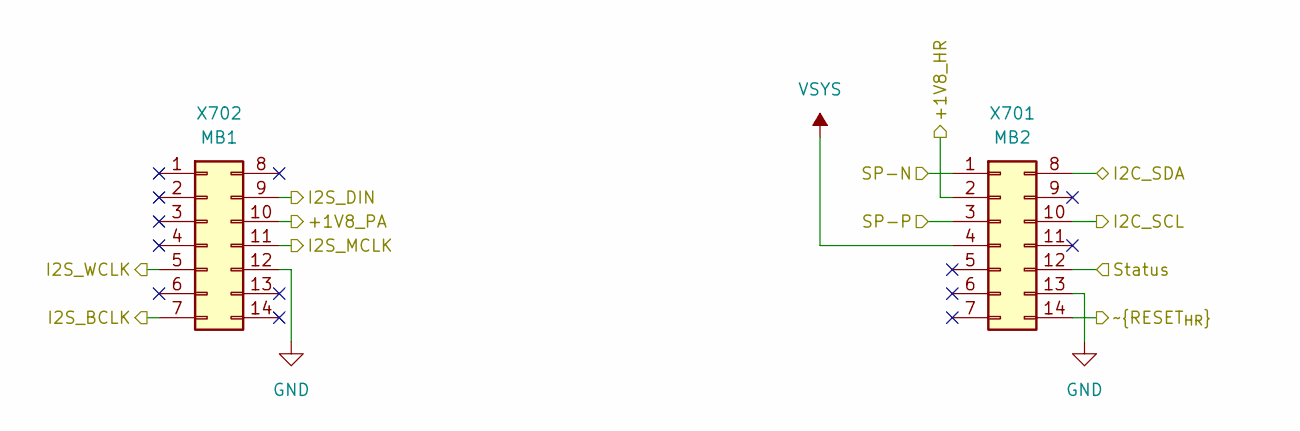
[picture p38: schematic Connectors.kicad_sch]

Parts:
X701: MB2; 101P014FB110; mouser# 649-101P014FB110
X702: MB1; 101P014FB110; mouser# 649-101P014FB110

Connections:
/Project Architecture/Audio/+1V8_PA: X702.10; also elsewhere on the board
/Project Architecture/Audio/I2C_SCL: X701.10; also elsewhere on the board
/Project Architecture/Audio/I2C_SDA: X701.8; also elsewhere on the board
/Project Architecture/Audio/I2S_BCLK: X702.7; also elsewhere on the board
/Project Architecture/Audio/I2S_DIN: X702.9; also elsewhere on the board
/Project Architecture/Audio/I2S_MCLK: X702.11; also elsewhere on the board
/Project Architecture/Audio/I2S_WCLK: X702.5; also elsewhere on the board
/Project Architecture/Audio/SP-N: X701.1; also elsewhere on the board
/Project Architecture/Audio/SP-P: X701.3; also elsewhere on the board
/Project Architecture/Connectors/+1V8_HR: X701.2; also elsewhere on the board
/Project Architecture/Connectors/Status: X701.12; also elsewhere on the board
/Project Architecture/Connectors/~RESET_{HR}: X701.14; also elsewhere on the board
GND: X701.13, X702.12; also elsewhere on the board
VSYS: X701.4; also elsewhere on the board

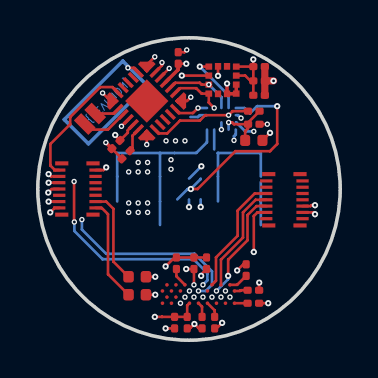
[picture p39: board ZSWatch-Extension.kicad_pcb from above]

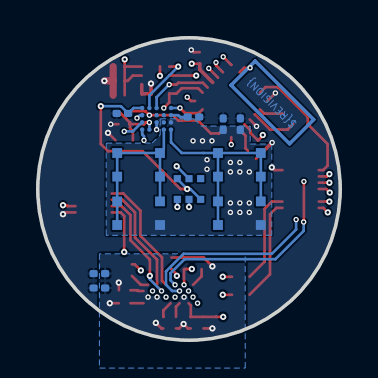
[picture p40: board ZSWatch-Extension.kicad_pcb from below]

Board: 4 copper layers, 16.8 x 16.8 mm, 37 parts (10 on the bottom side), 42 nets.

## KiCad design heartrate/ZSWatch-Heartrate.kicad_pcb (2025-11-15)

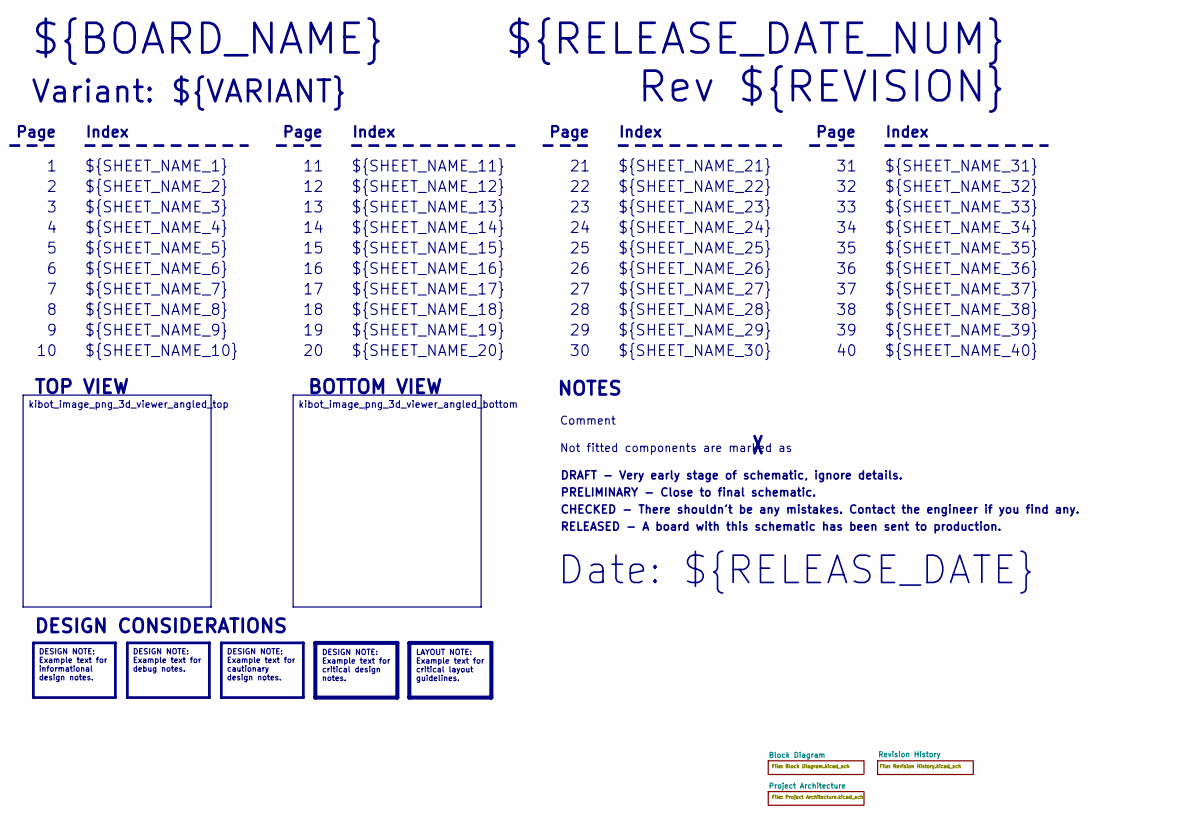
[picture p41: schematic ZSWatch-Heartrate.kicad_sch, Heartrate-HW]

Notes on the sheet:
Variant: ${VARIANT}
RELEASED - A board with this schematic has been sent to production.
${SHEET_NAME_24}
Index
Page
PRELIMINARY - Close to final schematic.
${SHEET_NAME_22}
DRAFT - Very early stage of schematic, ignore details.
${SHEET_NAME_12}
${SHEET_NAME_8}
${SHEET_NAME_2}
${SHEET_NAME_5}
${SHEET_NAME_20}
${SHEET_NAME_23}
${RELEASE_DATE_NUM}
${SHEET_NAME_35}
Not fitted components are marked as
${SHEET_NAME_11}
${SHEET_NAME_6}
${SHEET_NAME_37}
${SHEET_NAME_26}
${SHEET_NAME_36}
Rev ${REVISION}
${SHEET_NAME_15}
CHECKED - There shouldn't be any mistakes. Contact the engineer if you find any.
BOTTOM VIEW
${SHEET_NAME_14}
${SHEET_NAME_21}
${SHEET_NAME_17}
${SHEET_NAME_18}
Date: ${RELEASE_DATE}
${SHEET_NAME_7}
${SHEET_NAME_31}
${BOARD_NAME}
NOTES
${SHEET_NAME_40}
${SHEET_NAME_39}
${SHEET_NAME_32}
${SHEET_NAME_1}
${SHEET_NAME_9}

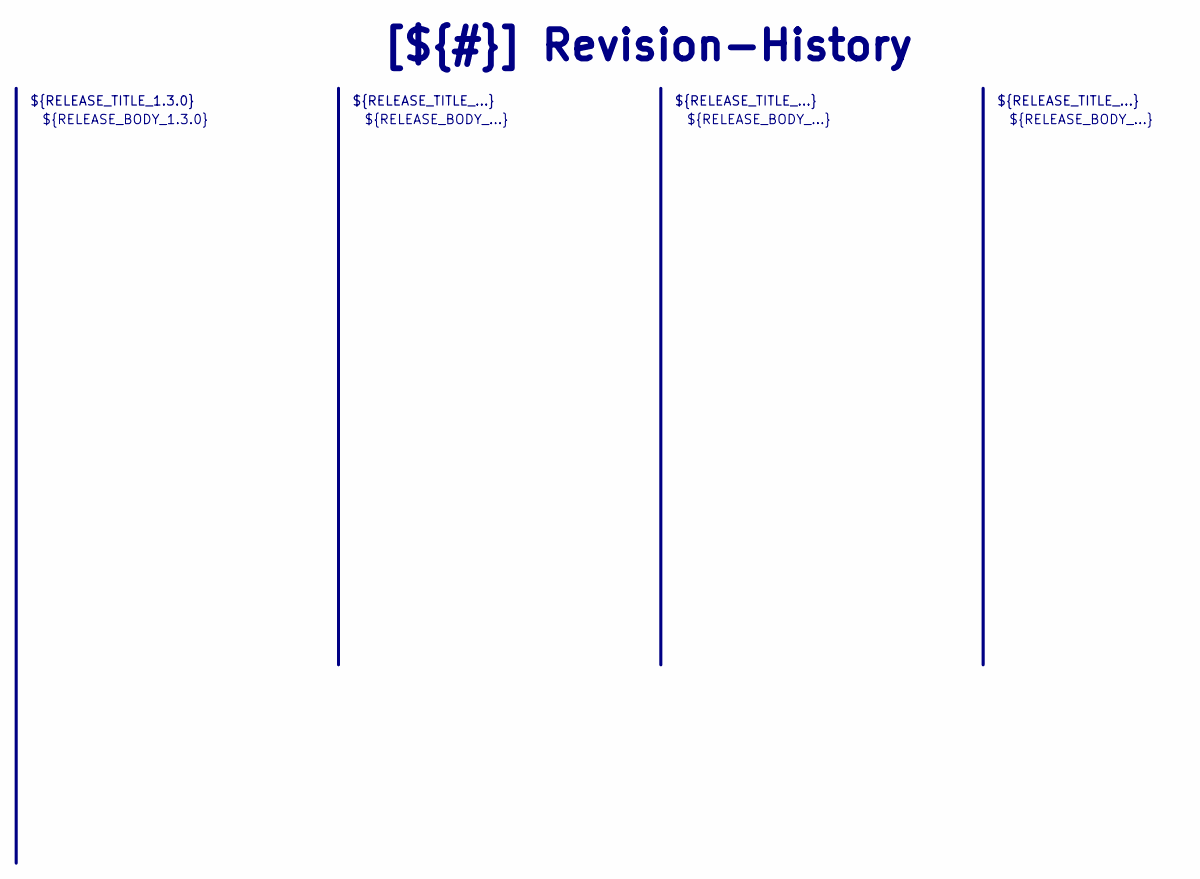
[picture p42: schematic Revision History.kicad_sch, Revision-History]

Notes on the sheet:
${RELEASE_BODY_...}
[${#}] ${TITLE}
${RELEASE_BODY_1.3.0}
${RELEASE_TITLE_...}
${RELEASE_TITLE_1.3.0}


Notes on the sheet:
Spec 4
+5 V
[${#}] ${TITLE}
Input voltage:
Target specifications:
Spec 3
Spec 2


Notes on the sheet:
Page 4

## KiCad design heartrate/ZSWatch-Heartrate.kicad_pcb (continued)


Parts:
C401: 2u2; C_0603_1608Metric; mouser# 581-06033D225MAT2A
C402, C404: 1u; C_0603_1608Metric; mouser# 581-06035C105MAT2A
C403, C405, C407: 4u7; C_0603_1608Metric; mouser# 963-LMK107BJ475KA-T
C406, C414, C415, C416: 100n; C_0402_1005Metric; mouser# 80-C0402C104K4R7411
C408, C409, C410, C413: 1u; C_0402_1005Metric; mouser# 581-04023D105KAT2A
C411, C412: 10u; C_0402_1005Metric; mouser# 963-AMK105CBJ106MV-F
C417: 22u; C_0402_1005Metric; mouser# 963-MEASP105CC62261A
C418: C_0402_1005Metric; not fitted
D401: STATUS; LED_0805_2012Metric_Pad1.15x1.40mm_HandSolder; mouser# 630-HSMQ-C170-T0000
D402, D403: VEMD8082; VEMD808x; mouser# 78-VEMD8082
IC401: MIC5365-1.8; SOT-23-5; mouser# 998- MIC5365-1.8YD5-TR
IC402: TPS61240; DSBGA-6_0.886x1.288mm_2x3_P0.4mm; mouser# 595-TPS61240YFFR
IC403: MCP73832-2-OT; SOT-23-5; mouser# 579-MCP73832T-2ACI/OT
IC404: MAX32664; MAX32664GTG; mouser# 700-MAX32664GTGC+
IC405: MAX86141; THIN-WLP-20_2.228x1.967mm_P0.4mm; mouser# 700-MAX86141ENP+T
IC406: LIS2DS12; LGA-12_2x2mm_P0.5mm; mouser# 511-LIS2DS12
J401: I2C; PinHeader_1x04_P2.54mm_Vertical; not fitted
J402: SPI; PinHeader_1x07_P2.54mm_Vertical; not fitted
L401: 1u; L_0603_1608Metric; mouser# 815-ASMCI-0603-1R0MT
LED401: SFH7016; mouser# 720-SFH7016
M401: BM15C; mouser# 308-BM15C
Q401: BSS138; SOT-23; mouser# 512-BSS138
R401: 220R; R_0402_1005Metric; mouser# 652-CR0402-JW-221GLF
R402, R406, R407, R408: 10k; R_0402_1005Metric; mouser# 652-CR0402-JW-103GLF
R403: 0R; R_0805_2012Metric; mouser# 71-CRCW08050000Z0EBC
R404, R405: 5k1; R_0402_1005Metric; mouser# 652-CR0402-FX-5101GLF
R409: 4k7; R_0402_1005Metric; mouser# 603-RC0402FR-7D4K7L
R410: R_0402_1005Metric; not fitted
SW401: RESET; WS-TASV-6x6; mouser# 710-430182095816
SW402: BTN1; WS-TASV-6x6; mouser# 710-430182095816
X401: CHARGE; USB_C_Receptacle_GCT_USB4105-xx-A_16P_TopMnt_Horizontal; mouser# 640-USB4105-GF-A-120
X402: BATTERY; 78171-0002; mouser# 538-78171-0002
X403: DEBUG; PinHeader_2x05_P1.27mm_Vertical; mouser# 710-623310235521
Y401: 32kHz; ECS_ECX-1210; mouser# 520-.327-6-1210-TR

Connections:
+1V8: C404.1, C406.1, C408.1, C409.1, C411.1, C414.1, C415.1, C416.1, C417.1, IC401.5 (OUT), IC404.11 (V_{DD}), IC404.22 (V_{DD}), IC405.C2 (DVDD), IC405.D2 (AVDD), IC406.9 (VDD), IC406.10 (VDD_{IO}), M401.B8 (VDD), M401.C8 (VDD), R402.1, R407.2, R409.1, X403.1 (VTref)
/Project Architecture/Main/CHARGE: IC403.1 (STAT), M401.K5 (P2.10), R407.1
/Project Architecture/Main/ENABLE_{LED}: IC402.C1 (EN), R403.2
/Project Architecture/Main/INT_{ACC}: IC404.13 (INT_{ACC}), IC406.12 (INT1)
/Project Architecture/Main/SCL: IC404.24 (SCL), J401.2, M401.G8 (P1.08)
/Project Architecture/Main/SDA: IC404.23 (SDA), J401.1, M401.G9 (P1.07/AIN3)
/Project Architecture/Main/STATUS: IC404.1 (MFIO), J402.7, M401.J9 (P2.01)
/Project Architecture/Main/SWDCLK: M401.K3 (SWDCLK), X403.4 (SWCLK/TCK)
/Project Architecture/Main/SWDIO: M401.J3 (SWDIO), X403.2 (SWDIO/TMS)
/Project Architecture/Main/V_{BAT}: C401.1, C402.1, C407.1, IC401.1 (IN), IC401.3 (EN), IC402.A1 (IN), IC403.3 (V_{BAT}), L401.1, R401.1, X402.1
/Project Architecture/Main/V_{LED}: C403.1, C412.1, IC402.B2 (OUT), IC402.C2 (FB), IC405.A1 (V_{LED}), LED401.2 (A), LED401.5 (A)
/Project Architecture/Main/~RESET_{HR}: IC404.6 (~RESET), J401.3, M401.H9 (P2.00), R408.1
/Project Architecture/Main/~RESET: M401.G2 (~RESET), R402.2, SW401.1, SW401.3, X403.10 (~RESET)
GND: C401.2, C402.2, C403.2, C404.2, C405.2, C406.2, C407.2, C408.2, C409.2, C410.2, C411.2, C412.2, C413.2, C414.2, C415.2, C416.2, C417.2, C418.2, IC401.2 (GND), IC402.A2 (GND), IC403.2 (V_{SS}), IC404.7 (GND), IC404.10 (GND), IC405.C3 (DGND), IC405.C4 (AGND), IC405.D3 (PGND), IC406.6 (GND), IC406.7 (RES), IC406.8 (GND), J401.4, J402.1, M401.A1 (GND), M401.A9 (GND), M401.B1 (GND), M401.B7 (GND), M401.B9 (GND), M401.D1 (GND), M401.E1 (GND), M401.F1 (GND), M401.H8 (GND), Q401.2 (S), R404.2, R405.1, R406.2, R408.2, R410.2, SW401.2, SW401.4, SW402.1, SW402.3, X401.A1 (GND), X401.A12 (GND), X401.B1 (GND), X401.B12 (GND), X401.S1 (SHIELD), X402.2, X403.3 (GND), X403.5 (GND)
unnamed: D401.2 (A), R401.2
unnamed: D401.1 (K), Q401.3 (D)
unnamed: D402.1 (K), IC405.D5 (PD1-IN)
unnamed: D403.1 (K), IC405.D4 (PD2-IN)
unnamed: IC402.B1 (L), L401.2
unnamed: IC403.5 (PROG), R406.1
unnamed: C405.1, IC403.4 (V_{DD}), X401.A4 (VBUS), X401.A9 (VBUS), X401.B4 (VBUS), X401.B9 (VBUS)
unnamed: IC404.9 (32k_{IN}), Y401.2
unnamed: IC404.8 (32k_{OUT}), Y401.1
unnamed: IC404.2 (CS_{ACC}), IC406.2 (CS), J402.6
unnamed: IC404.18 (CS_{PPG}), IC405.A5 (~CSB), J402.5
unnamed: IC404.14 (INT_{PPG}), IC405.B2 (~INT), R409.2
unnamed: IC404.21 (MISO_{SENSOR}), IC405.A3 (MISO), IC406.3 (SDO/ADDR0), J402.3
unnamed: IC404.20 (MOSI_{SENSOR}), IC405.A4 (MOSI), IC406.4 (SDA/SDI/SDO), J402.4
unnamed: IC404.19 (SCLK_{SENSOR}), IC405.A2 (SCLK), IC406.1 (SCL/SCLK), J402.2
unnamed: C410.1, IC404.12 (V_{CORE})
unnamed: IC405.D1 (LED1-DRV), LED401.3 (K)
unnamed: IC405.C1 (LED2-DRV), LED401.1 (K)
unnamed: IC405.B1 (LED3-DRV), LED401.4 (K)
unnamed: C413.1, IC405.B5 (V_{REF})
unnamed: M401.K4 (P0.01), R403.1
unnamed: M401.K2 (P0.02), Q401.1 (G)
unnamed: M401.J7 (P2.03), SW402.2, SW402.4
unnamed: R404.1, X401.A5 (CC1)
unnamed: R405.2, X401.B5 (CC2)
PD_GND: C418.1, D402.2 (A), D403.2 (A), IC405.C5 (PD-GND), R410.1

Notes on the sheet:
The hub firmware uses - LED1 for Green - LED2 for IR - LED3 for red
NOTE: Only this pins are working for I2C!
Layout guidelines for MAX8614x: - Connect all GNDs to a single ground plane and use one single via to PCB ground - Use different vias for all decoupling caps - PD_IN must be shielded by PD_GND - PD_GND on the layer where the MAX8614x is mounted, PG_IN under PD_GND - No traces over or under PD_GND



Board: 4 copper layers, 45.0 x 36.9 mm, 49 parts (5 on the bottom side), 40 nets.

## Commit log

2025-11-15 Initialize development branch for version 1.0.0
    [Block Diagram.kicad_sch, Main.kicad_sch, Project Architecture.kicad_sch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]
2025-11-21 First version done
    [Main.kicad_sch, ZSWatch-Extension.kicad_pcb]
2025-12-11 Reduce radius to 8.4 mm
    [Connectors.kicad_sch, ZSWatch-Extension.kicad_pcb]
2025-12-11 New connector positions
    [ZSWatch-Extension.kicad_pcb]
2026-02-20 Prepare release 1.0.0
    [Audio.kicad_sch, Block Diagram.kicad_sch, Connectors.kicad_sch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]
2026-02-20 Push outputs from CI/CD (2026-02-20 14:31:25)
    [ZSWatch-Extension-(L1-L4)_drill_table.csv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]
2026-02-20 Push outputs from CI/CD (2026-02-20 14:40:36)
    [ZSWatch-Extension-(L1-L4)_drill_table.csv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]
2026-02-20 Update outputs (release)
    [ZSWatch-Extension-(L1-L4)_drill_table.csv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]
2026-02-20 Push outputs from CI/CD (2026-02-20 15:14:02)
    [ZSWatch-Extension-B_Cu.gbr, ZSWatch-Extension-B_Mask.gbr, ZSWatch-Extension-B_Paste.gbr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]
